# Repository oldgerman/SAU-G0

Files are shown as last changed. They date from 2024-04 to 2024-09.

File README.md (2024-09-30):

## SAU-G0

> 某存在感很弱的屑温湿度计（），美其名曰 Sensor Acquisition Unit（传感器采集单元）

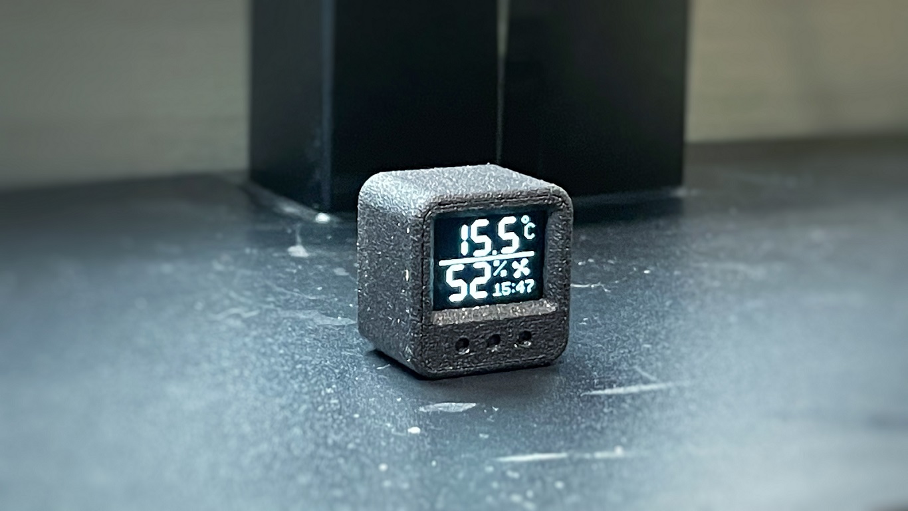
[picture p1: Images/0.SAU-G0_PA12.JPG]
0.SAU-G0_PA12


- [1. 简介](#1-简介)
- [2. 续航](#2-续航)
  - [最低电流](#最低电流)
  - [最高电流](#最高电流)
  - [理论续航时间](#理论续航时间)
- [3. PCB](#3-pcb)
  - [SAU-G0（主控板）](#sau-g0主控板)
  - [SAU-G0-EX_AHT-GL（拓展版-AHT温湿度计-普通级）](#sau-g0-ex_aht-gl拓展版-aht温湿度计-普通级)
  - [SAU-G0-EX_AHT-PL（拓展版-AHT温湿度计-精准级）](#sau-g0-ex_aht-pl拓展版-aht温湿度计-精准级)
  - [SAU-G0-EX_microSD（拓展版-microSD）](#sau-g0-ex_microsd拓展版-microsd)
- [4. 焊接](#4-焊接)
- [5. BOM](#5-bom)
- [6. 软件](#6-软件)
  - [搭建环境](#搭建环境)
  - [功能进度](#功能进度)
  - [BUG fix progress](#bug-fix-progress)
- [7. 烧录](#7-烧录)
  - [ST-LINK](#st-link)
  - [ISP](#isp)
- [8. 成品](#8-成品)
- [9. 数据采集测试](#9-数据采集测试)
- [10. Acknowledgments](#10-acknowledgments)

## 1. 简介

SAU-G0（Sensor Acquisition Uinit（传感器采集单元），基于STM32G031G8U6，是本id学习低功耗的试水作品

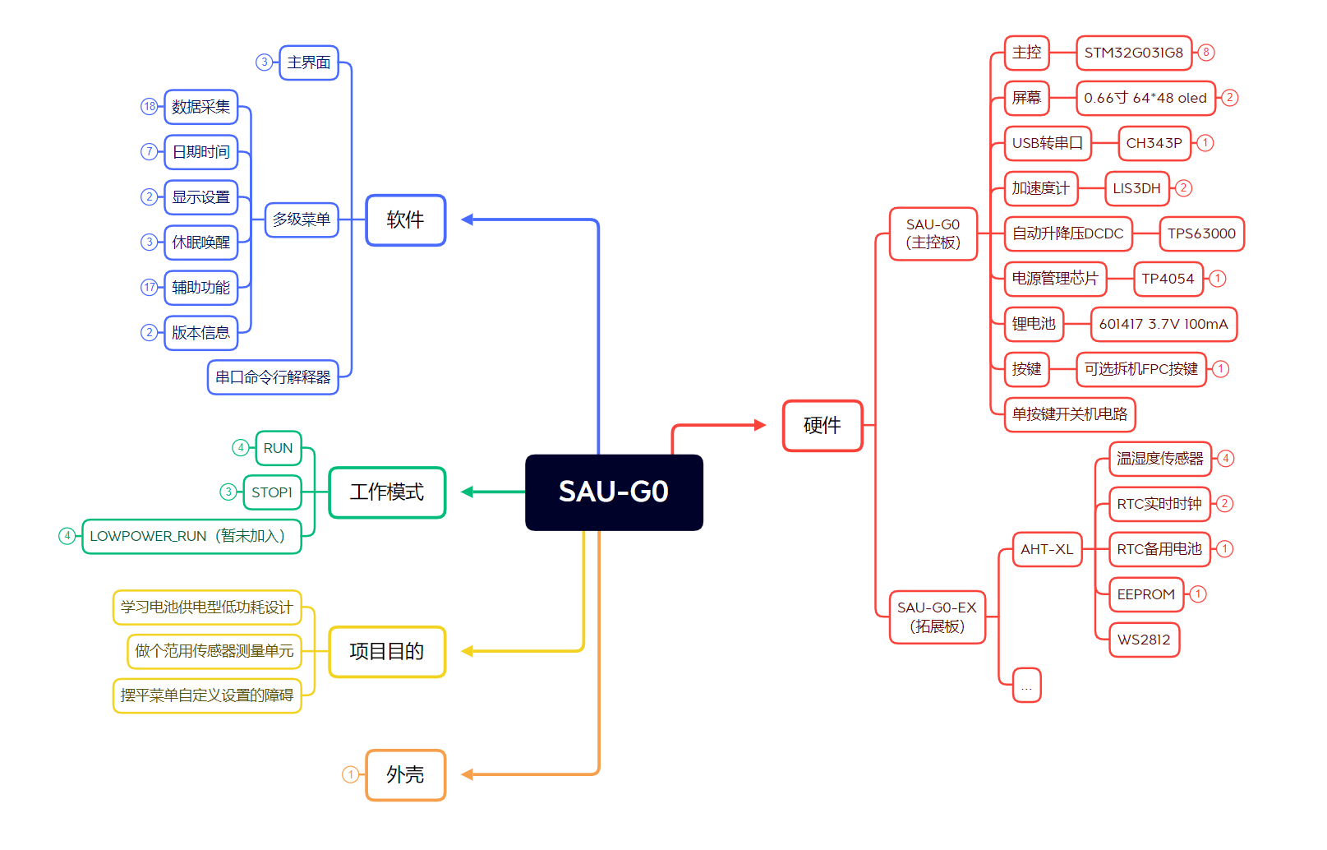
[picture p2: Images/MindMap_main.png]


## 2. 续航

### 最低电流

休眠：约8uA

亮屏运行：约4.0mA（1%屏幕亮度，WS2812不供电）

### 最高电流

最大电流30mA以上（OLED屏幕亮度100%，WS2812两通道LED亮度100%）

### 理论续航时间

使用CubeMX tools工具粗略计算（未引入唤醒瞬间的电流）：1%的时间运行，99%的时间休眠，每天运行864秒（屏幕亮度为1%），其他时间休眠，那么100mA锂电池极限续航2个月7天

如果每10分钟采集温湿度数据一次，每天采集144次，每次5秒，每天耗时720秒，还剩余144秒可支持每天以1%的亮度亮屏2分钟

每组带两位小数的温湿度数据占用4byte（16bit + 16bit），每天储存576byte数据，2个月采集温湿度数据8640组，占用34560byte空间（需使用24C512 EEPROM（65536byte）存储）

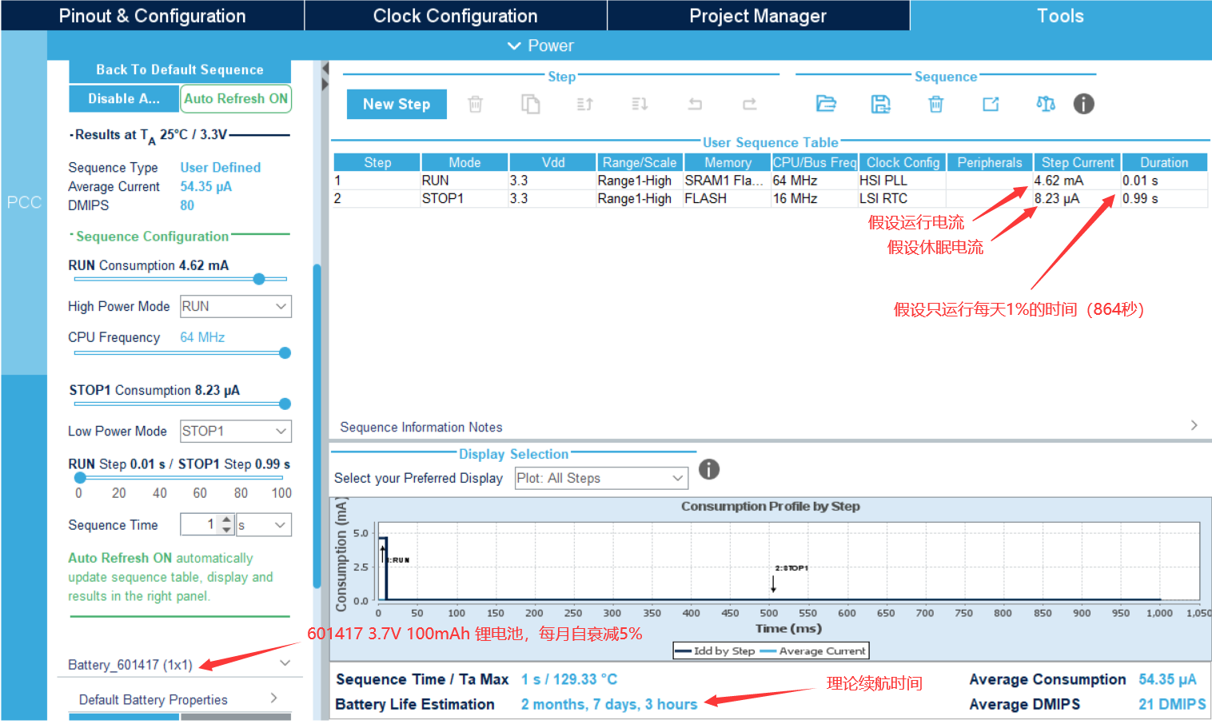
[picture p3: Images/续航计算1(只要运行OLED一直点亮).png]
续航计算1(只要运行OLED一直点亮)


## 3. PCB

> PCB采用叠板设计，分为主控板与拓展板，具体应用取决于拓展板上的传感器和存储芯片，你可以绘制自己的拓展板写驱动程序

### SAU-G0（主控板）

- 硬件：STM32G031G8U6 + CH343P + LIS3DH + TPS63000 / TPS63001 + TP4054 / MCP73831-2ATI/OT

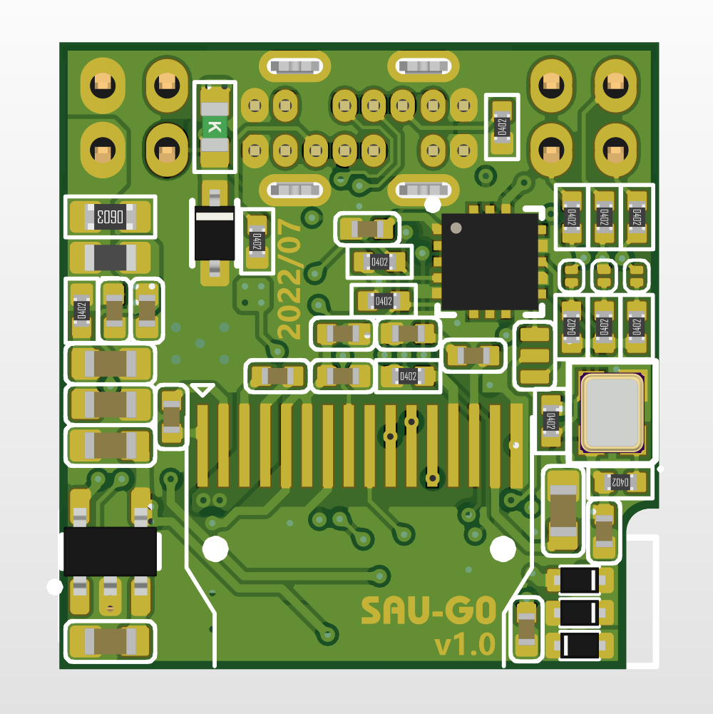
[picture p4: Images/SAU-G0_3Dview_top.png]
SAU-G0_3Dview_top
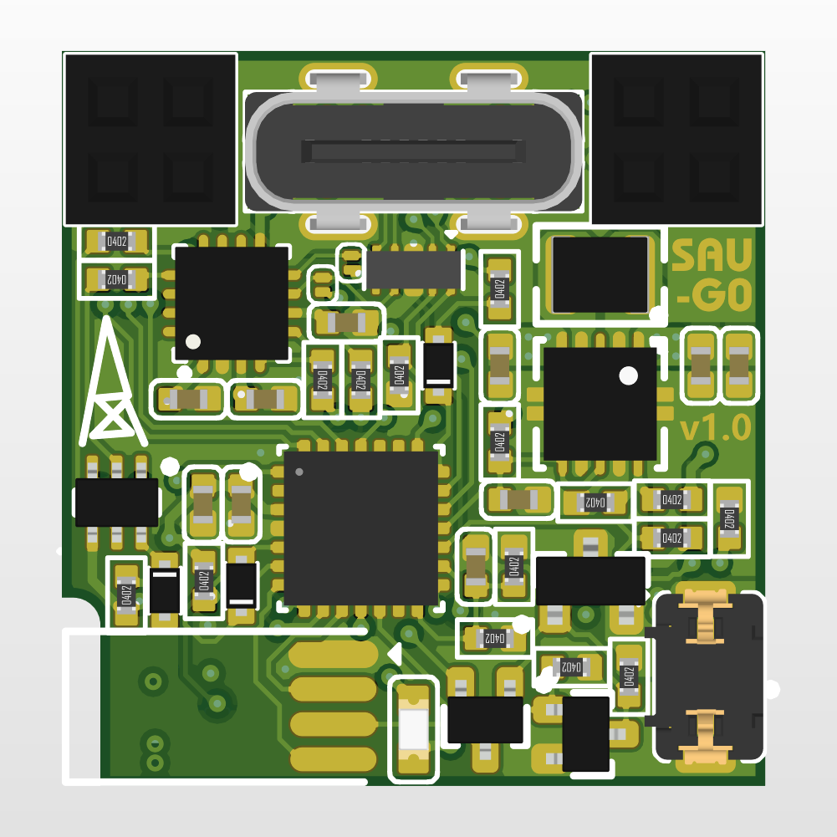
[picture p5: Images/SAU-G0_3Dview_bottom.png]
SAU-G0_3Dview_bottom
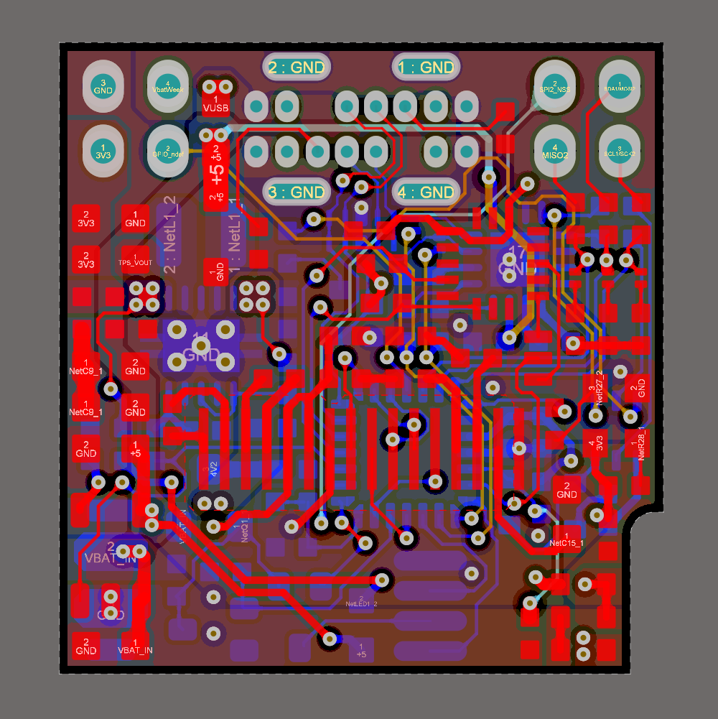
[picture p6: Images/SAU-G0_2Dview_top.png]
|  |  |  |
| --- | --- | --- |

- USB：由于只有一个Type-C，且休眠时（STOP1模式）固件没有禁用SWD接口功能（为了防止变砖，虽然STOP1模式用不了SWD），实测如果SWD接口用排阻连CH343的D+和D-会消耗200uA以上的电流，所以Type-C采用正反插不同功能，正插G031的SWD接口用于调试，反插USB转TTL串口，这样既保留功能也避免了电流泄露
- 串口芯片：可选焊接板载的CH343P，若想外接串口芯片节约成本，可焊接上图CH343P右边的两个焊接跳线，那么G031的USART2就与Type-C直连了
- 有源晶振：默认不焊接，使用内部振荡器，预留给更高精度的时钟应用，例如不使用拓展板的外置RTC，而使用G031内部的RTC，时钟源使用外部32.768Khz有源晶振

### SAU-G0-EX_AHT-GL（拓展板-AHT温湿度计-普通级）

- 硬件：AHT20 + 24Cxx + PCF8563 + WS2812

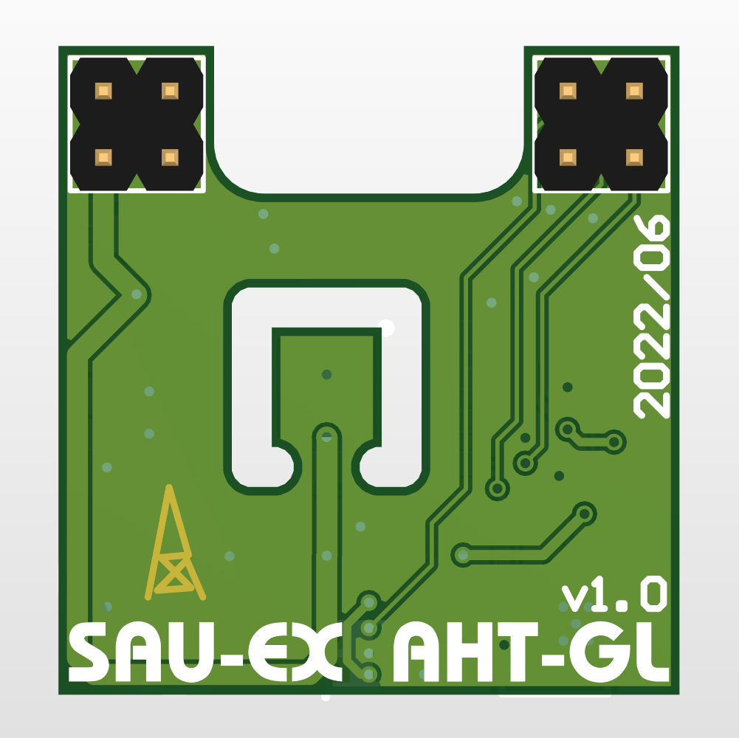
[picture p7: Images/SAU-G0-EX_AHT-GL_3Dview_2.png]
SAU-G0-EX_AHT-GL_3Dview_2
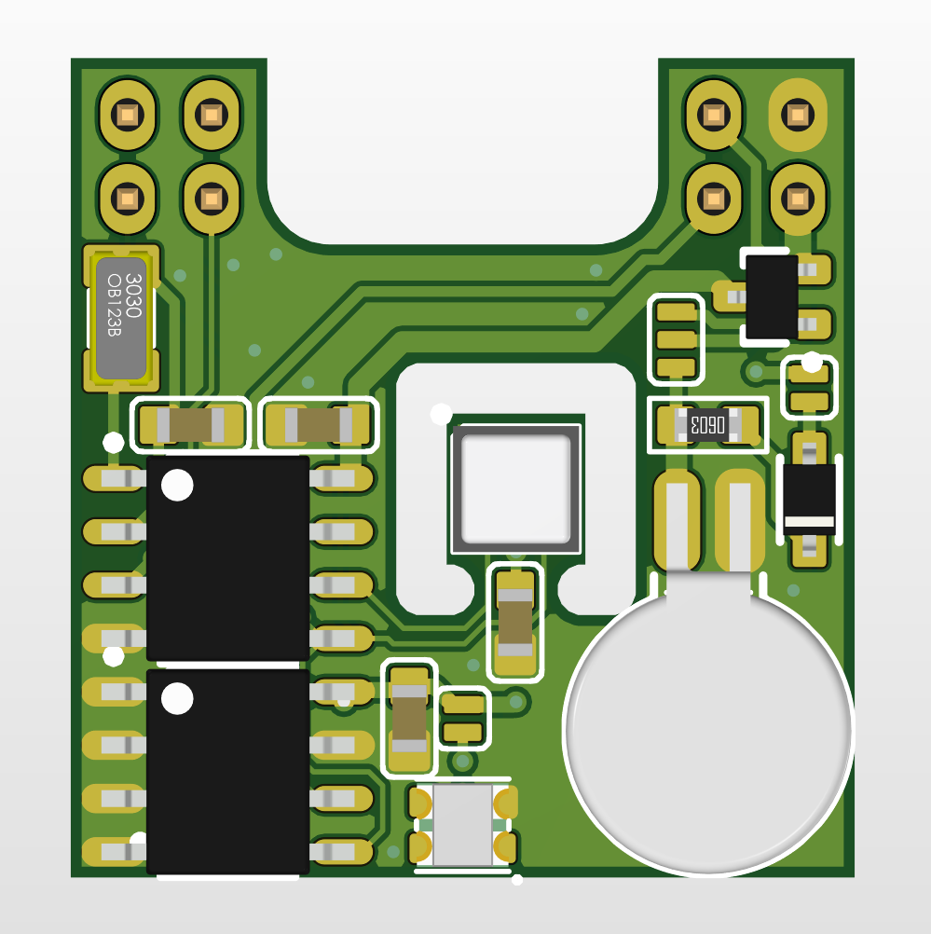
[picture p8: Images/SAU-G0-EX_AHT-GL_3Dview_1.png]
SAU-G0-EX_AHT-GL_3Dview_1
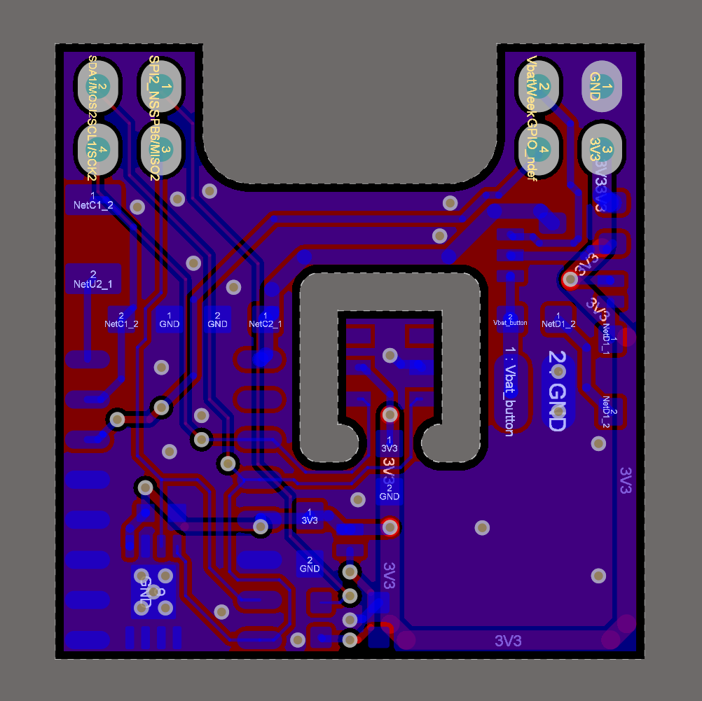
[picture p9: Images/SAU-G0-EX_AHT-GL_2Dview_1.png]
SAU-G0-EX_AHT-GL_2Dview_1
|  |  |  |
| --- | --- | --- |

### SAU-G0-EX_AHT-PL（拓展板-AHT温湿度计-精准级）

- 硬件：AHT20 + 24Cxx + PCF2129 + WS2812

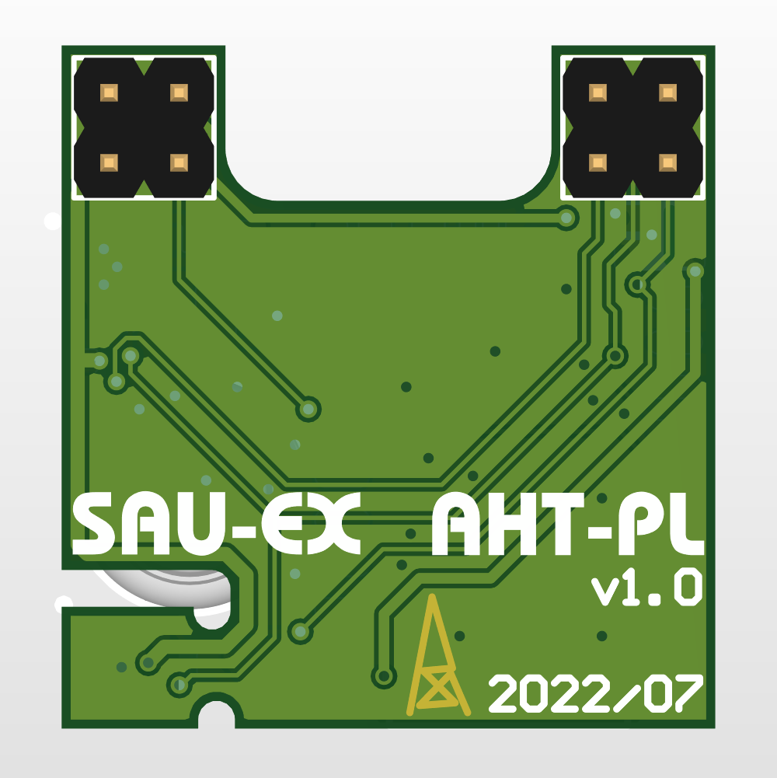
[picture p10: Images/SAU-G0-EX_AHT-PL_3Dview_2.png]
SAU-G0-EX_AHT-PL_3Dview_2
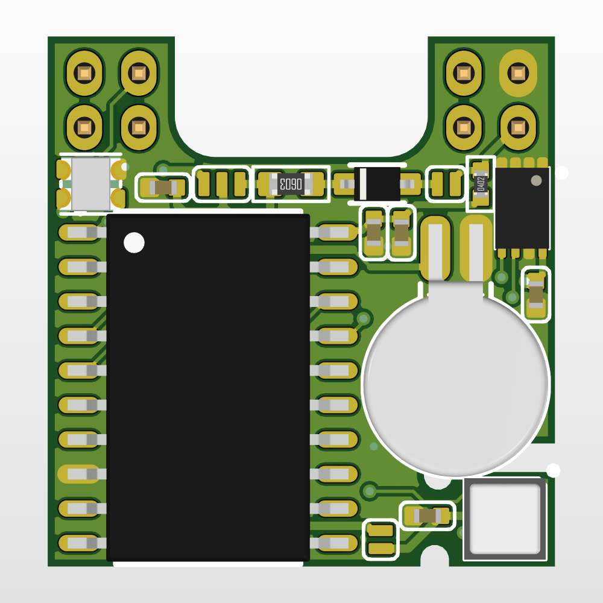
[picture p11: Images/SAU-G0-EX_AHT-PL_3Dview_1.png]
SAU-G0-EX_AHT-PL_3Dview_1
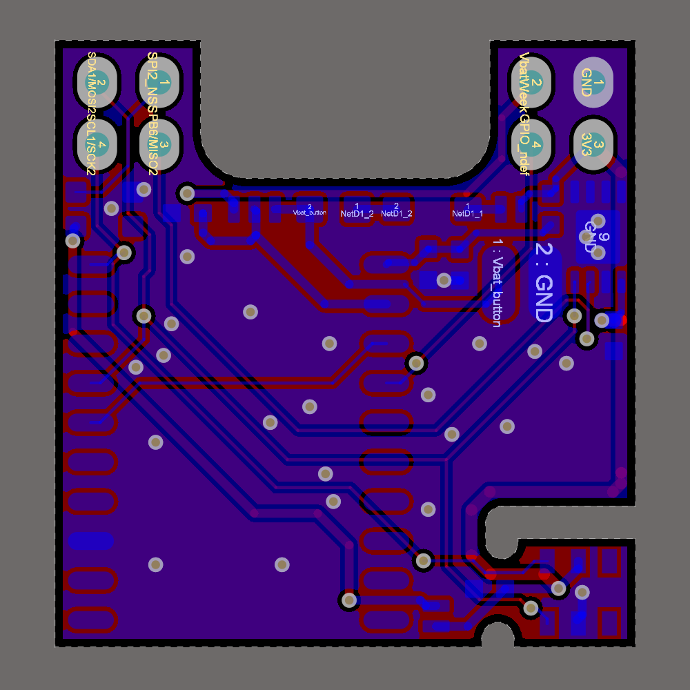
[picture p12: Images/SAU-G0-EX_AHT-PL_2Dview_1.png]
SAU-G0-EX_AHT-PL_2Dview_1
|  |  |  |
| --- | --- | --- |

### SAU-G0-EX_microSD（拓展板-microSD）

- 硬件：microSD卡或NOR Flash + 12mm蜂鸣片
- 备注：无传感器和RTC芯片，整活儿专用，目前暂未写固件

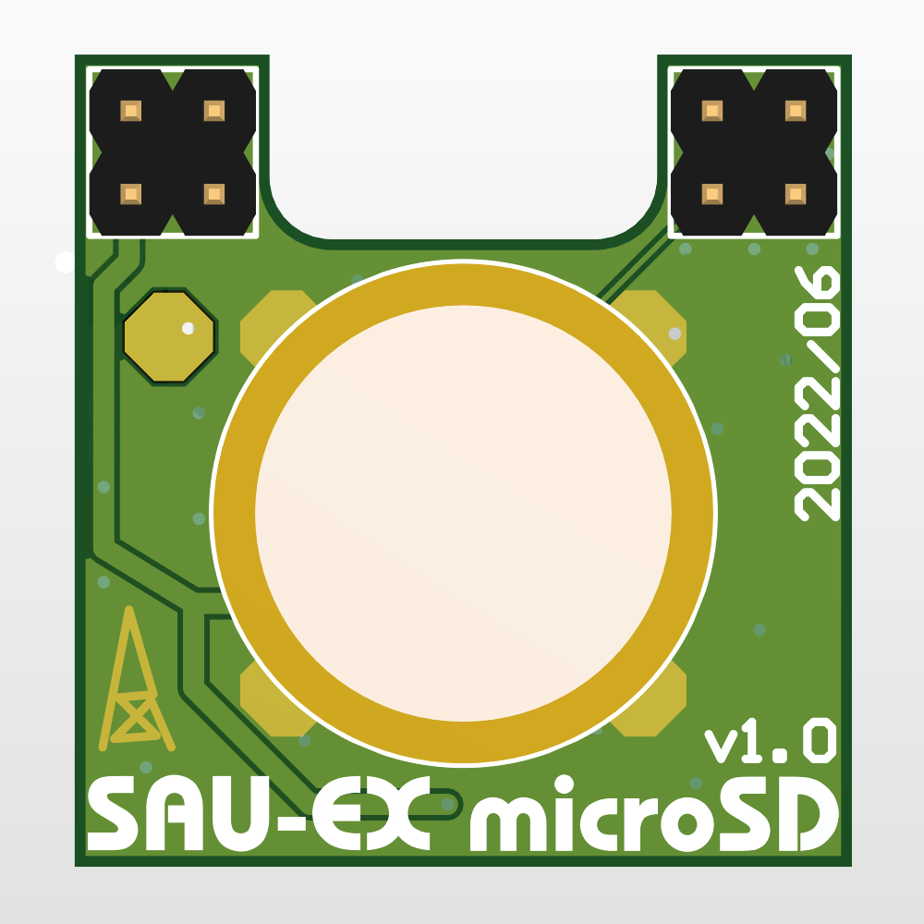
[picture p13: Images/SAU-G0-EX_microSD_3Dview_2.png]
SAU-G0-EX_microSD_3Dview_2
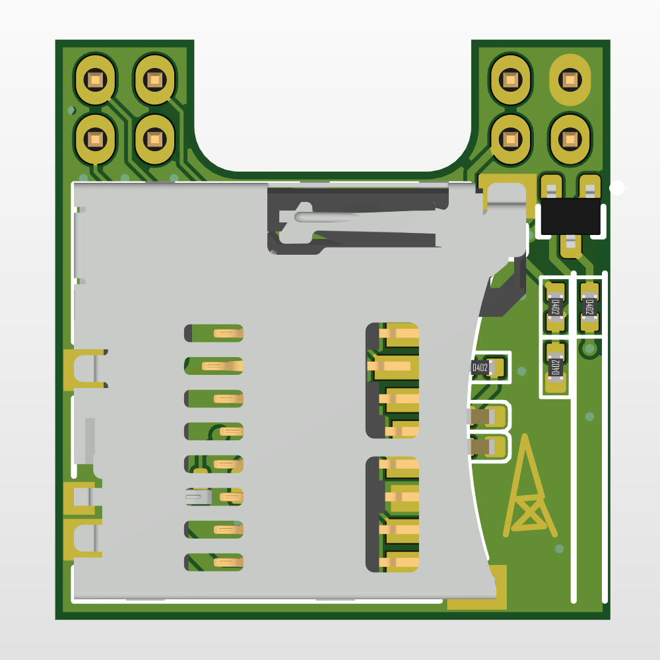
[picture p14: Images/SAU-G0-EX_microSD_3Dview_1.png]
SAU-G0-EX_microSD_3Dview_1
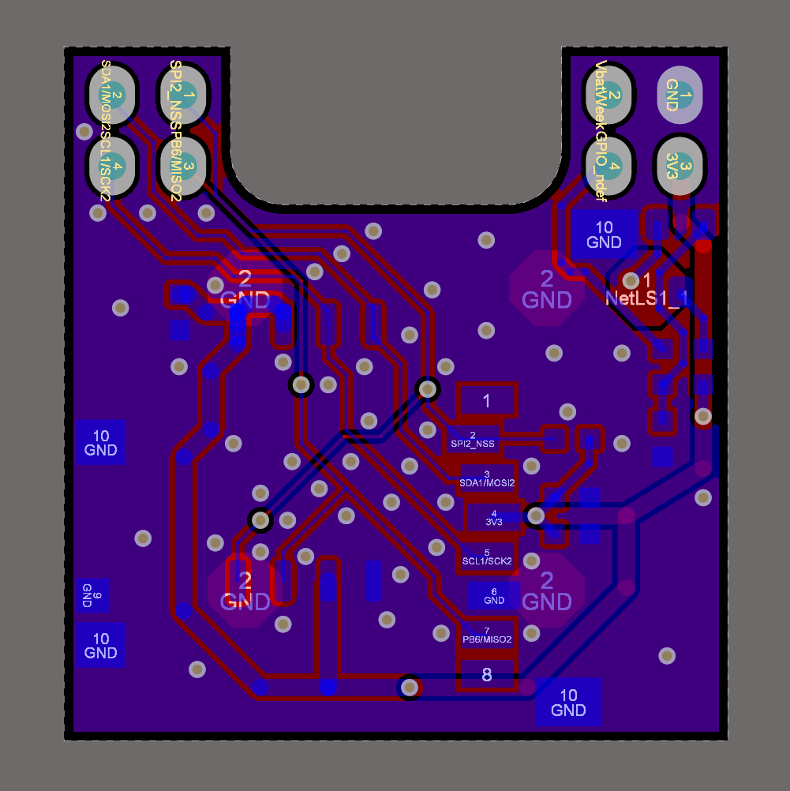
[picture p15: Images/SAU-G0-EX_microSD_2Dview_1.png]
SAU-G0-EX_microSD_2Dview_1
|  |  |  |
| --- | --- | --- |

## 4. 焊接

SAU-G0主控单元有80多个元件，元件很密集（0402、扁平无引脚封装），十分建议开钢网

## 5. BOM

交互BOM，浏览器打开即可

路径：每一个AD工程目录下的 BOM/bom

电容耐压：OLED外围电路的几个电容标注了耐压要求，其他的电容默认10V耐压或以上

电池型号：601417 3.7V 100mAh

电池连接器：非必须，可以直接焊线

EEPROM：程序实现了容量 2Kbit-1024Kbit 自适应，推荐24C512

**OLED屏幕和FPC按键需要从豆总1.6元电子烟主板车上拆**（没有这个，但想DIY的朋友可以私信我给你寄）

## 6. 软件

### 搭建环境

打包的STM32CubeIDE1.7.0工程，需要先安装暗黑主题（[教程](https://blog.csdn.net/qq_42038029/article/details/99735688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)），然后随便编译/折腾

### 功能进度

目前固件已完成对AHT-GL和AHT-PL拓展板适配

- [x] 屏幕渐亮渐暗
- [x] 串口修改时间
- [x] 串口导出EEPROM储存的采集数据
- [x] 多级菜单
- [x] 自定义采集温湿度任务，自动计算任务数据存储空间
- [x] 自动检测EEPROM容量：已测试24C02、24C64、24C128、24C512
- [x] 休眠：支持RTC、加速度计、按键三种方式唤醒
- [ ] 串口命令解释器
- [ ] 硬件看门狗
- [ ] 熄屏采集逻辑

### BUG fix progress

- [ ] 硬复位时，检测EEPROM概率出现检测容量为0
- [ ] 唤醒时概率死机

## 7. 烧录

编译好的固件：[Hex](https://github.com/oldgerman/SAU-G0/tree/master/SoftWare/Hex)

Type-C采用正反插不同功能，正插G031的SWD接口用于调试，反插USB转TTL串口

烧录时需要全程按住按钮中键不放以保持上电

### ST-LINK

Type-C 正插连接即可烧录

### ISP

板载一键下载电路，Type-C 反插连接

STM32G031G8U6出厂时option bytes默认BOOT0信号由option byte决定，**ISP烧录前，必须先使用STLINK以SWD连G031修改option bytes的nBOOT_SEL位为取消勾选，否则后续CH343P的RTS和DTR无法将G031设置为IPS模式！！！**

需要FlyMCU和开STM32CubeProgrammer 配合烧录

**按住OK键保持不放**，FlyMCU选择 **RTS低电平DTR高电平进BooTloader**，显示已连接后（FlyMCU无法对G0进行进一步操作），**即可松开OK键**，然后打开STM32CubeProgrammer（FlyMCU可不关闭，另外新版STM32CubeProgrammer ，会有RTS和DTR选项，都选择0）以 UART **波特率115200** 连接，如果一切顺利，即可进入烧录状态

你可能会问为啥不直接用STM32CubeProgrammer操作DTR和RTS而要用FlyMCU操作，因为这个功能我测试对于一键下载电路不起作用，DTR和RTS信号的波形很奇怪，但是FlyMCU可以

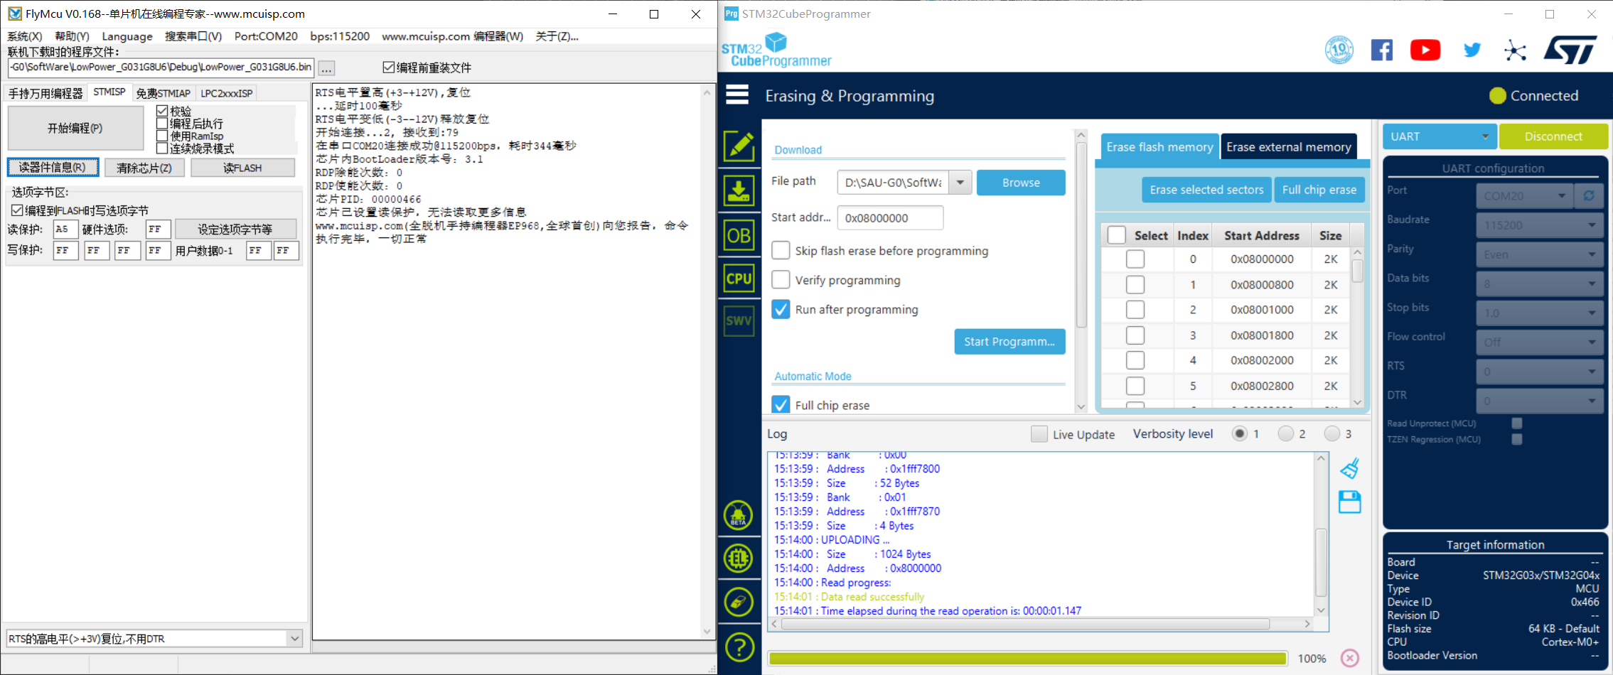
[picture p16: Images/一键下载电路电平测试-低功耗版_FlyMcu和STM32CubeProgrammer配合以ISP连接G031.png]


## 8. 成品

### 外壳

- STL模型路径：[SAU-G0/Hardware/SW_Project/STL_OUT](https://github.com/oldgerman/SAU-G0/tree/master/Hardware/SW_Project/STL_OUT)

不同的打印方式需要使用不同的打印模型：

- FDM打印：上盖和盒子得分两个件打印，模型文件使用 **单个零件**
- 树脂光固化、尼龙激光烧结打印：盖子和盒子可合并成一个模型打印，模型文件使用 **连接零件**
- STL文件名解释：**GL**是使用PCF8563扩展板的，**PL**是使用PCF2129扩展板的

PA12打印的外壳组装后效果：

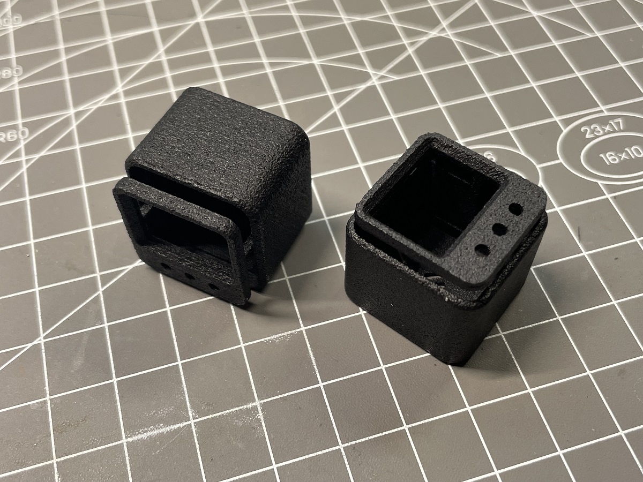
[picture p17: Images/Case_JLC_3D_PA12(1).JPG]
Case_JLC_3D_PA12(1)
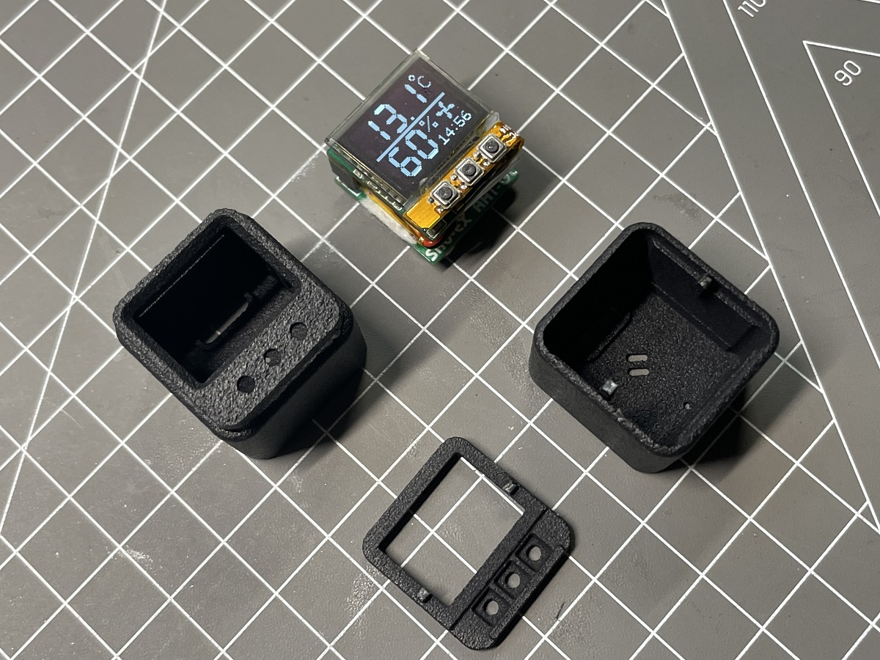
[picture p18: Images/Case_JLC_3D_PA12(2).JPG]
Case_JLC_3D_PA12(2)
|  |  |
| --- | :--- |
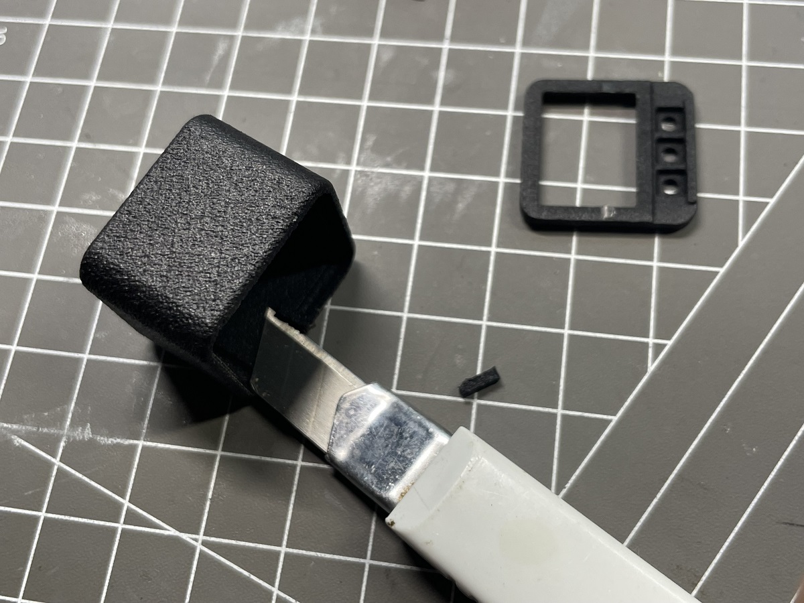
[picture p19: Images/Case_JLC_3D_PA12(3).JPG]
Case_JLC_3D_PA12(3)
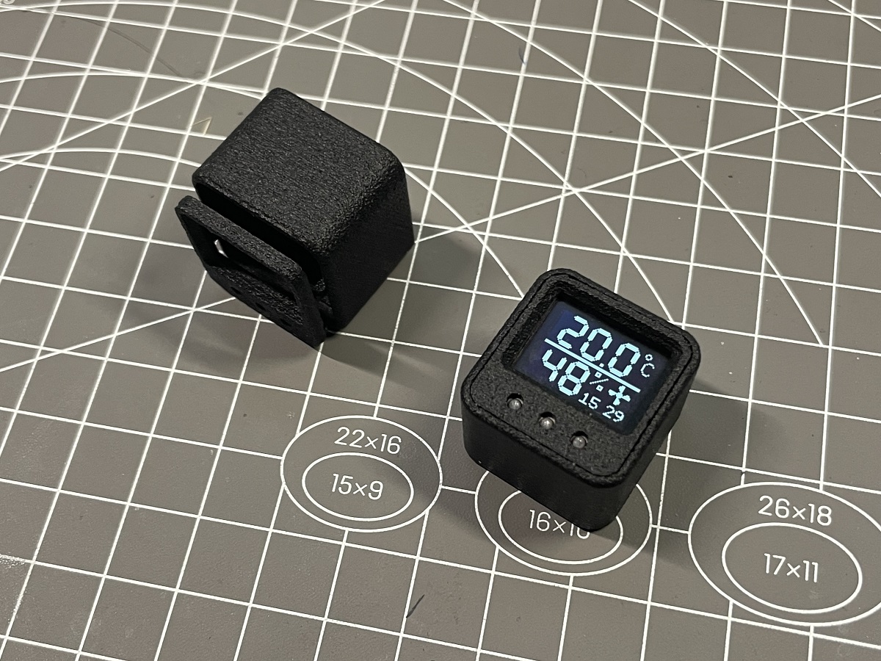
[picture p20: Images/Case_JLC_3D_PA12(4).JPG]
Case_JLC_3D_PA12(4)
|  |  |

### 裸板

SAU-G0-EX_AHT-GL 初号机，AHT20 周边忘记开槽了：

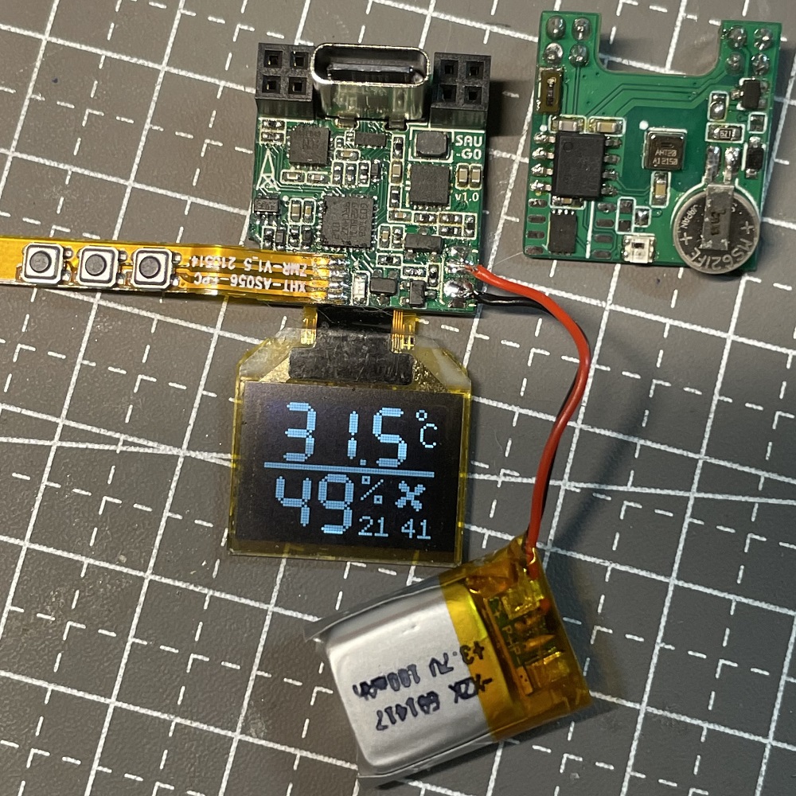
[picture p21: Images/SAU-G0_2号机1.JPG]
SAU-G0_2号机1
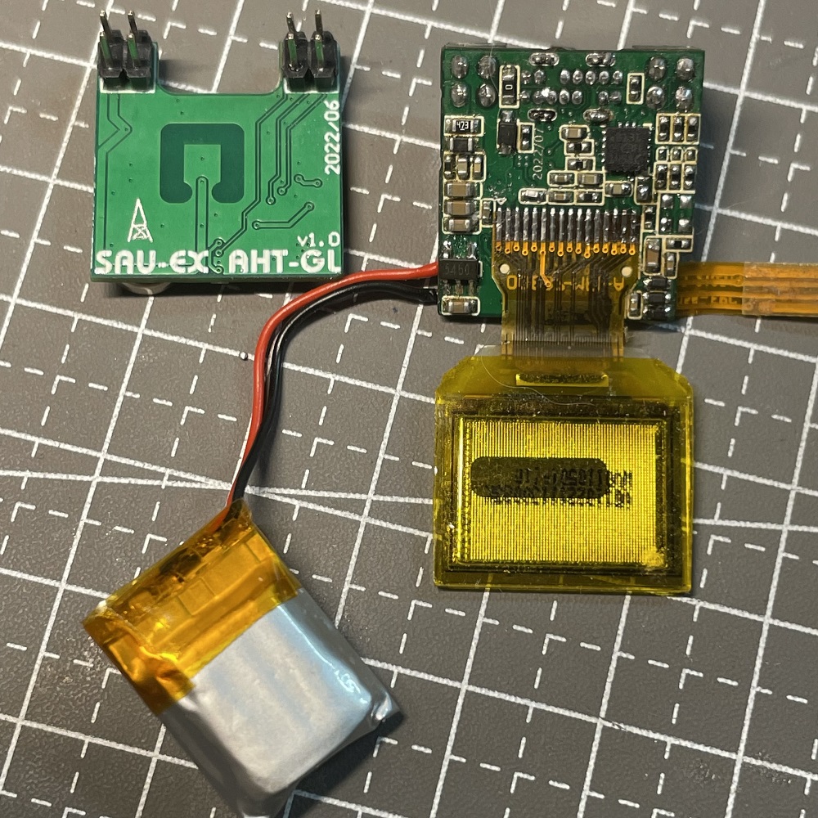
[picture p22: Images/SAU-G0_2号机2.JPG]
|  |  |
| --- | --- |

后续制作的 SAU-G0-EX_AHT-GL 和 SAU-G0-EX_AHT-PL：

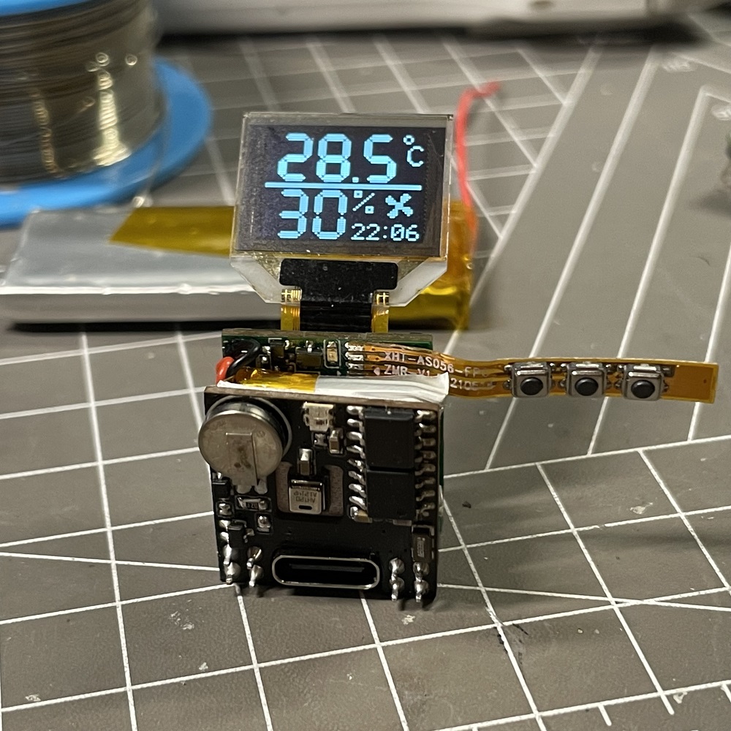
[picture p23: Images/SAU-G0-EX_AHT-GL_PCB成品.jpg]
SAU-G0-EX_AHT-GL_PCB成品
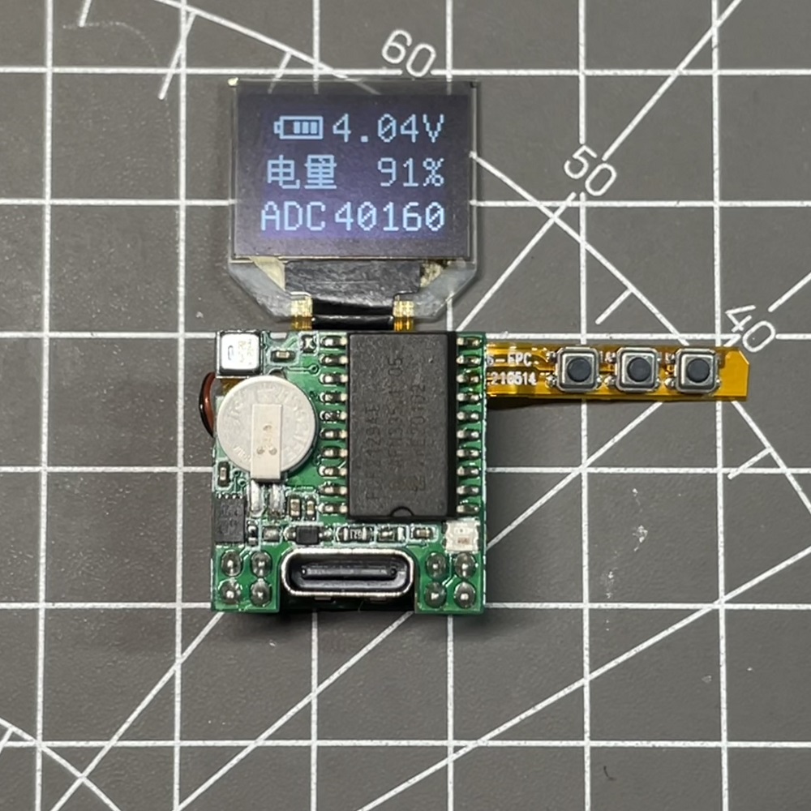
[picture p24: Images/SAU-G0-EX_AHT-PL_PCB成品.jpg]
SAU-G0-EX_AHT-PL_PCB成品
|  |  |
| --- | --- |

## 9. BUG

### 死机

运行时，或唤醒时，都可能死机（概率极小），死机时，找一根USB线一端接5V，另一端 Type-C 反插连接温湿度计，然后拔出Type-C，即可复位STM32G031

### 串口导出的文本表格的格式不对

（待修复）串口导出的文本表格的格式不对，markdown表格记成csv格式，是说咋导入谷歌表格识别不了

### 扩展版

扩展板的纽扣电池保持开机亮屏才能从3V3充电，休眠或关机时无法充电，若太长时间不持续亮屏充电，由于RTC芯片持续消耗纽扣电池的能量，纽扣电池会过放电到0V

临时解决方案，例如 SAU-G0-EX_AHT-PL 扩展板，断开 SJ1跳线，将D1右端飞线到SJ2跳线的VbatWeek，这样后，即使关机了，锂电池还能经VbatWeek持续给纽扣电池充电

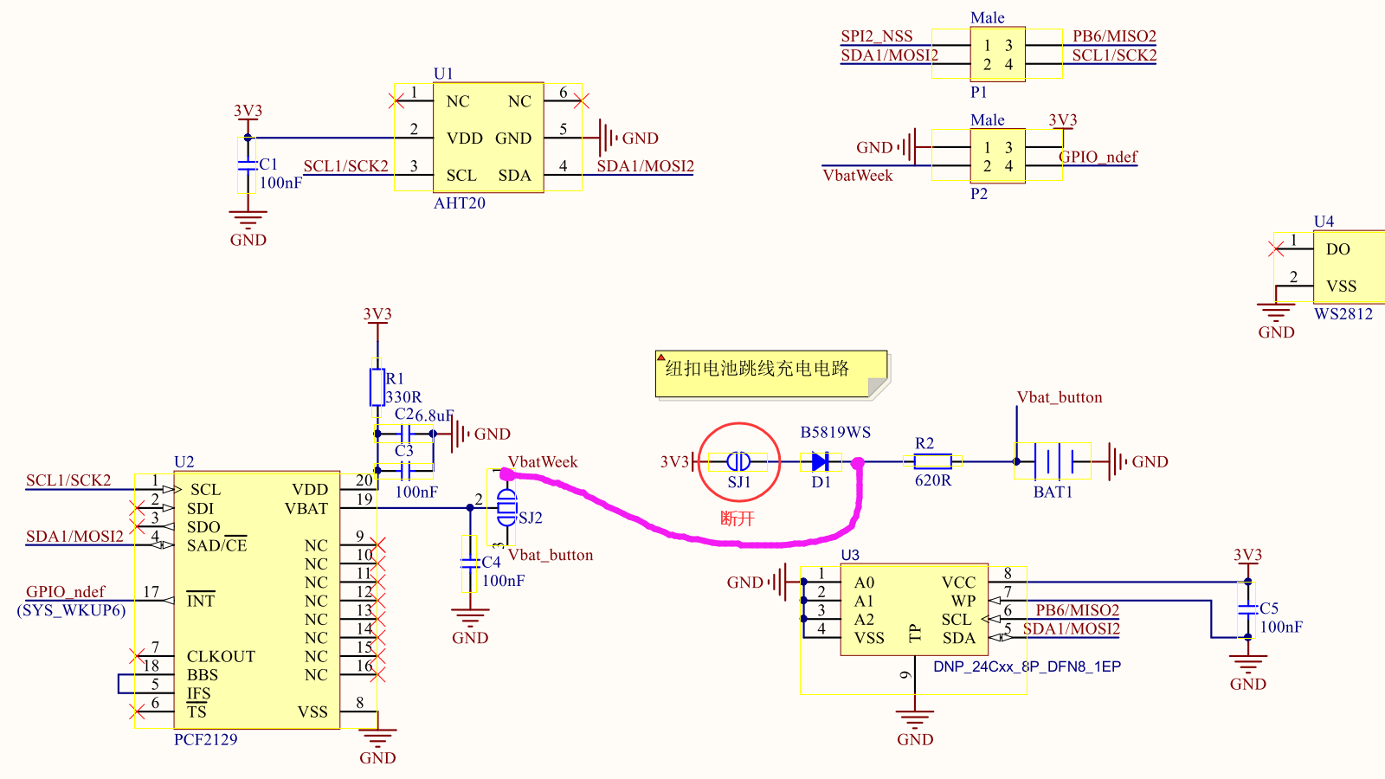
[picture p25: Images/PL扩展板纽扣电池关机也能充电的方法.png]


VbatWeek是从主板的锂电池经BAV99两个硅二极管降压取电的，压降1.1V左右。那么当主板的锂电池充满电时，即锂电池电压4.2V时，VbatWeek约3.1V，纽扣电池约3V，此时VbatWeek高于纽扣电池的电压时，RTC由VbatWeek供电（主板锂电池供电），而当锂电池低于4.1V时，纽扣电池的电压就会比VbatWeek高，RTC由纽扣电池供电，若熄屏时间太久没有唤醒，那么纽扣电池的电量会被RTC芯片持续消耗，可能出现纽扣电池的电压再次低于VbatWeek，那么纽扣电池又会充电

纽扣电池100%电量时电压约3V，0%电量时电压约2.0V，当纽扣电池低于2V时，主板锂电池也差不多低于3V触发锂电池保护板的过放电保护了，这个时候用户也会发现差不多没电了，需要充电

总之，纽扣电池和VbatWeek是通过二极管进行相互交替给RTC芯片供电的，在大多数情况下，当主板锂电池没电时，纽扣电池还能维持RTC芯片正常运转（MS621FE纽扣电池约5.5mAh，能维持RTC芯片（PCF2129：0.7uA）300天）

| 锂电池4.21V时，3.3V给纽扣电池充电，充满时纽扣电池的电压 | 锂电池4.20V时，VbatWeek的电压 |
| --- | --- |
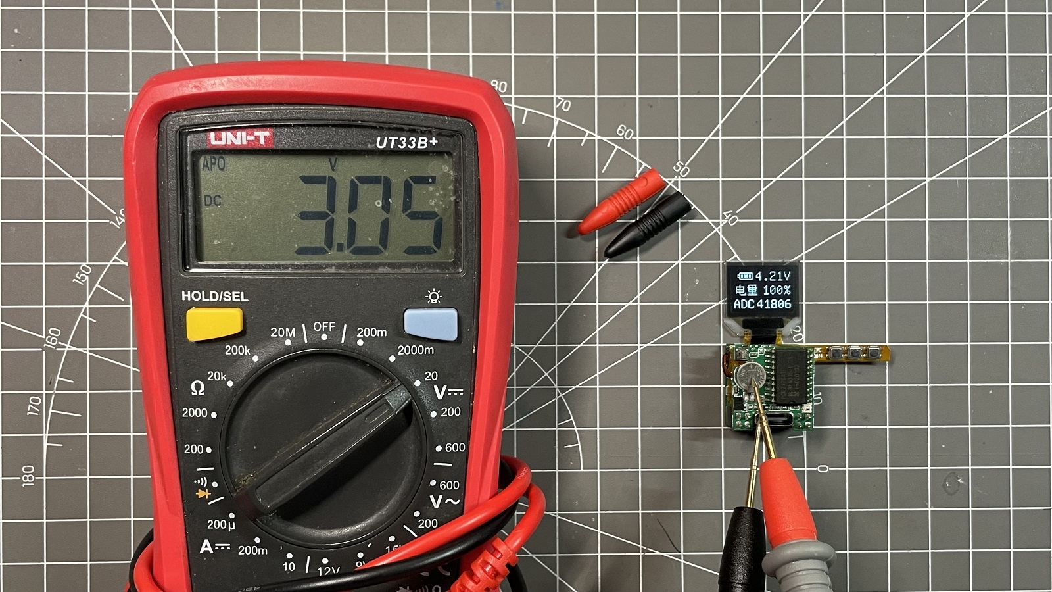
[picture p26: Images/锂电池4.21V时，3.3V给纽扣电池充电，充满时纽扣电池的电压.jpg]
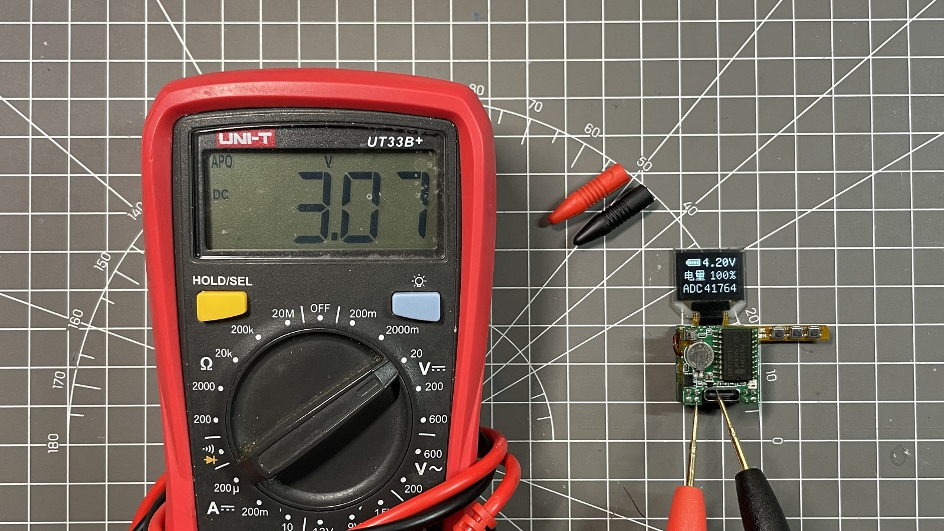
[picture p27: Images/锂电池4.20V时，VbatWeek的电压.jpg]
|  |  |

后续有空就改一下PCB扩展版修这个电路BUG，如果我没有改，你也可以自己修改源文件

## 10. 数据采集测试

使用XCOM，连接串口黑屏就勾选RTS，再长按中键连接

菜单-->数据采集-->导出数据，文本表格格式为 csv 格式，数据以逗号分割，在XCOM里导出选中，复制，新建一个 .csv文件，粘贴进去，就可以用 Excel 或者 Google Sheets （谷歌表格） 处理

> 格式如下：
>
> ```c
> Date & Time        , T(C) , H(%)
> 2024/09/30 17:22:00, 31.90 ,51.00
> 2024/09/30 17:22:10, 31.90 ,49.00
> 2024/09/30 17:22:20, 31.80 ,40.00
> 2024/09/30 17:22:30, 31.70 ,44.00
> 2024/09/30 17:22:40, 31.70 ,44.00
> ```

例如，使用[谷歌表格](https://docs.google.com/spreadsheets/create?hl=zh-cn)，上传 csv 文件后，对列进行少许的格式化，得到折线图

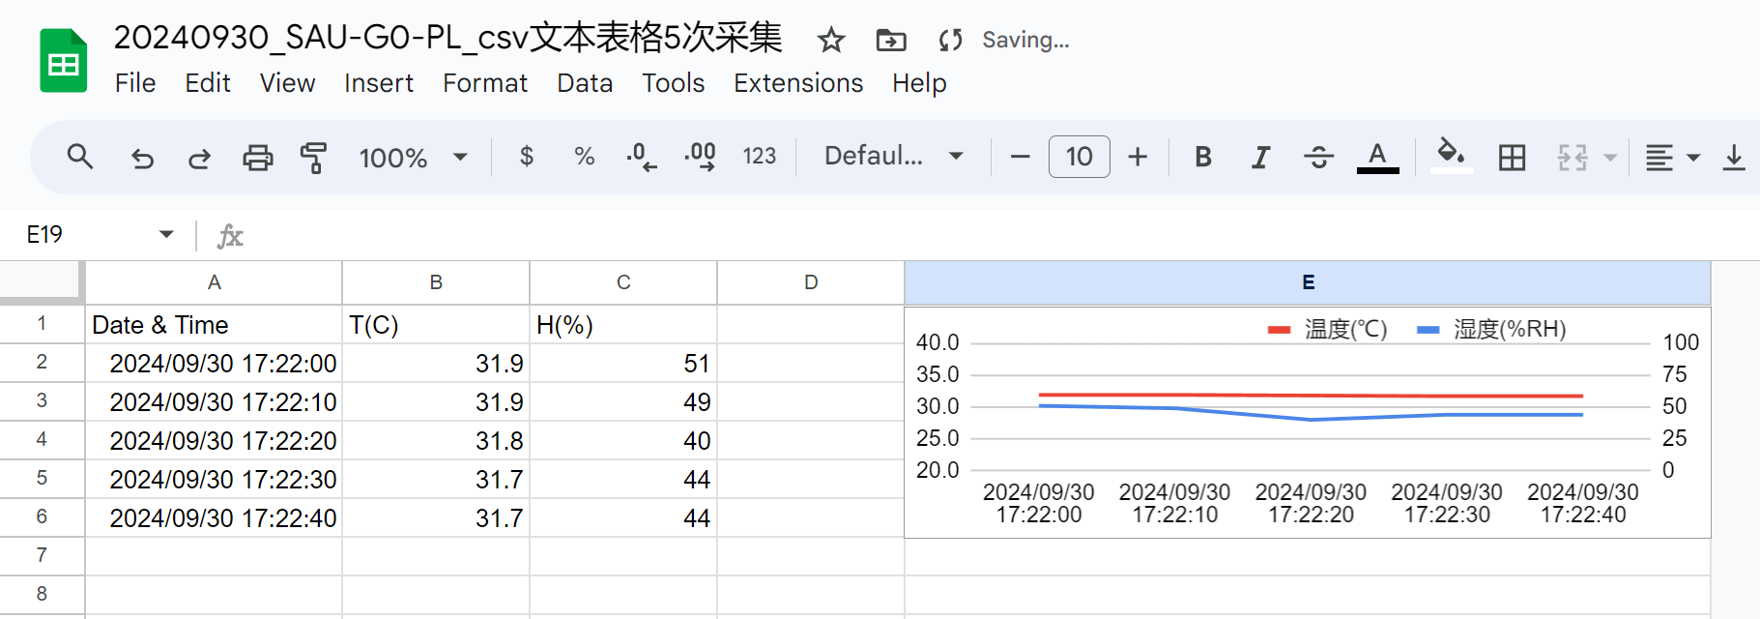
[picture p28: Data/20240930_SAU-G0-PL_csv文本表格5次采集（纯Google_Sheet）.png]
20240930_SAU-G0-PL_csv文本表格5次采集（纯Google_Sheet）


采集数据的示例Excel文件位于[Data](https://github.com/oldgerman/SAU-G0/tree/master/Data)文件夹

[谷歌表格绘制折线图技巧](https://github.com/oldgerman/SAU-G0/tree/master/Data/谷歌表格绘制折线图技巧.md)

### 测试1：24小时1200+次采集

屏幕亮度90%，开启自动休眠，设置任务后，由RTC闹钟唤醒亮屏4秒，采集一次温湿度，数据保存在EEPROM，然后熄屏进入低功耗模式

在24小时如此反复约1200次，锂电池电压从4.2V降到4.0V，耗电约15%

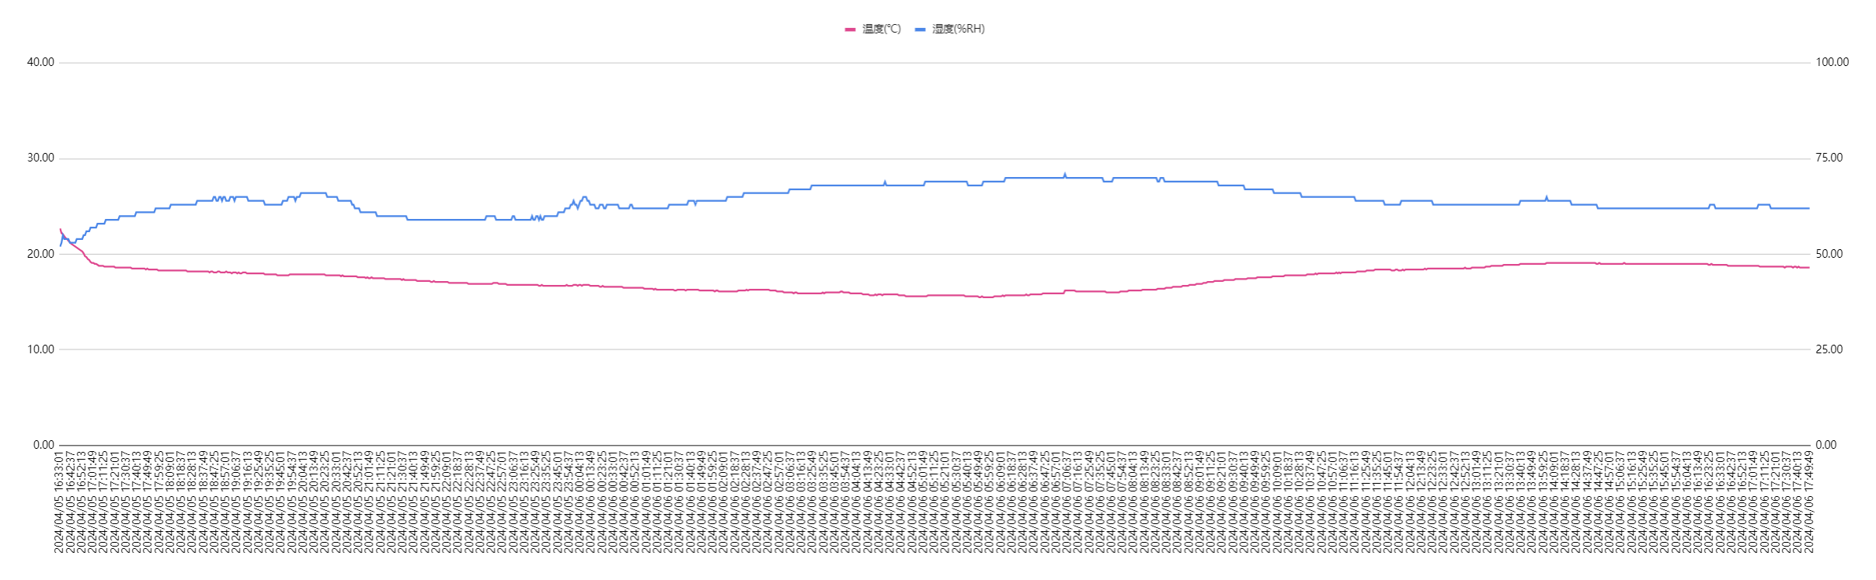
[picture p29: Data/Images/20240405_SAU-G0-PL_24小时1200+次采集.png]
20240405_SAU-G0-PL_24小时1200+次采集


左侧为温度标尺，右侧为湿度标尺，横轴为时间点（横轴无法显示完全1200个时间标签）

### 测试2：38天1800+次采集

屏幕亮度50%，开启自动休眠，设置任务后，由RTC闹钟唤醒亮屏5秒，采集一次温湿度，数据保存在EEPROM，然后熄屏进入低功耗模式

在38天如此反复约1800次（每天48次），锂电池电压从4.25V降到4.00V，耗电约20%

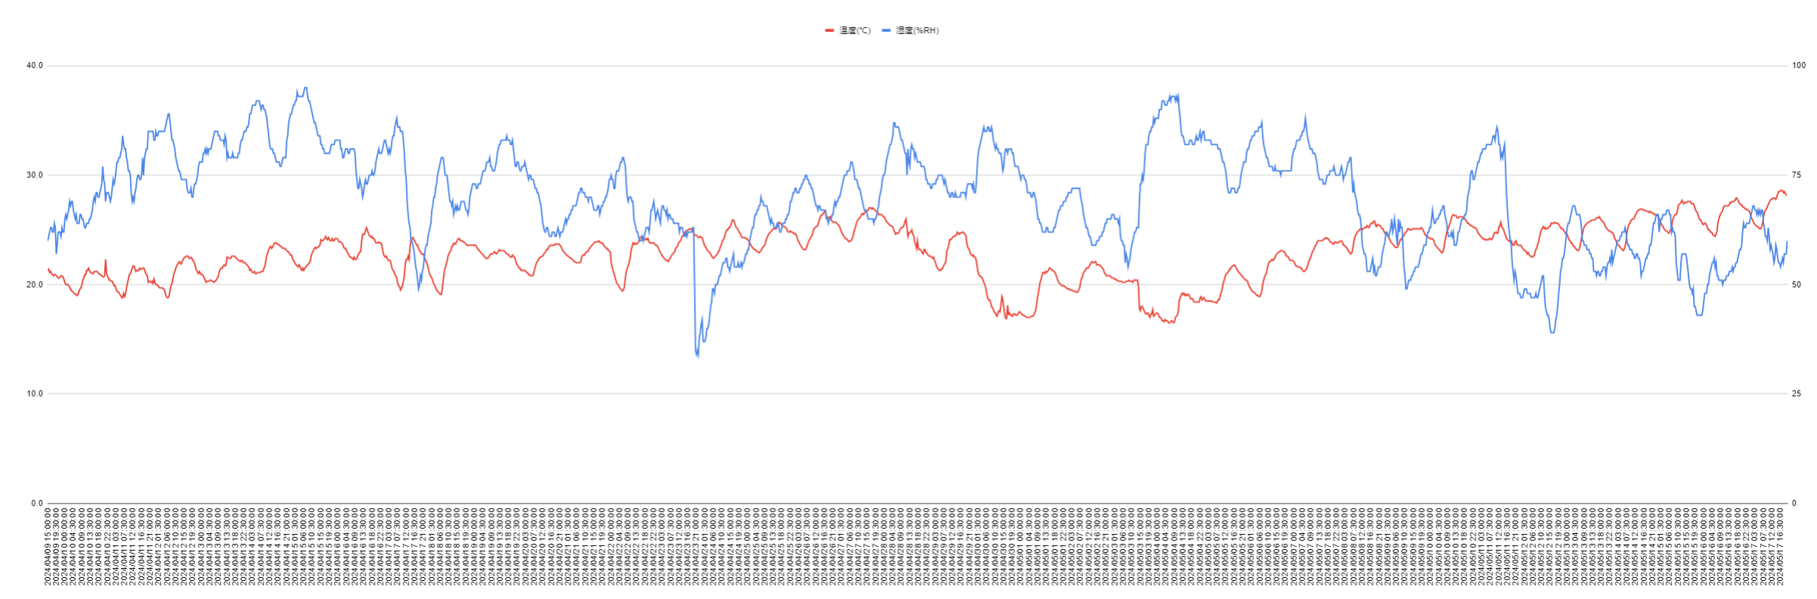
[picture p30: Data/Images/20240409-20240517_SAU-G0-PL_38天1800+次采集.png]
20240409-20240517_SAU-G0-PL_38天1800+次采集


## 11.待开发

1. 加入默认任务模板：年采集，月采集，周采集
2. 这货要是flash再大点，可以整个串口命令进行报表查询

## 12. Acknowledgments

- 感谢[豆老板](https://oshwhub.com/red_bean)谈下1.6元电子烟主板车车
- 感谢 [JLC](https://www.jlc.com/) 制造的高品质 PCB
- 感谢稚晖 [Planck-Pi](https://github.com/peng-zhihui/Planck-Pi) 的 Type-C 正反插两用的灵感

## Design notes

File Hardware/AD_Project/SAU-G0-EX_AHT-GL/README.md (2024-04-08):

## SAU-G0-EX_AHT-GL

本目录为 SAU-G0-EX_AHT-GL 工程文件

工艺：

板厚1.0mm，双面板，过孔0.3/0.5mm，最小线宽线隙5mil

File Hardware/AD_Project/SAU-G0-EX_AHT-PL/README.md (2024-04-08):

## SAU-G0-EX_AHT-PL

本目录为 SAU-G0-EX_AHT-PL 工程文件

工艺：

板厚1.0mm，双面板，过孔0.3/0.5mm，最小线宽线隙5mil

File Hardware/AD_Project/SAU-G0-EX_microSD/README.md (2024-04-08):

## SAU-G0-EX_microSD

本目录为 SAU-G0-EX_microSD 工程文件

工艺：

板厚1.0mm，双面板，过孔0.3/0.5mm，最小线宽线隙5mil

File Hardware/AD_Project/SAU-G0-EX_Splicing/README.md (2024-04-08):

## SAU-G0-EX_Splicing

本目录为PCB拼板工程文件

目前已拼：

- 垫高板x2
- SAU-G0-EX_AHT-PL
- SAU-G0-EX_microSD
- SAU-G0-EX_AHT-GL

工艺：

板厚1.0mm，双面板，过孔0.3/0.5mm，最小线宽线隙5mil

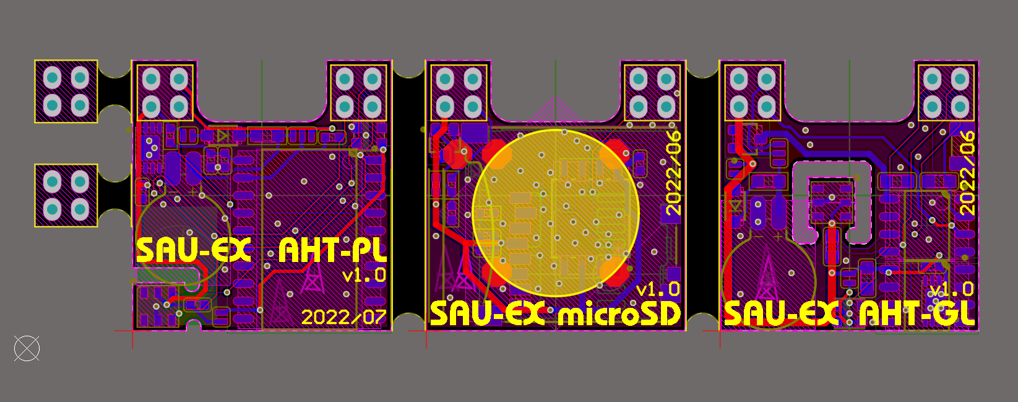
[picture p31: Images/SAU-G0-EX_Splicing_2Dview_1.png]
SAU-G0-EX_Splicing_2Dview_1


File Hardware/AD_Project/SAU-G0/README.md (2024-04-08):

## SAU-G0

本目录为SAU-G0主控板的工程文件

工艺：

板厚1.0mm，四层板，过孔0.2/0.45mm，最小线宽线隙4mil

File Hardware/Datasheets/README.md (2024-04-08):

## Datasheets

- 使到的绝大多数芯片的手册可在此找到

- 某些PDF有本人写的注释，请谅解~

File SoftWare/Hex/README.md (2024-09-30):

## Hex版本

### 20230508

- SAU-G031G8U6_Nothing

单独测试主板用（支持OLED、按键、加速度计唤醒、电池电压测量），可以不接扩展板

### 20230509

- SAU-G031G8U6_GL：扩展板是PCF8563用
- SAU-G031G8U6_PL：扩展板是PCF2129用

实现所有基础功能

### 20240407

- SAU-G031G8U6_GL：扩展板是PCF8563用
- SAU-G031G8U6_PL：扩展板是PCF2129用

BUG修复：

- 菜单-->数据采集-->删除任务：进入该页面后，即使按取消，还是会删除任务

修改：

- 菜单-->数据采集-->删除任务：进入该页面后，按确认，删除任务后，菜单-->数据采集-->任务设置-->采集对象-->温度、湿度还是为开启的。菜单-->辅助功能-->恢复出厂，点确认后。采集对象-->温度、湿度还是为开启的，不需要每次都手动开启

### 20240410

BUG修复：

- 菜单-->数据采集-->任务进度：待采数量的计算问题

```c
void columsDataCollected_Schedule(){
...
	drawNumber((OLED_WIDTH - numXOffset) - places * 6, y + 32,
			systemSto.data.NumDataWillCollect - systemSto.data.NumDataCollected.uint_16, places);
...
}
```

### 20240930

- SAU-G031G8U6_GL：扩展板是PCF8563用
- SAU-G031G8U6_PL：扩展板是PCF2129用

修改：

- 菜单-->数据采集-->导出数据，文本表格格式从 markdown 改为 csv 格式，数据以逗号分割，在XCOM里导出选中，复制，新建一个 .csv文件，粘贴进去，就可以用 Excel 或者 Google Sheets 处理

  > 格式如下：
  >
  > ```c
  > Date & Time        , T(C) , H(%)
  > 2024/09/30 17:22:00, 31.90 ,51.00
  > 2024/09/30 17:22:10, 31.90 ,49.00
  > 2024/09/30 17:22:20, 31.80 ,40.00
  > 2024/09/30 17:22:30, 31.70 ,44.00
  > 2024/09/30 17:22:40, 31.70 ,44.00
  > ```

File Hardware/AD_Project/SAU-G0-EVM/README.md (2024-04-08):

## SAU-G0-EVM

本PCB为评估版，G031的引脚、每个芯片电源引脚，都做了跳线设计，可以完全断开，以排查漏电流部分

没有本PCB，要想在SAU-G0主控板约2x2cm的极限尺寸上进行漏电流排查/抓波会非常麻烦

SAU-G0的绝大多数测试都在本PCB上完成验证，可做学习板之用

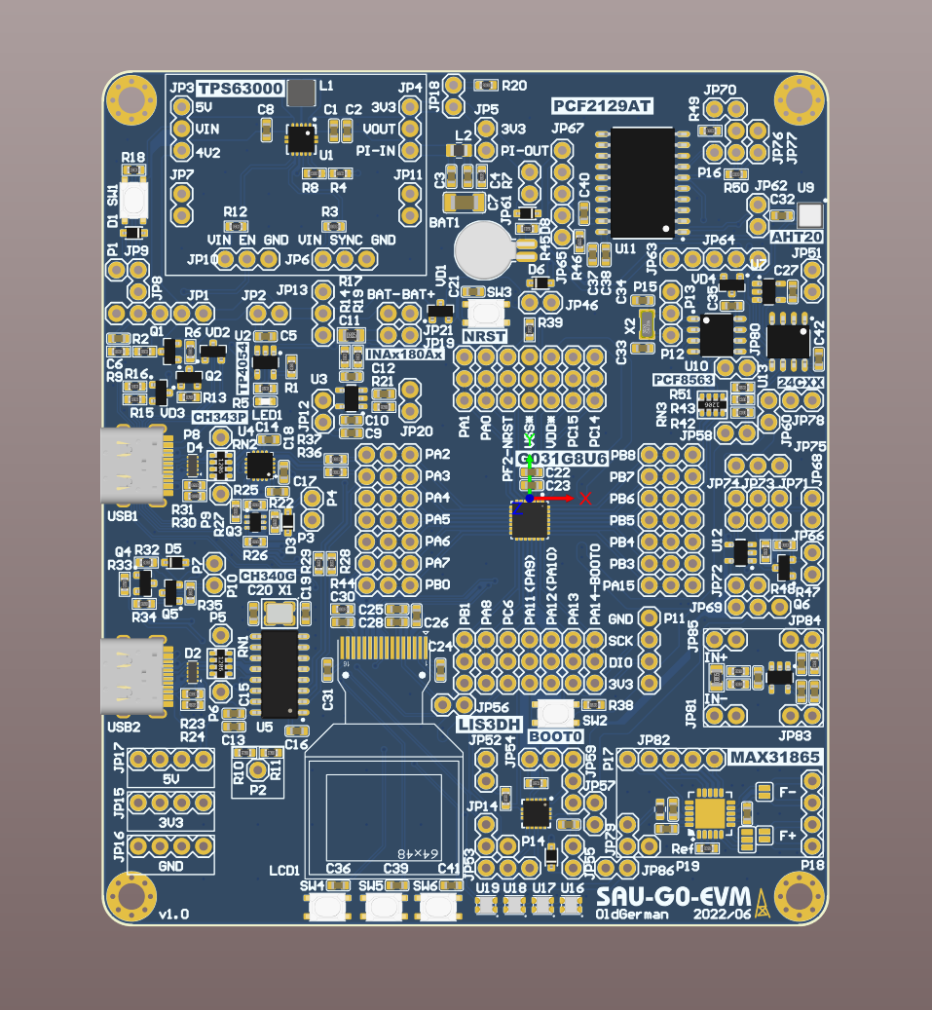
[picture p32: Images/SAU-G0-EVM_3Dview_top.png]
SAU-G0-EVM_3Dview_top
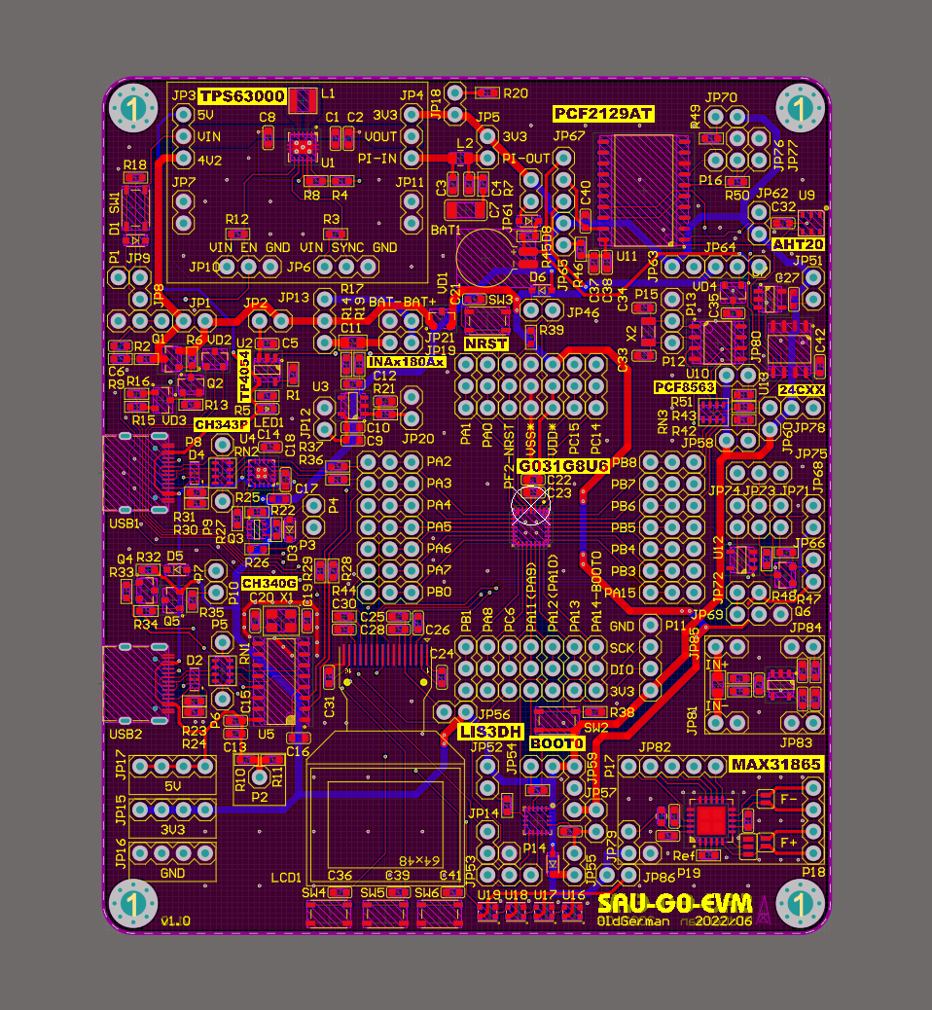
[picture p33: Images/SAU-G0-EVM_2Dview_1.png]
SAU-G0-EVM_2Dview_1
|  |  |
| --- | --- |

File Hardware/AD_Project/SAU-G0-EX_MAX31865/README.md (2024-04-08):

## SAU-G0-EX_MA31865

本目录为 SAU-G0-EX_MA31865 工程文件

暂未完成PCB和固件适配

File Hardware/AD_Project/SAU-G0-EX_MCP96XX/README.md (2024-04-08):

## SAU-G0-EX_MCP90XX

本目录为 SAU-G0-EX_MCP90XX 工程文件

暂未完成PCB和固件适配

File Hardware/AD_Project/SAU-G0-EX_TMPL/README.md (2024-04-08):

## SAU-G0-EX_TMPL

本目录为 SAU-G0-EX_TMPL 工程文件，是所有拓展板的模板工程，若你想制作自己的拓展板，不妨从这里开始绘制PCB

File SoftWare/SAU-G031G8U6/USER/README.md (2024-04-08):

## BMP

使用时仅`#include "BMP.h`就能包含其他所有.h文件

存放 bitmap、icons、fonts

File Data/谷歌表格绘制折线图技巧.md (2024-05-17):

## 谷歌表格绘制折线图技巧

将SAU-G0串口导出的采样数据复制，保存在csv文件中，然后参考[How to Import a CSV into Google Sheets: 3 Best Methods](https://www.youtube.com/watch?v=9x_9aidgVRA)将csv导入Google sheet，得到可编辑的表格数据

折线图选择数据时Invalid报错的原因是数据是文本，没有格式化为数字

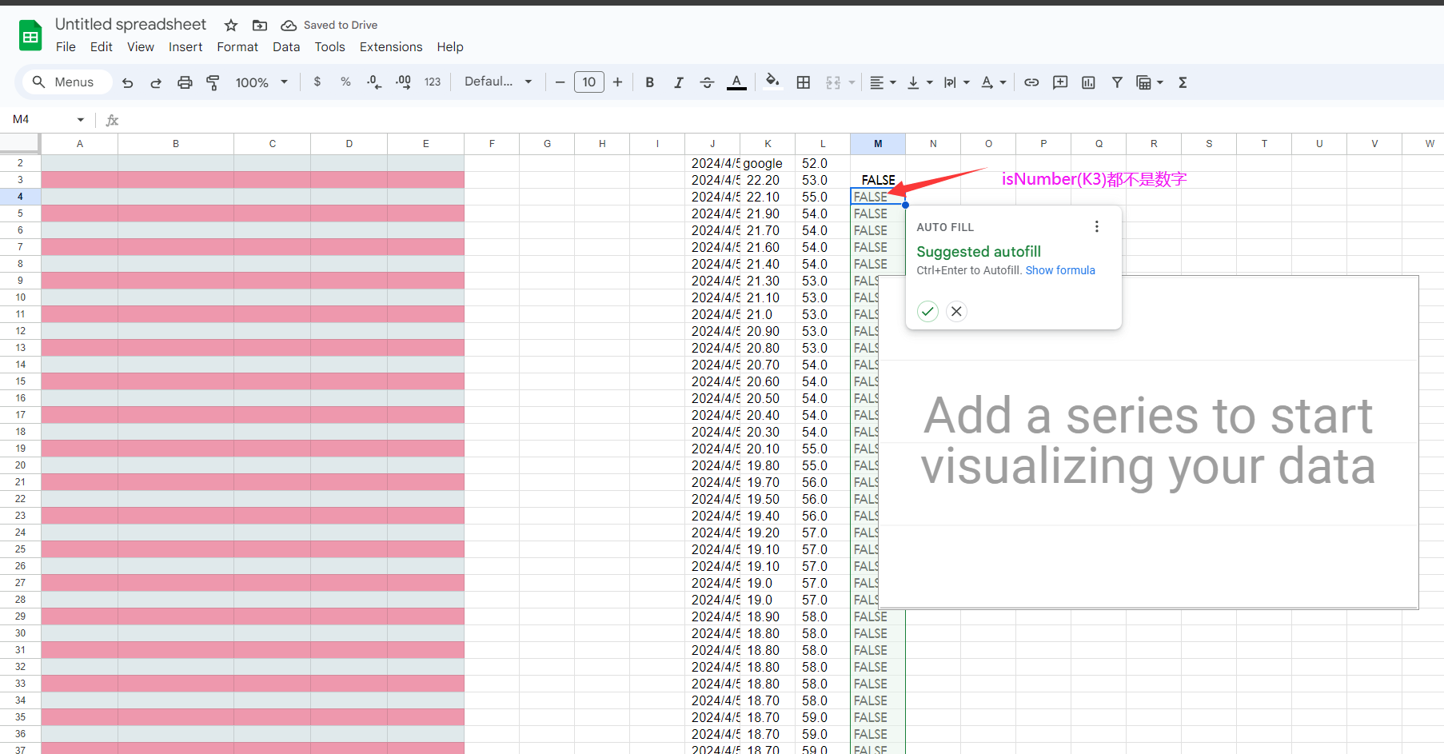
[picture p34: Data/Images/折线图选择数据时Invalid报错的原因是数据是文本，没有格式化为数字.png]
折线图选择数据时Invalid报错的原因是数据是文本，没有格式化为数字


所以要首先对原始的文本温湿度数据格式化为Number类型

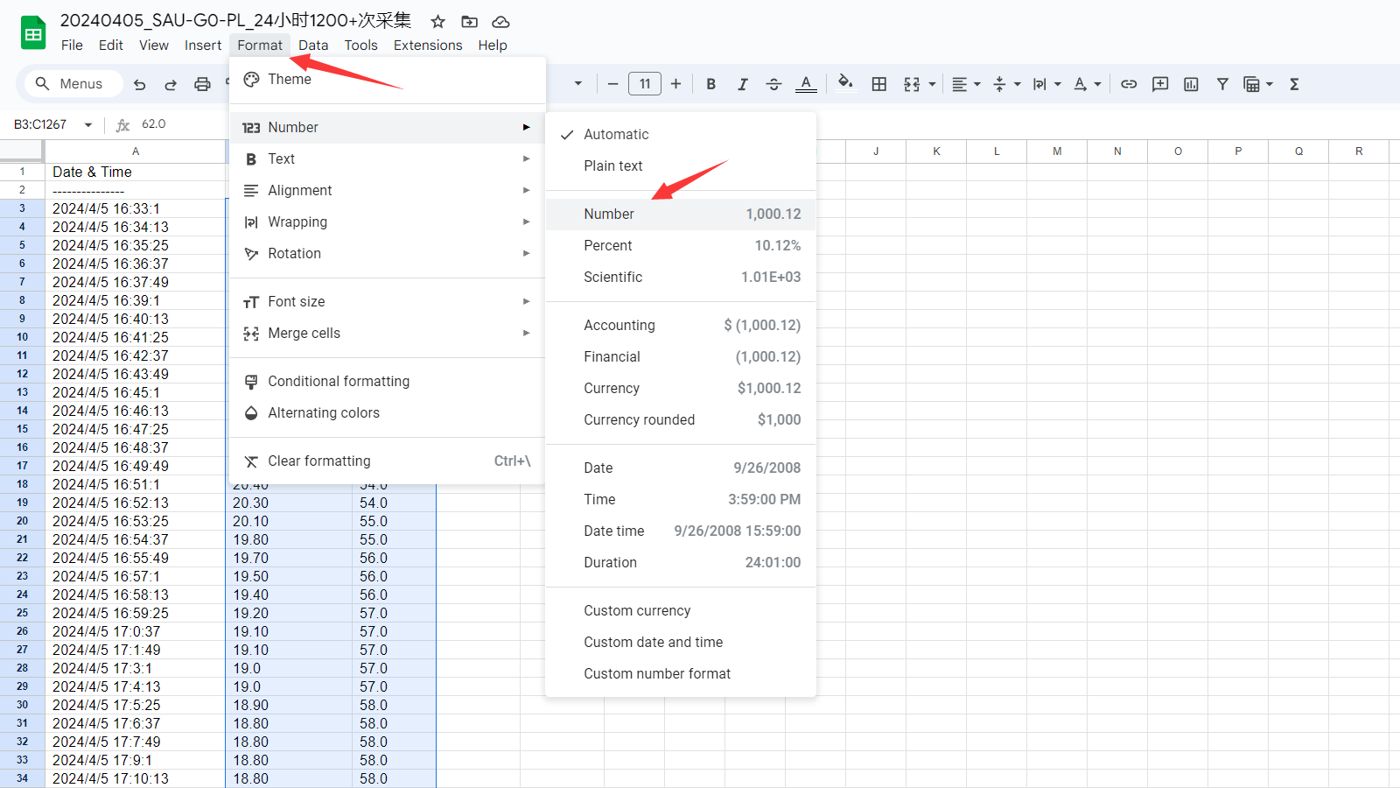
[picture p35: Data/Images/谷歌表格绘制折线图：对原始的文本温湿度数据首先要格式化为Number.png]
谷歌表格绘制折线图：对原始的文本温湿度数据首先要格式化为Number


然后把文本类型的日期时间也格式化为自定义格式

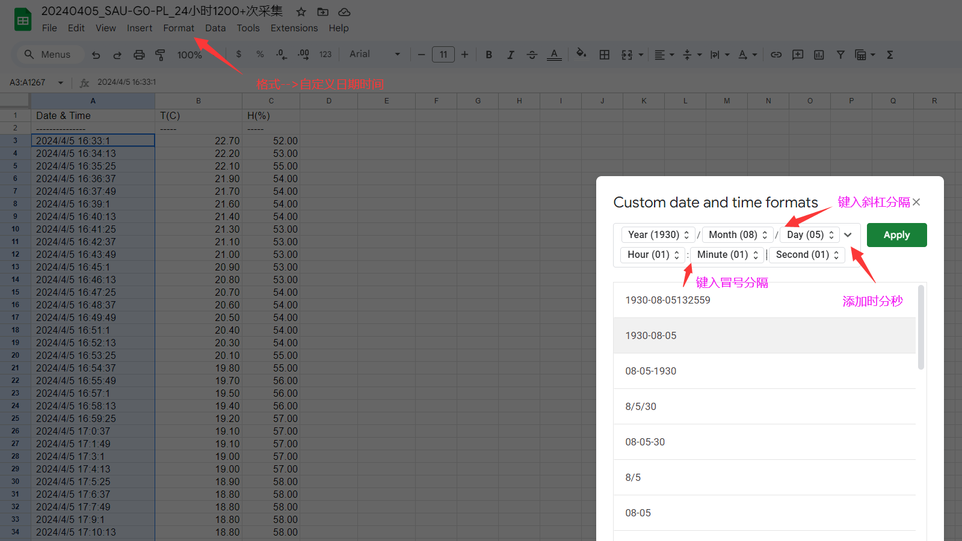
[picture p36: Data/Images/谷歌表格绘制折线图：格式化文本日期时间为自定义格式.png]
谷歌表格绘制折线图：格式化文本日期时间为自定义格式


完成效果

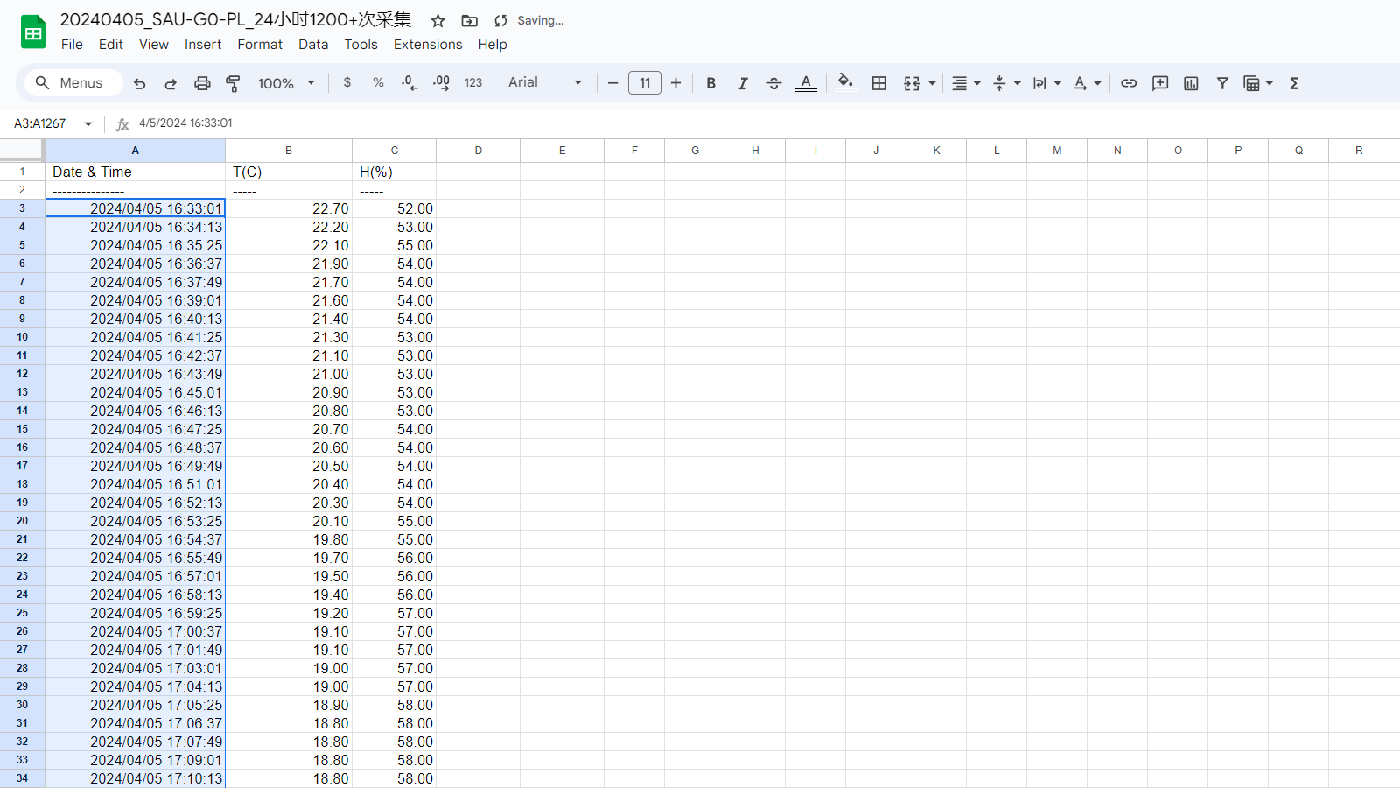
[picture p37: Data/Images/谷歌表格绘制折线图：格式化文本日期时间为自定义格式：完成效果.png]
谷歌表格绘制折线图：格式化文本日期时间为自定义格式：完成效果


选定数据范围即可出图

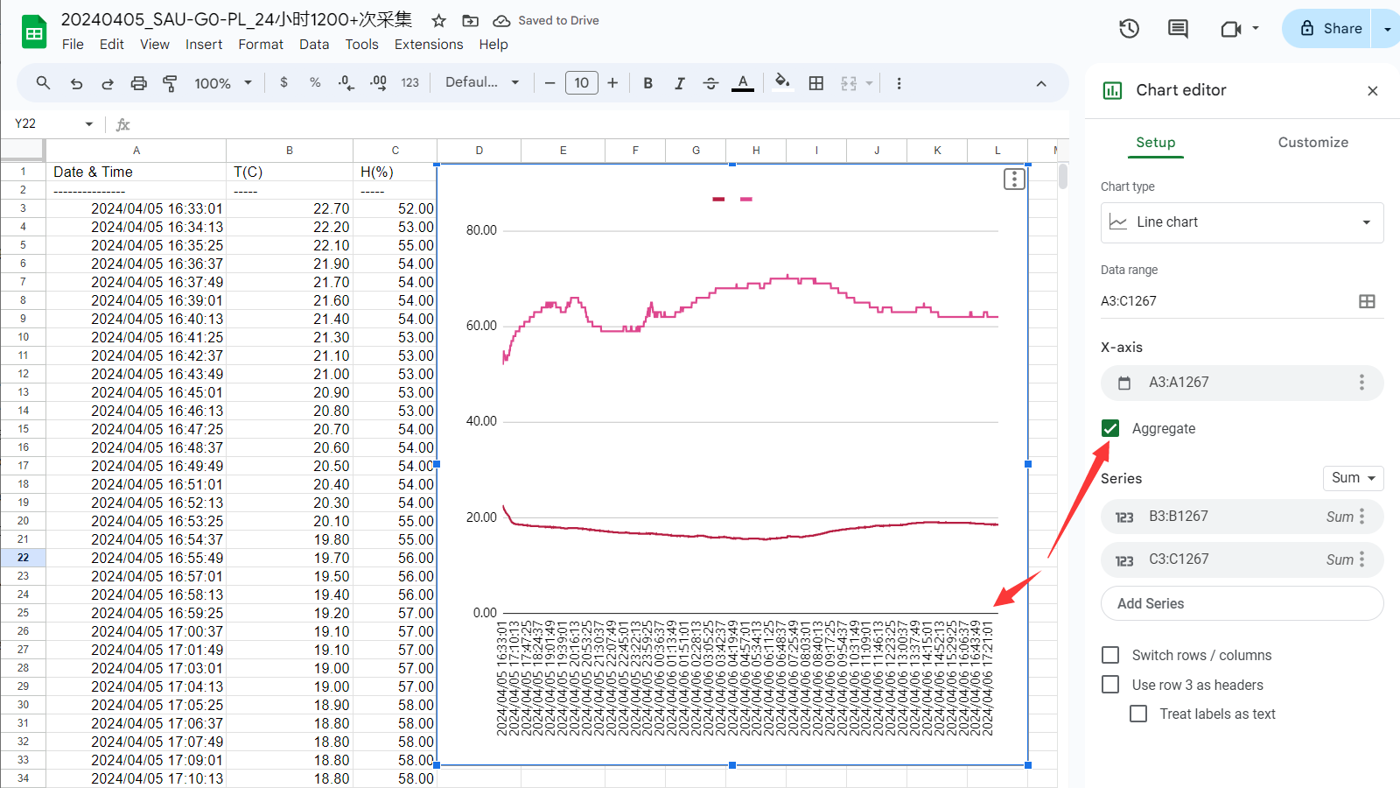
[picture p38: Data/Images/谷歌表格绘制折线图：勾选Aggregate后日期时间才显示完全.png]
谷歌表格绘制折线图：勾选Aggregate后日期时间才显示完全


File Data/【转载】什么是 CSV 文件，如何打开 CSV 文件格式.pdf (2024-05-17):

# CSV 文件格式

通常 CSV 文件的第一行包含表格的列标签。随后的每一行代表表格的一行。逗号分隔行中的每个单元格，这就是名称的由来。

下面是一个 CSV 文件的例子。这个例子有三列，分别标为“姓名”、“ID”和“食物”。它有五行，包括标题行。

name, id, favorite food
quincy, 1, hot dogs
beau, 2, cereal
abbey, 3, pizza
mrugesh, 4, ice cream

以下是该文件在电子表格中的样子。

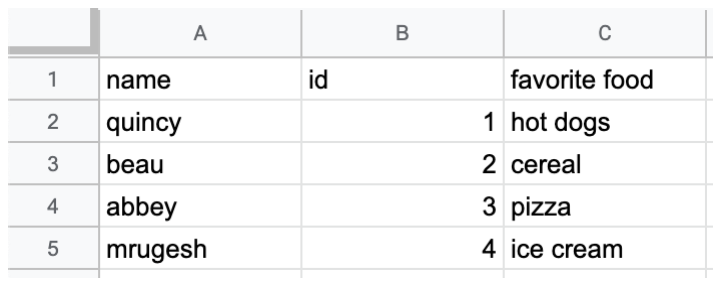
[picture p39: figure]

由于 CSV 文件只是一个文本文件，你几乎可以在任何文本编辑器中创建一个。你也可以从几乎任何电子表格程序中导出 CSV 文件，如 Microsoft Word、OpenOffice Calc 或 Google Sheets。

# 如何打开 CSV 文件

打开一个 CSV 文件比你想象的要简单。在几乎所有的文本编辑器或电子表格程序中，只要选择 文件>打开，然后选择 CSV 文件。

对于大多数人来说，最好是使用电子表格程序。电子表格程序以一种比文本编辑器更容易阅读和操作的方式显示数据。我们将详细介绍如何在 Microsoft Excel、OpenOffice Calc 和 Google Sheets 中打开 CSV 文件。

# 打开 CSV 文件 Microsoft Excel

如果你已经安装了 Microsoft Excel，只要双击 CSV 文件就可以在 Excel 中打开它。双击该文件后，你可能会看到一个提示，询问你想用哪个程序打开 它。选择 Microsoft Excel。

如果你已经在 Microsoft Excel 中，你可以选择文件>打开并选择 CSV 文件。如果你没有看到你想打开的文件，你可能需要把要打开的文件类型改为 “文本文件（*.prn, *.txt, *.csv）”。Excel 将在一个新的工作簿中显示数据。

你也可以将 CSV 文件中的数据导入到现有的工作表中。

1. 在数据选项卡上，在获取和转换数据组中，单击从文本/CSV。
2. 在导入数据对话框中，双击你要导入的 CSV 文件，然后点击导入。

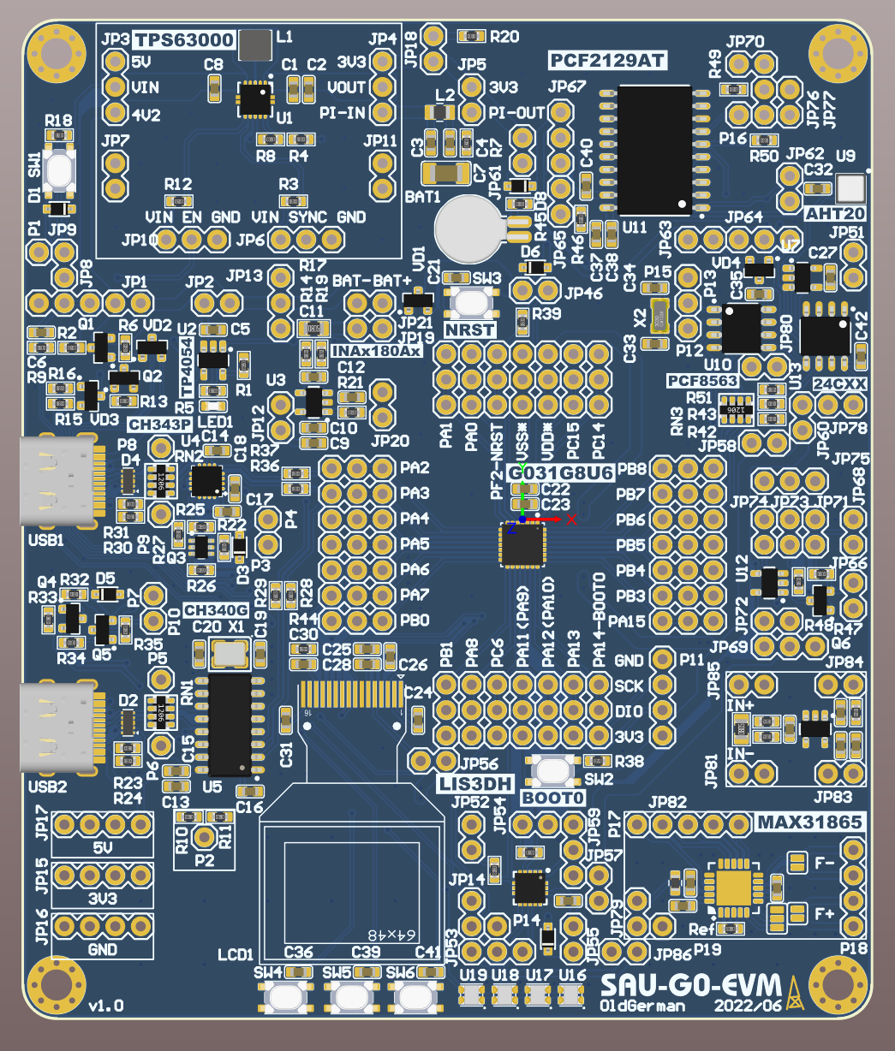
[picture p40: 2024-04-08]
Hardware/AD_Project/SAU-G0-EVM/Images/3D_top_view.png

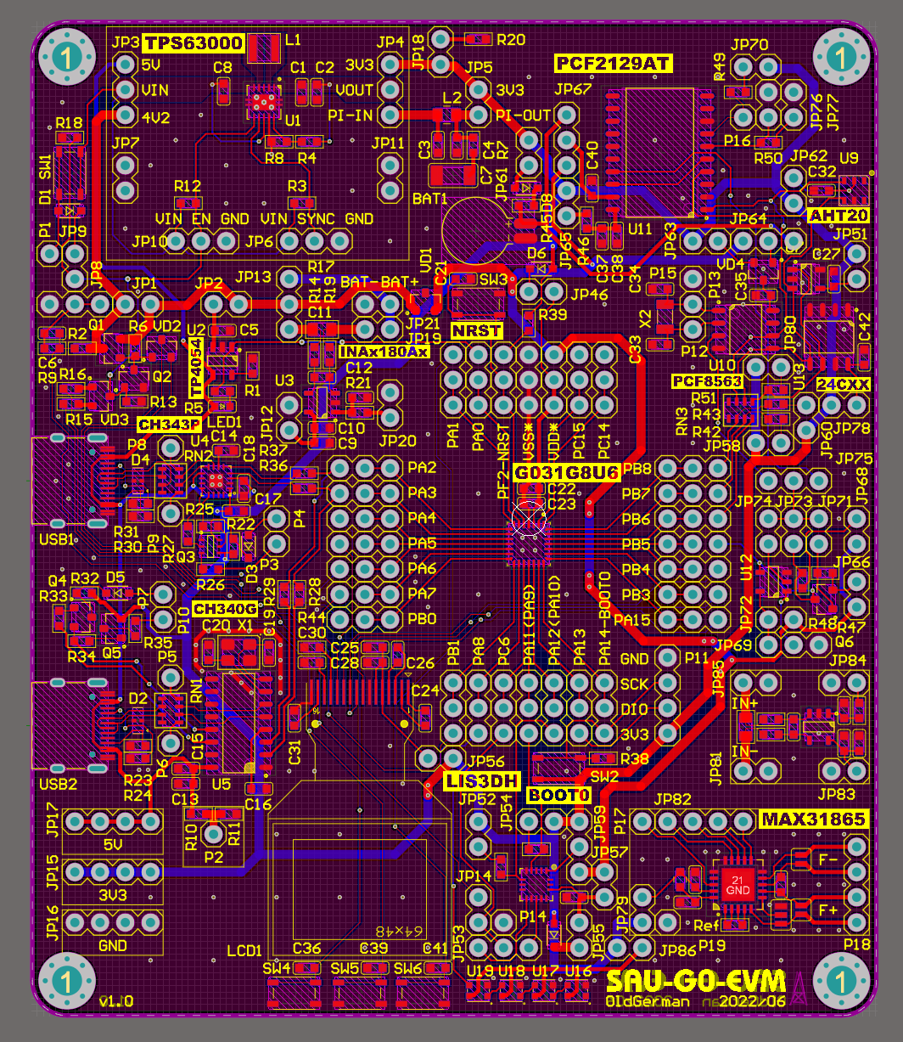
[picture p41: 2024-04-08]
Hardware/AD_Project/SAU-G0-EVM/Images/2D_view.png

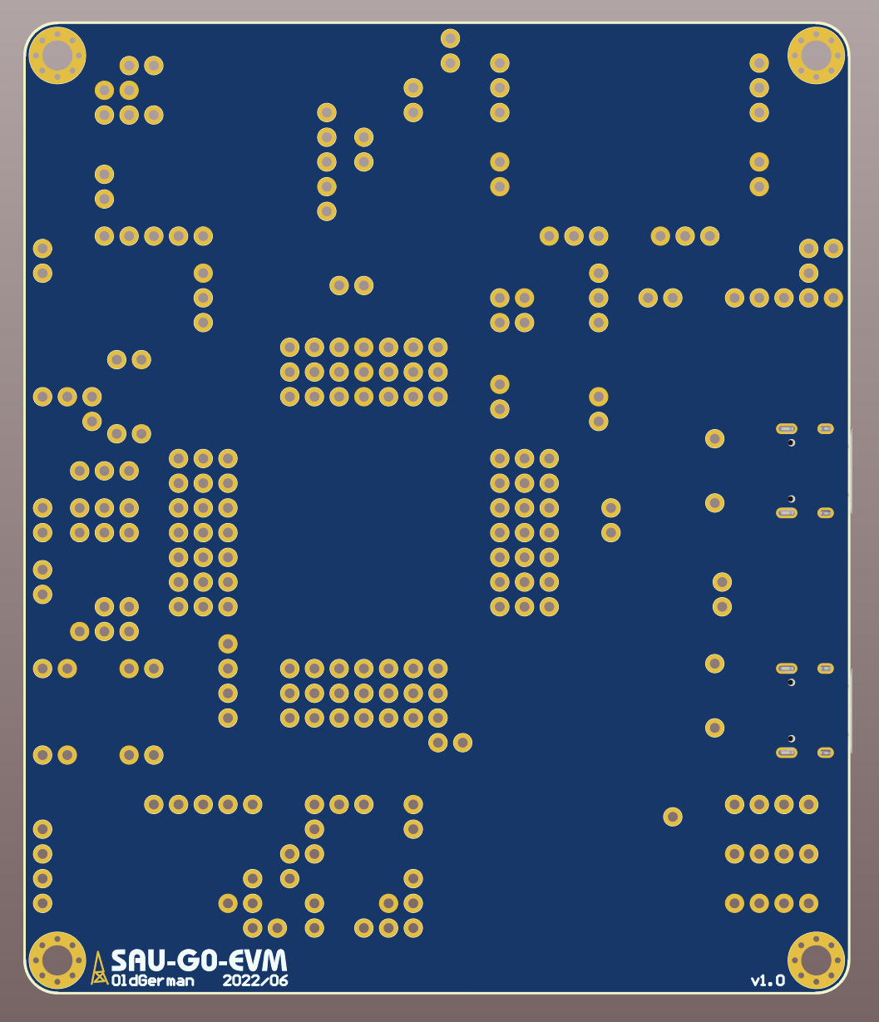
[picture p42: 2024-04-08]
Hardware/AD_Project/SAU-G0-EVM/Images/3D_bottom_view.png

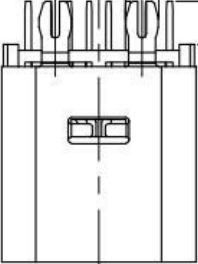
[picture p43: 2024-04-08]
Hardware/SW_Project/Size/typec-14p_1.png

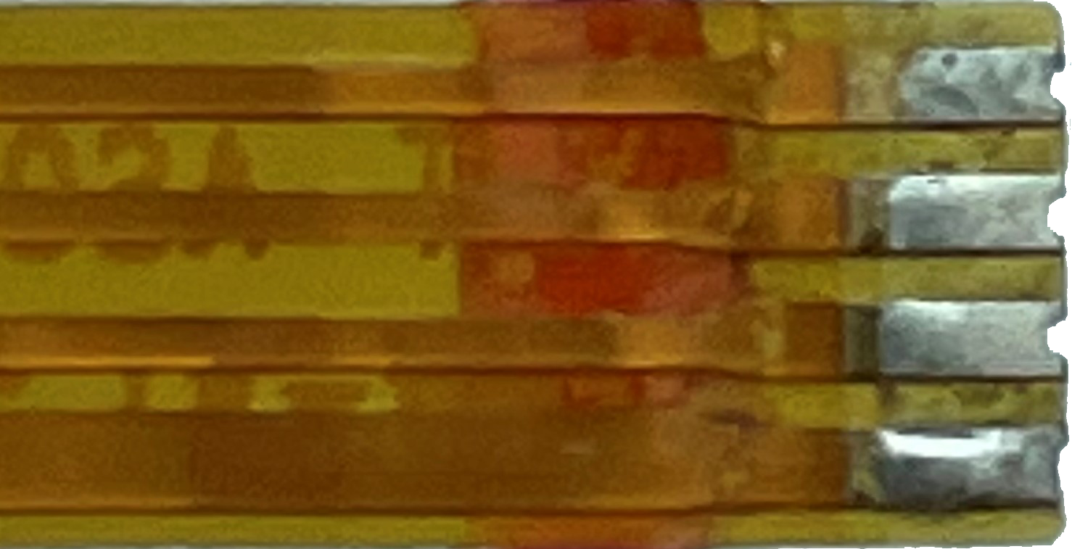
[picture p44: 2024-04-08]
Hardware/SW_Project/Size/按键FPC焊盘特写_PFC宽度4mm.png

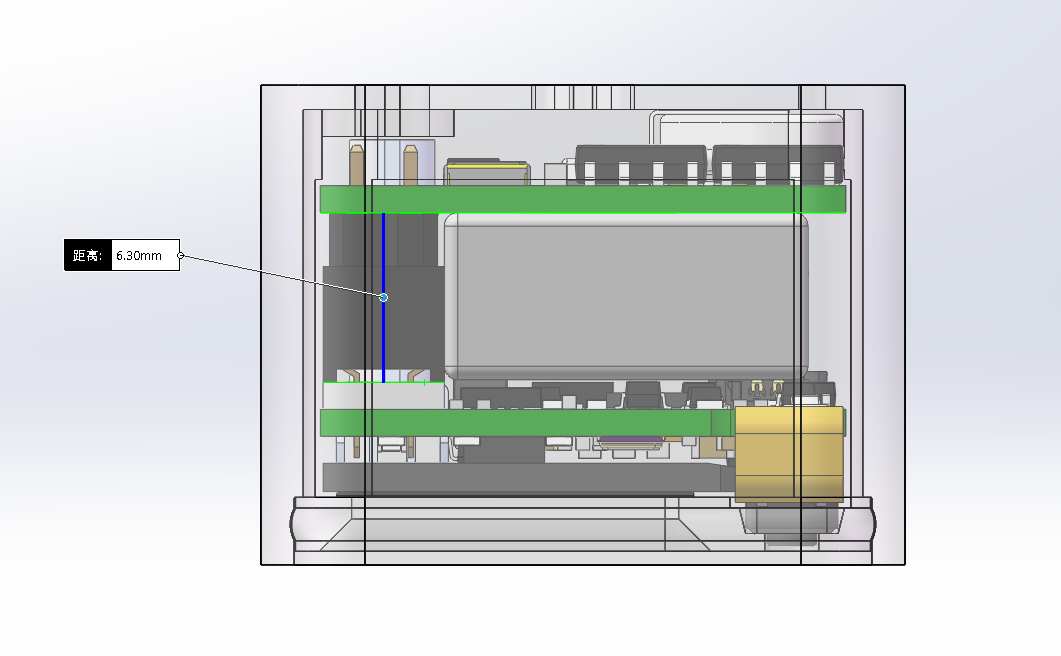
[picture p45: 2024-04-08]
Hardware/SW_Project/Size/2.0mm连接器合并塑高6.3mm.png

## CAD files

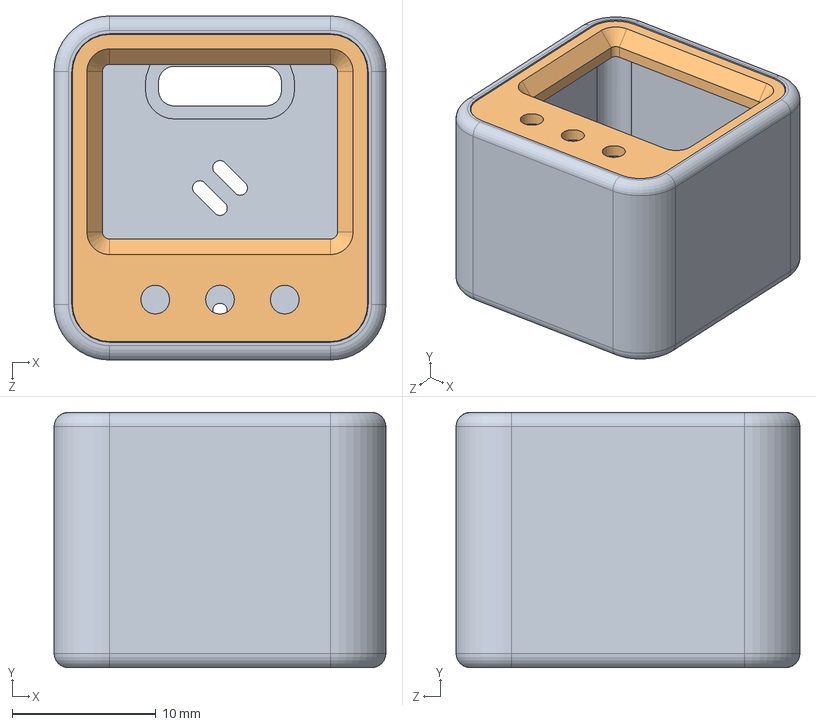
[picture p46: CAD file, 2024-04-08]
Hardware/SW_Project/外壳-方案2_LC打印_装配测试.SLDASM
23.1 x 17.7 x 23.9 mm
外壳-方案2_LC打印
外壳-方案2-盖子_LC打印

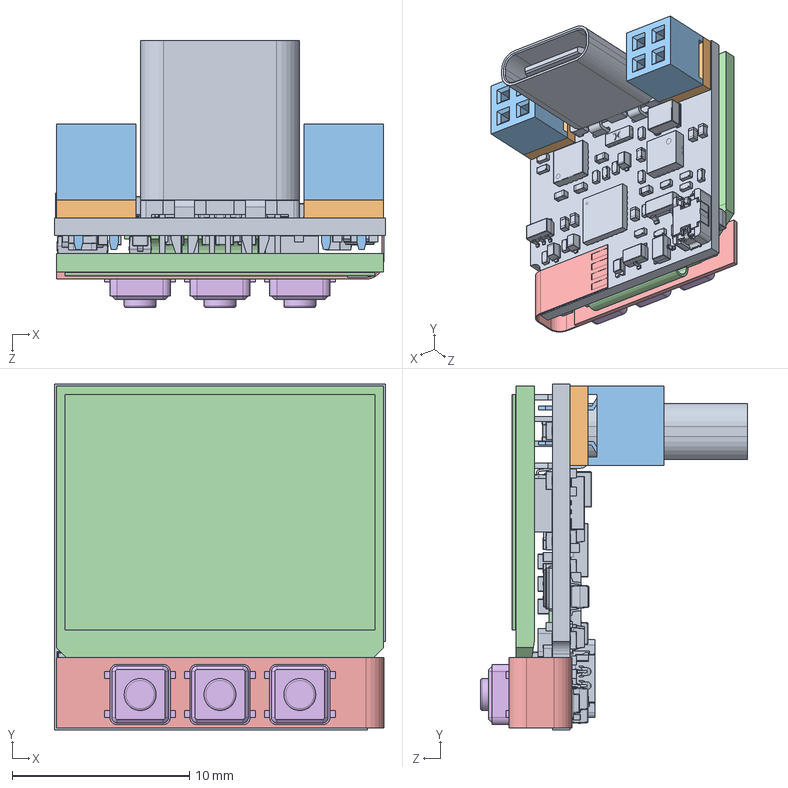
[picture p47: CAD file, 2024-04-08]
Hardware/SW_Project/SAU-G0_PCB.SLDASM
18.7 x 19.5 x 15.1 mm
SAU-G0_STEP_AD
2.00mm_2x2_垫板PCB_厚1.0mm x 2
2.00mm母座2x2 x 2
0.66寸_64x48_TOP_FPC背面距离背板1mm
方案2-轻触开关_柔性PCB
轻触开关3x3.5x1.5_3x4.0x2.0 x 3

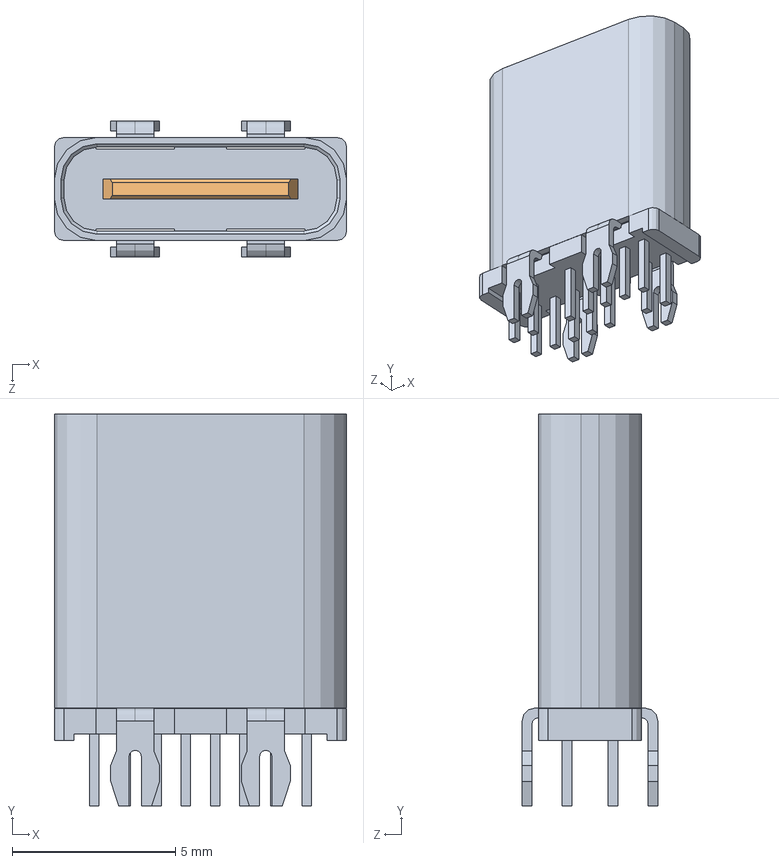
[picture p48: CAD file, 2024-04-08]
Hardware/SW_Project/Type-c-14p_vertical_H-10mm.SLDASM
8.95 x 12.0 x 4.16 mm
TYPE-C-14-vertical_H-10mm
TYPE-C-塑料内芯

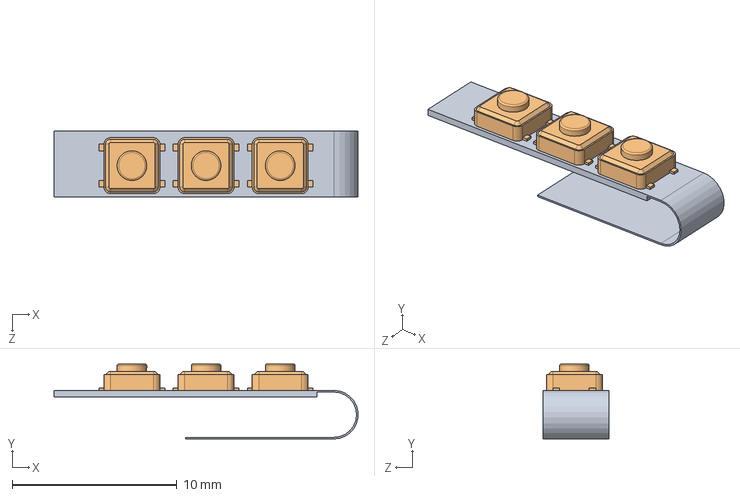
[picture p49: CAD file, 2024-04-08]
Hardware/SW_Project/方案2-轻触开关+柔性PCB.SLDASM
18.4 x 4.55 x 4.00 mm
轻触开关_柔性PCB
轻触开关3x3.5x1.5_3x4.0x2.0 x 3

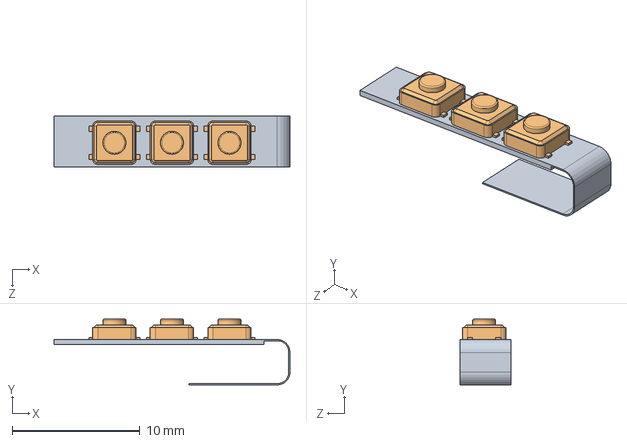
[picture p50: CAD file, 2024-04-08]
Hardware/SW_Project/轻触开关+柔性PCB.SLDASM
18.5 x 5.16 x 4.00 mm
方案2-轻触开关_柔性PCB
轻触开关3x3.5x1.5_3x4.0x2.0 x 3

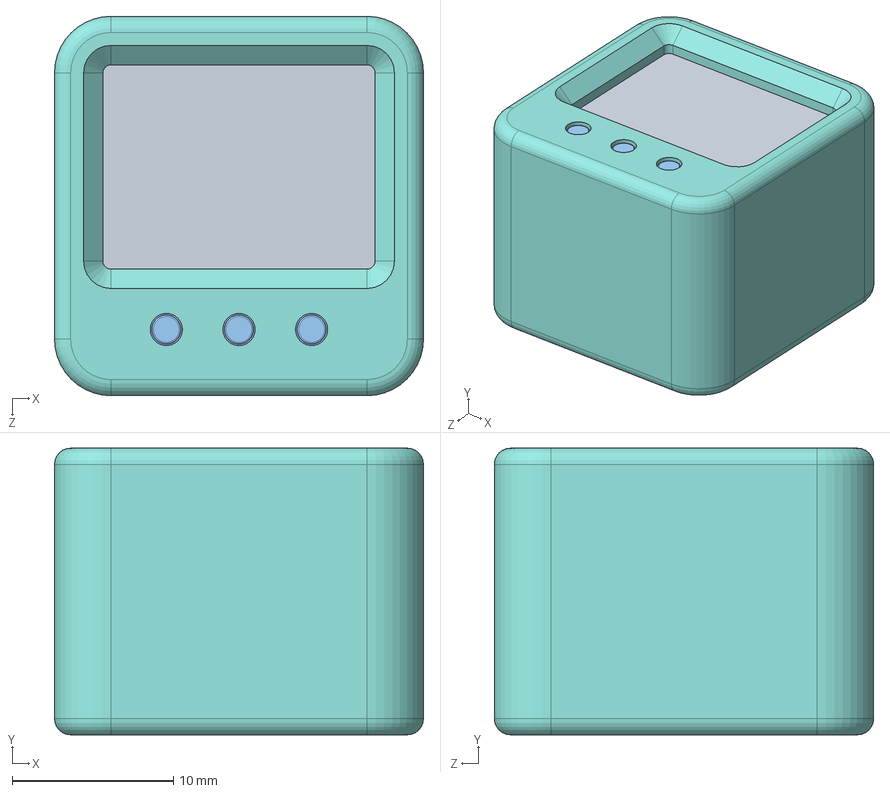
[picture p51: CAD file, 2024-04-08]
Hardware/SW_Project/方案1.SLDASM
22.9 x 17.8 x 23.5 mm
0.66寸_64x48
轻触开关_柔性PCB
轻触开关3x3.5x1.5_3x4.0x2.0 x 3
PCB
AHT20 Sensor
UFQFPN-28
LGA-16_3x3mm_P0.5mm
外壳
HRO_TYPE-C-31-M-12
601417(18.0x14.8x5.7mm)_3.7V_100mAh
JST_ZH1.5_2P_B2B-ZR-SM4-TF
2_54_x_4P_Female
PCB_2
JST_ZH1.5_2P_胶壳

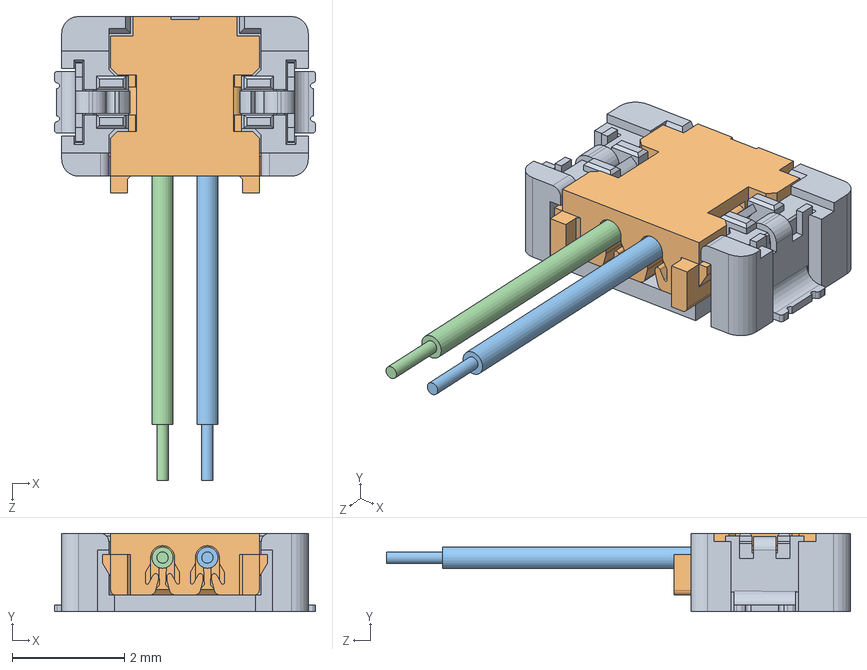
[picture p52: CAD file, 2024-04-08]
Hardware/SW_Project/泰科198181x公母装配.SLDASM
4.66 x 1.40 x 8.28 mm
泰科1981813-1
泰科1981812-1
32AWG特氟龙7股线-红
32AWG特氟龙7股线-黑

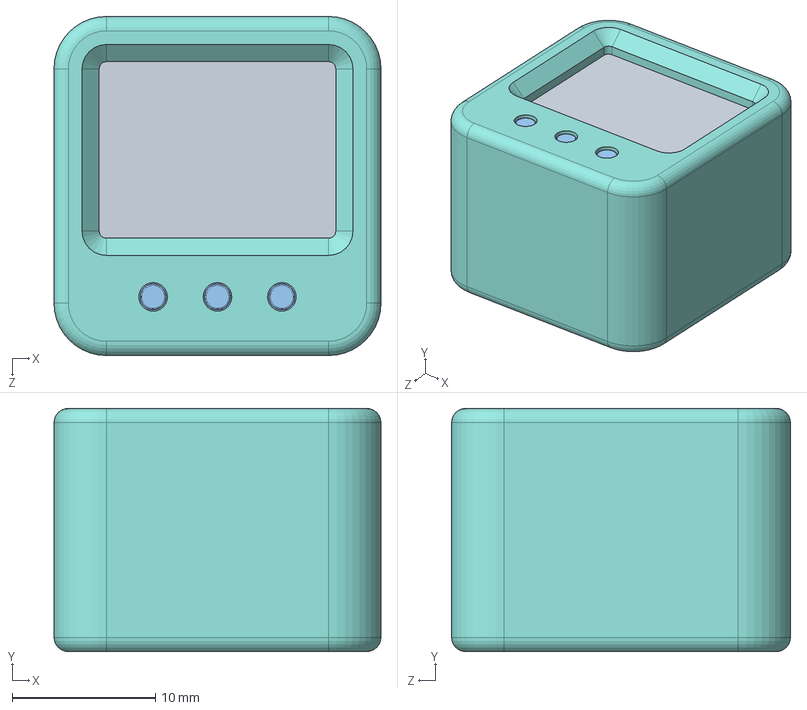
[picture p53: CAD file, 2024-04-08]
Hardware/SW_Project/方案3.SLDASM
22.9 x 17.0 x 23.7 mm
0.66寸_64x48_TOP_FPC背面距离背板1mm
方案2-轻触开关_柔性PCB
轻触开关3x3.5x1.5_3x4.0x2.0 x 3
PCB
AHT20 Sensor
UFQFPN-28
LGA-16_3x3mm_P0.5mm
外壳
PCB_2
Type-c-14p_vertical_H-10mm
2.00mm母座2x2 x 2
2.0mm排针2x2 x 2
sop8
外壳-盖子
泰科1981813-1
泰科1981812-1
32AWG特氟龙7股线-红
32AWG特氟龙7股线-黑
2.00mm_2x2_垫板PCB_厚1.0mm x 2
601419(18.5x13.5x6.2mm)_3.7V_100mAh

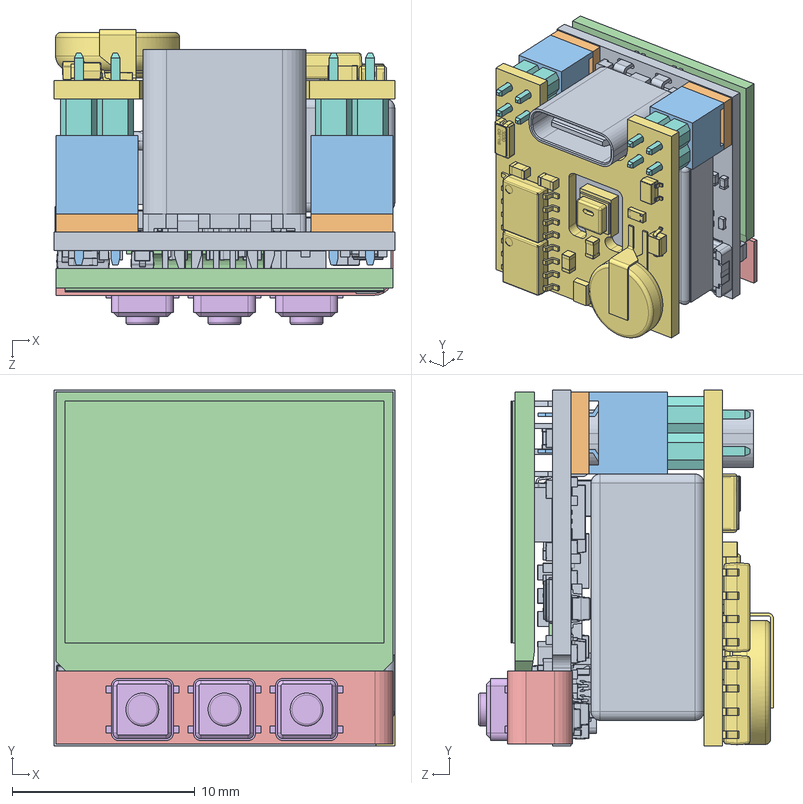
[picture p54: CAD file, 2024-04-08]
Hardware/SW_Project/SAU-G0+EX_AHT-GL_PCB.SLDASM
18.7 x 19.5 x 16.2 mm
SAU-G0_STEP_AD
2.00mm_2x2_垫板PCB_厚1.0mm x 2
2.00mm母座2x2 x 2
0.66寸_64x48_TOP_FPC背面距离背板1mm
方案2-轻触开关_柔性PCB
轻触开关3x3.5x1.5_3x4.0x2.0 x 3
SAU-G0-EX_AHT-GL_STEP_AD
2.0mm排针2x2 x 2
601419(18.5x13.5x6.2mm)_3.7V_100mAh

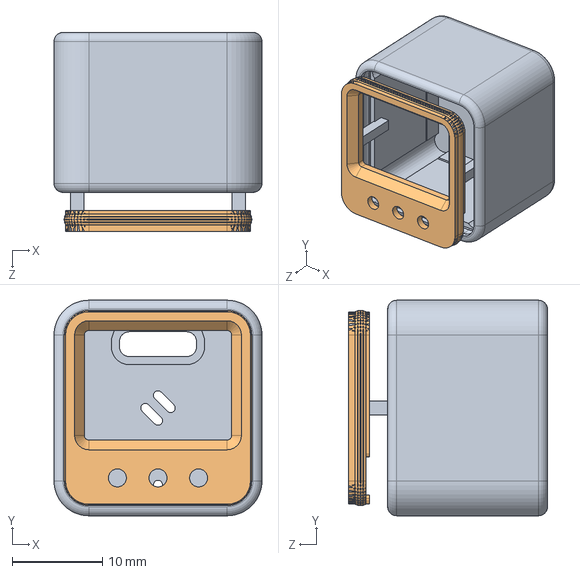
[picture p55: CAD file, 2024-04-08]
Hardware/SW_Project/外壳-方案2-GL_LC打印.SLDASM
23.1 x 23.9 x 22.1 mm

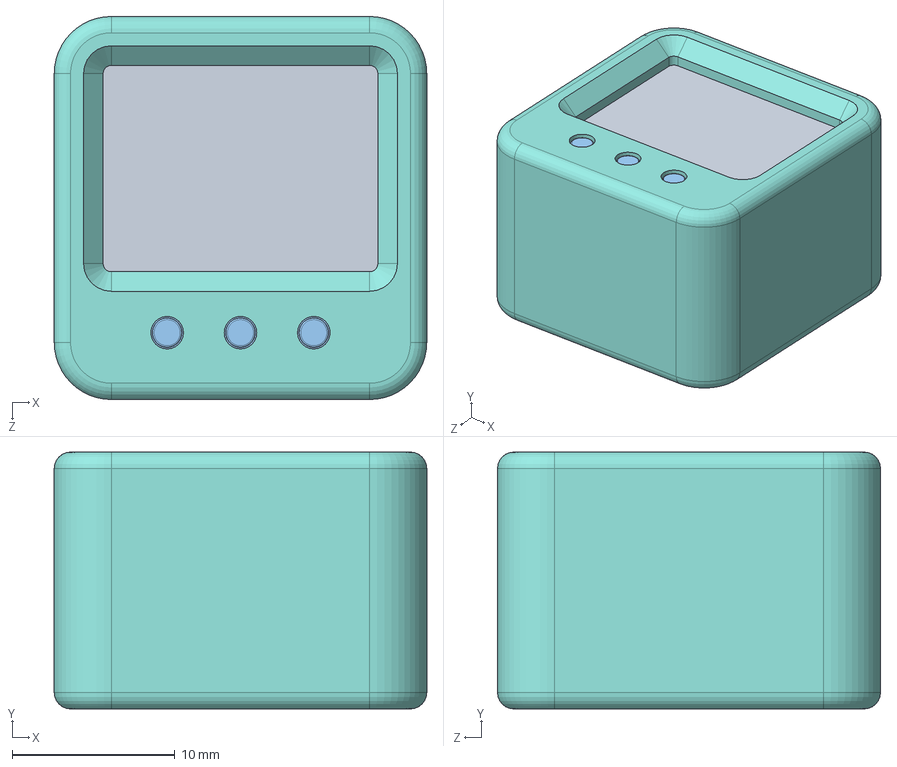
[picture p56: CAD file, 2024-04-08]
Hardware/SW_Project/方案2.SLDASM
22.9 x 15.8 x 23.5 mm
0.66寸_64x48
方案2-轻触开关_柔性PCB
轻触开关3x3.5x1.5_3x4.0x2.0 x 3
PCB
AHT20 Sensor
UFQFPN-28
LGA-16_3x3mm_P0.5mm
外壳
601417(18.0x14.8x5.7mm)_3.7V_100mAh
JST_ZH1.5_2P_B2B-ZR-SM4-TF
PCB_2
JST_ZH1.5_2P_胶壳
Type-c-14p_vertical_H-10mm
1.27mm排母x2 x 2
1.27mm排针x2 x 2

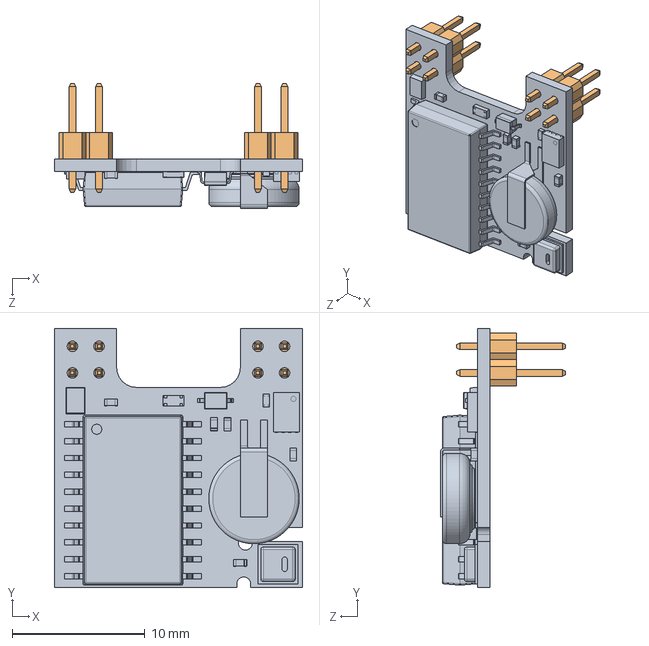
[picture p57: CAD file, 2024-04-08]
Hardware/SW_Project/SAU-G0-EX_AHT-PL_PCB.SLDASM
18.7 x 19.5 x 9.43 mm
SAU-G0-EX_AHT-PL_STEP_AD
2.0mm排针2x2 x 2

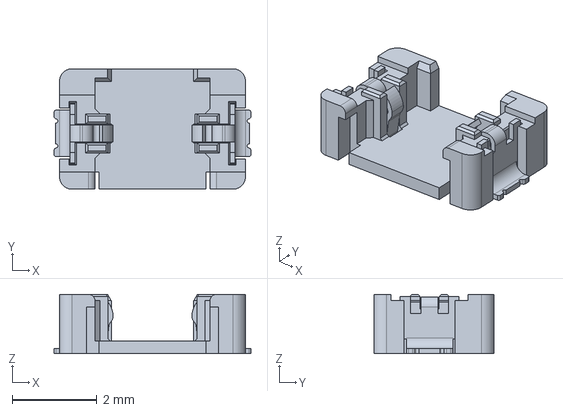
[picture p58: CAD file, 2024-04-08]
Hardware/Datasheets/连接器/泰科 198181x 连接器/c-1981813-1-a1-3d.stp
4.66 x 2.85 x 1.40 mm

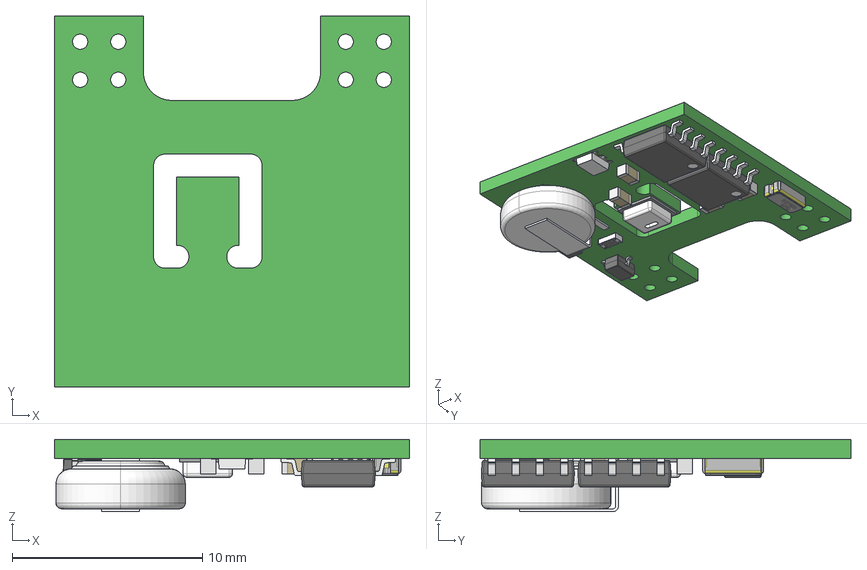
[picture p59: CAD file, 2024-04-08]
Hardware/SW_Project/AD_STEP_OUT/SAU-G0-EX_AHT-GL.step
18.7 x 19.5 x 3.80 mm
0402_cap
DFN-8-1EP_3x2mm_P0.5mm_EP1.75x1.45mm
MS621FE-FL11E
EPSON_SG-3030CM
sot-323
SO-8 x 2
WS2812-2020
0603_resistor
SOD-323
0603_cap x 4
AHT20_Sensor
P2
P1

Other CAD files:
Hardware/SW_Project/轻触开关+柔性PCB-原点复位.SLDASM
Hardware/SW_Project/DXF_OUT/PCB_2.DXF
Hardware/SW_Project/STEP_OUT/2.00mm母座2x2.STEP
Hardware/SW_Project/STL_OUT/单个零件/外壳-方案2_GL_盒子.STL
Hardware/Datasheets/连接器/泰科 198181x 连接器/c-1981812-1-b-3d.stp
Hardware/SW_Project/0.66寸_64x48_TOP_FPC背面距离背板1mm.sldprt
Hardware/SW_Project/0.66寸_64x48_刚好折弯到三角边.sldprt
Hardware/SW_Project/0.66寸_64x48_导AD封装库.SLDDRW
Hardware/SW_Project/1.27mm排母x2.SLDPRT
Hardware/SW_Project/1.27mm排针x2.SLDPRT
Hardware/SW_Project/2.00mm_2x2_垫板PCB_厚0.8mm.SLDPRT
Hardware/SW_Project/2.00mm_2x2_垫板PCB_厚1.0mm.SLDPRT
Hardware/SW_Project/2.00mm_母座插针.SLDPRT
Hardware/SW_Project/2.00mm母座2x1.SLDPRT
Hardware/SW_Project/2.00mm母座2x2.SLDPRT
Hardware/SW_Project/2.0mm排针2x2.SLDPRT
Hardware/SW_Project/2.0mm排针x1.SLDPRT
Hardware/SW_Project/2.54mm_母座插针.SLDPRT
Hardware/SW_Project/2.54x2x1奇怪的.SLDPRT
Hardware/SW_Project/2_54_x_4P_Female.SLDPRT
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

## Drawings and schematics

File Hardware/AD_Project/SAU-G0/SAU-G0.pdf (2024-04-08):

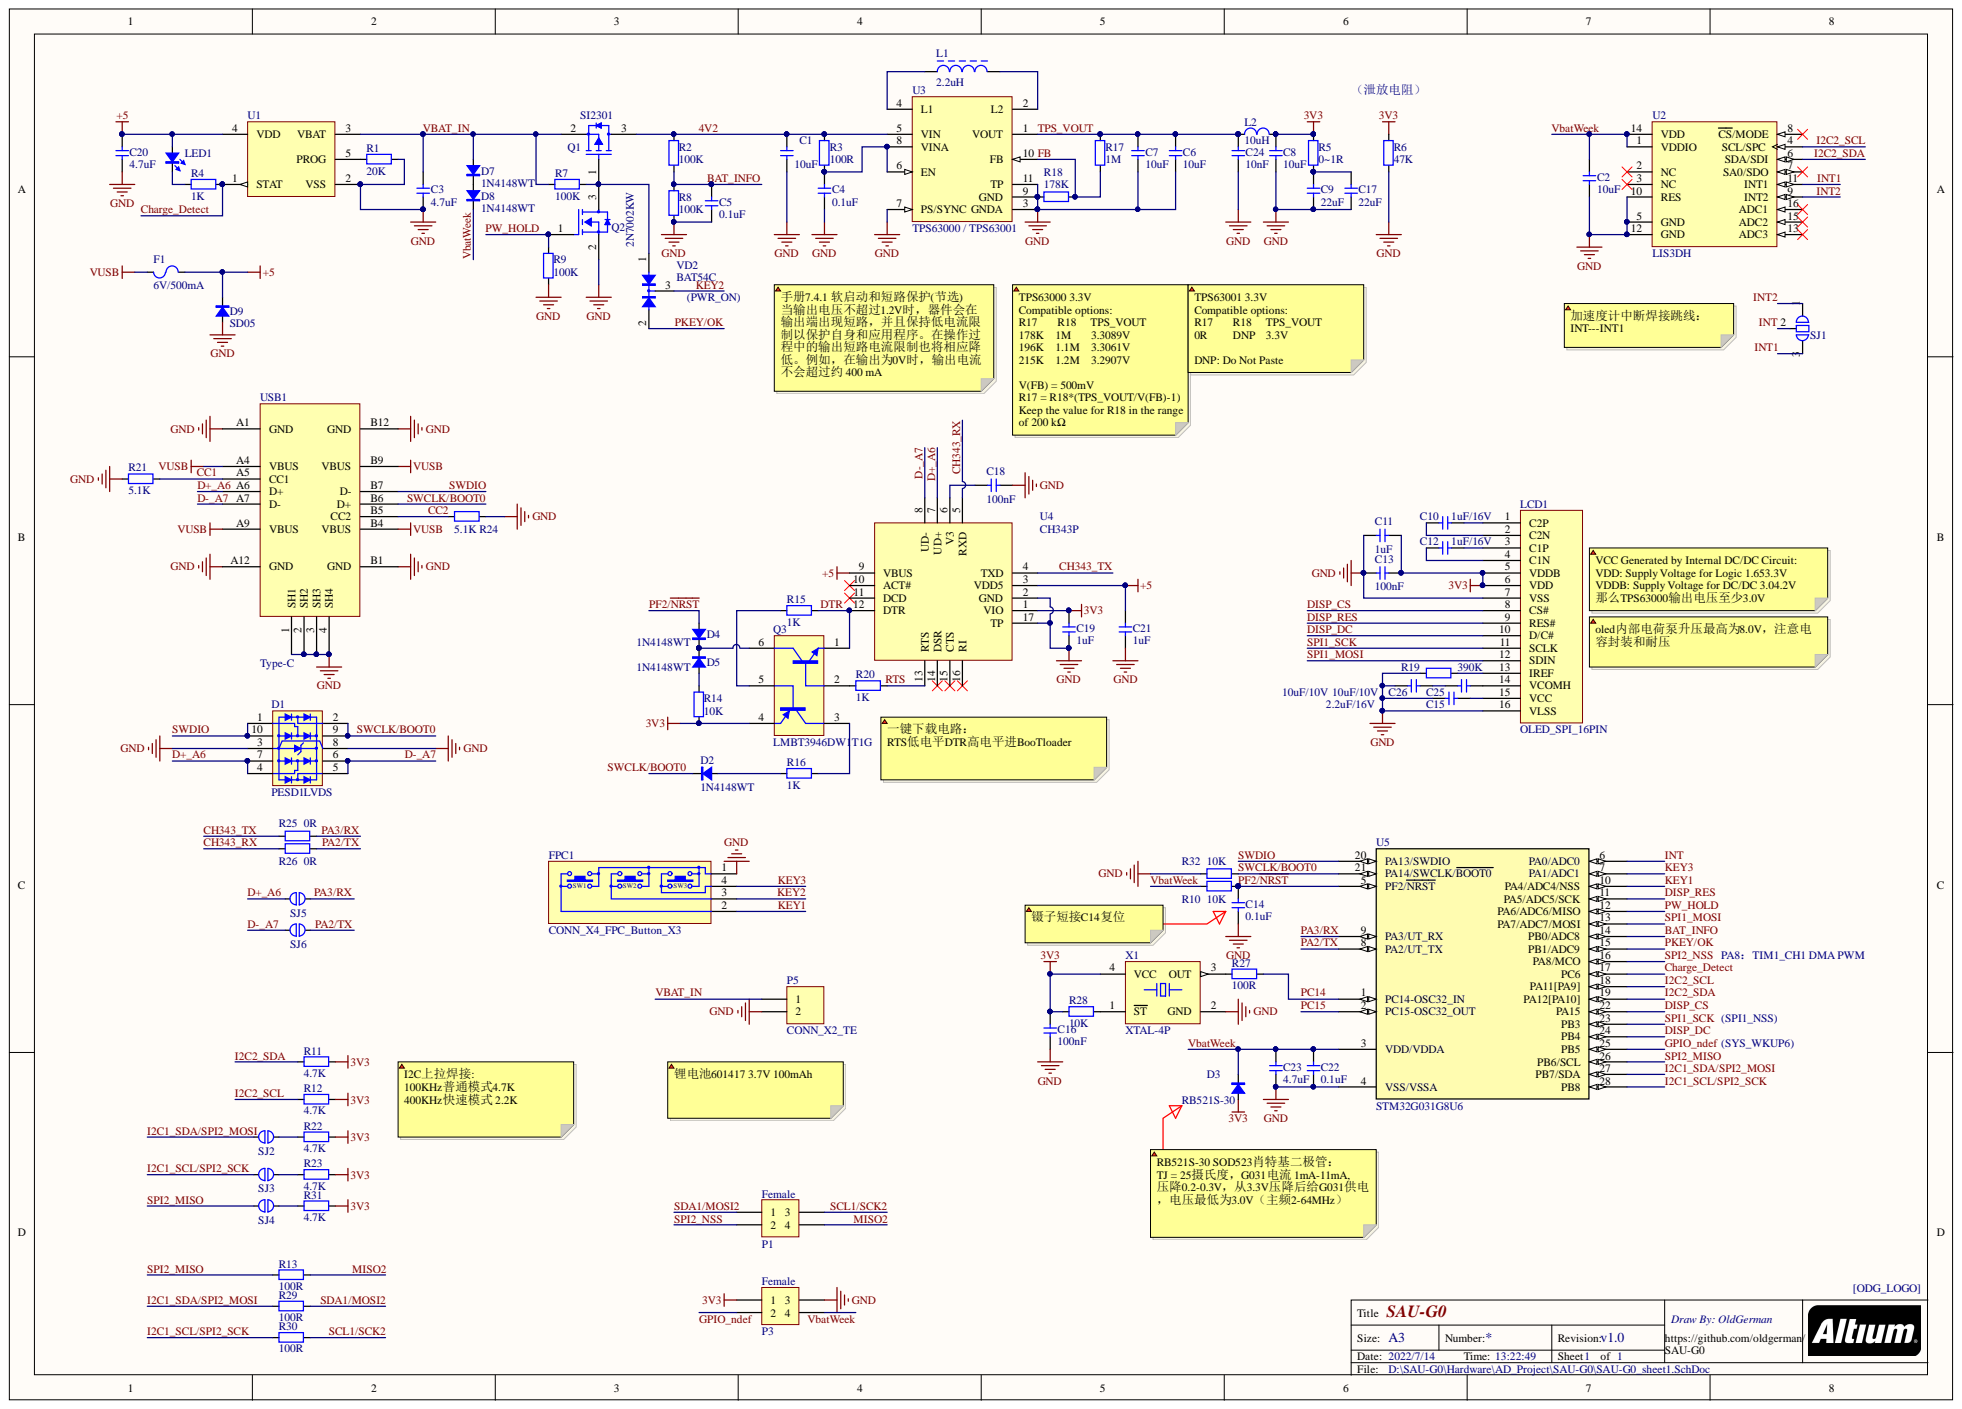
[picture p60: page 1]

DNP: Do Not Paste

R17 = R18*(TPS_VOUT/V(FB)-1)
Keep the value for R18 in the range

VCC Generated by Internal DC/DC Circuit:
VDD: Supply Voltage for Logic 1.653.3V
VDDB: Supply Voltage for DC/DC 3.04.2V
那么TPS63000输出电压至少3.0V

VDD/VDDA 3 VSS/VSSA 4

SAU-G0 Title | Draw By: OldGerman https://github.com/oldgerman/SAU-G0

Size: A3 | Number: * | Revision: v1.0
Date: 2022/7/14 Time: 13:22:49 | | Sheet 1 of 1

D:\SAU-G0\Hardware\AD_Project\SAU-G0\SAU-G0_sheet1.SchDoc

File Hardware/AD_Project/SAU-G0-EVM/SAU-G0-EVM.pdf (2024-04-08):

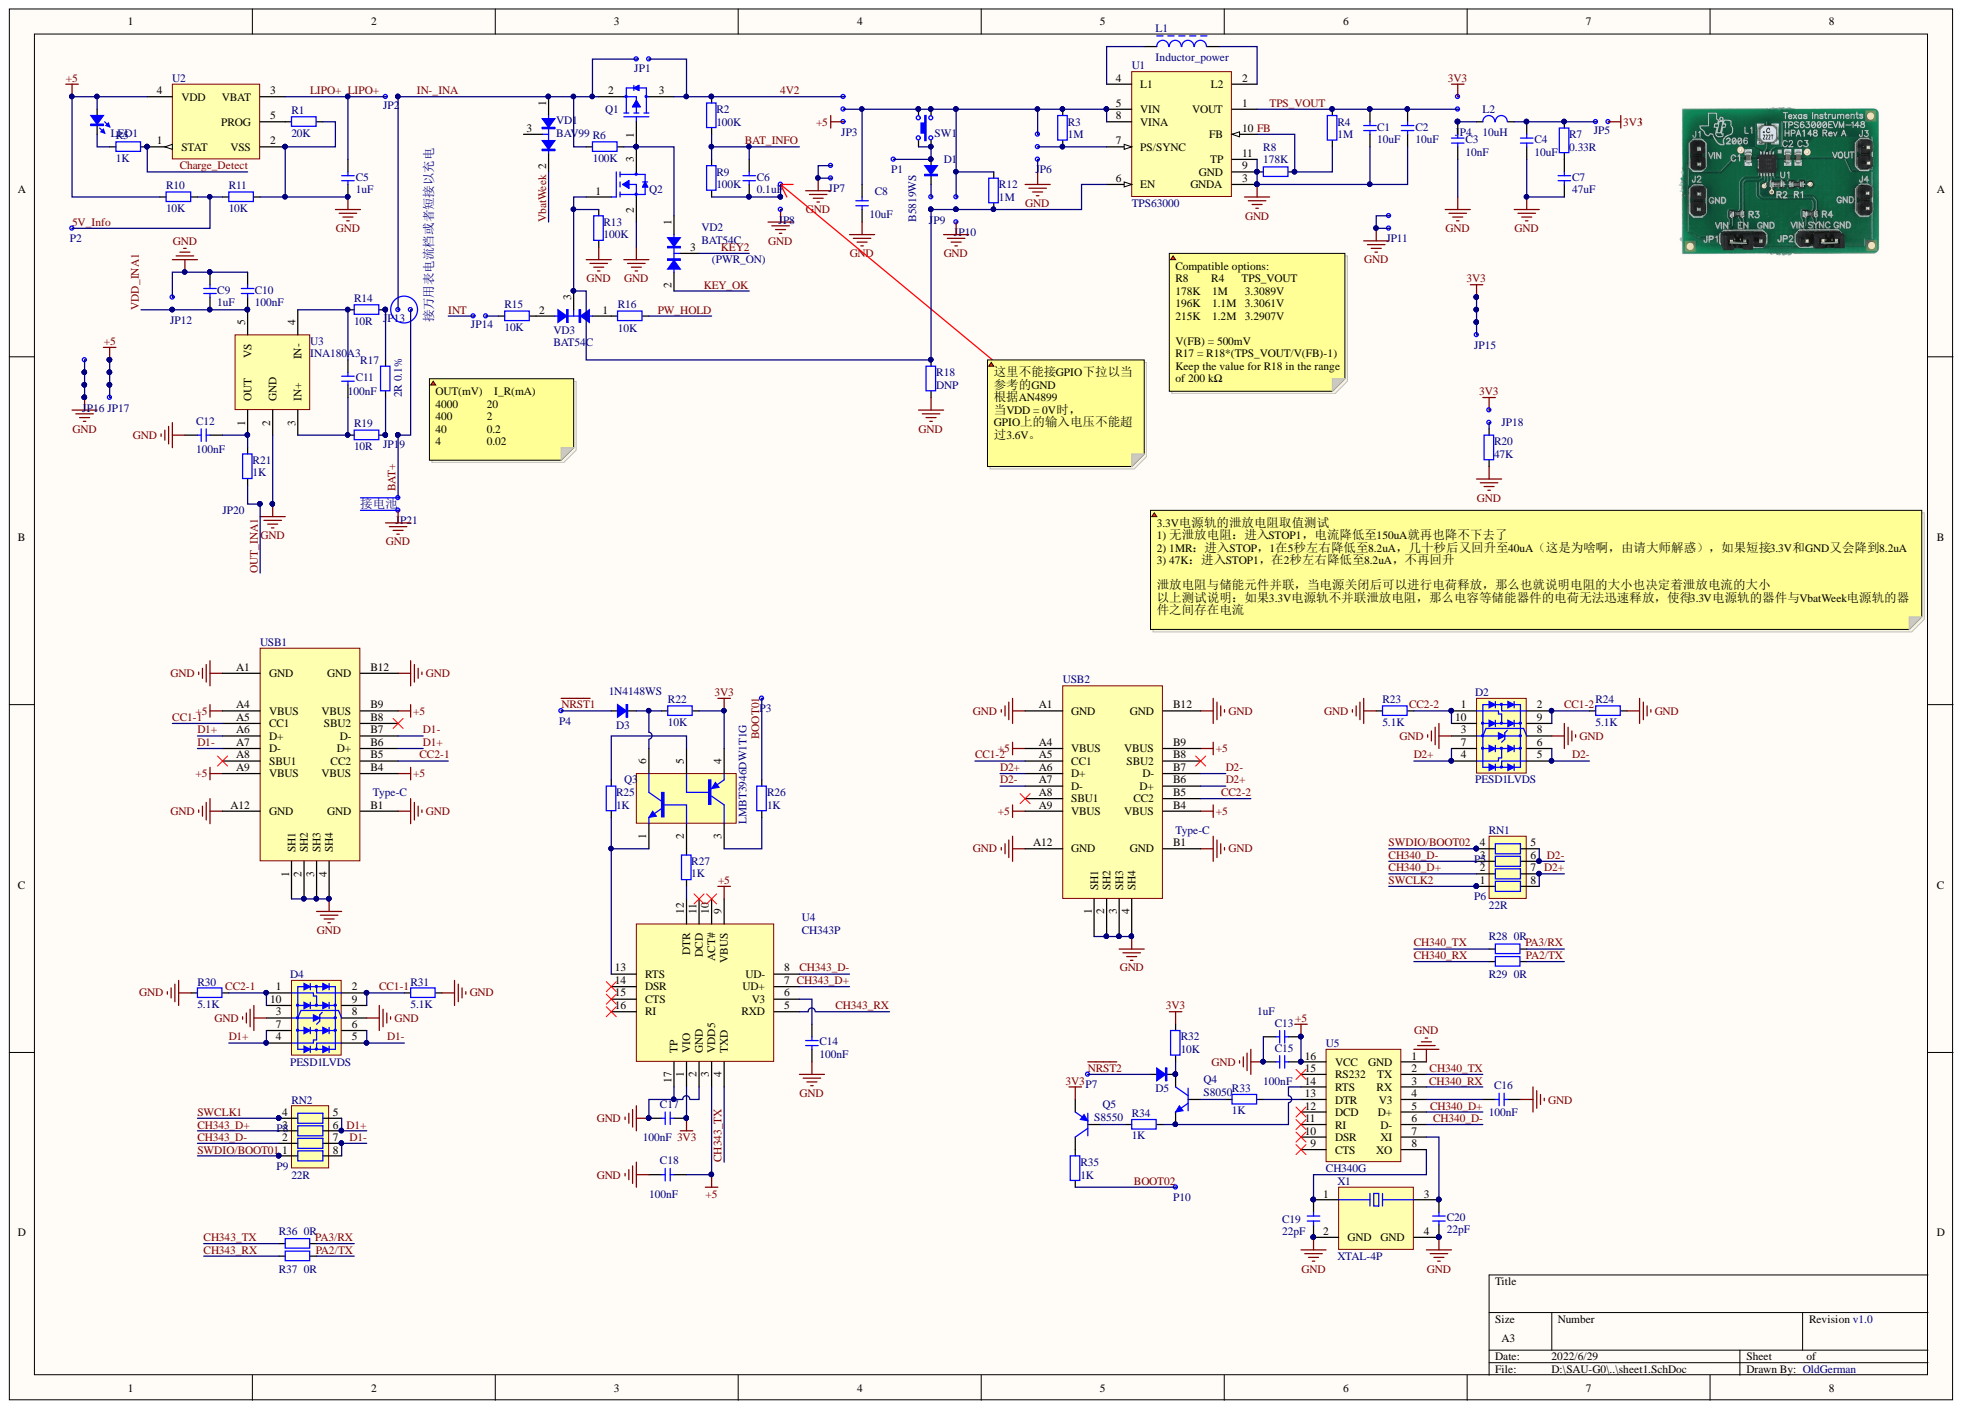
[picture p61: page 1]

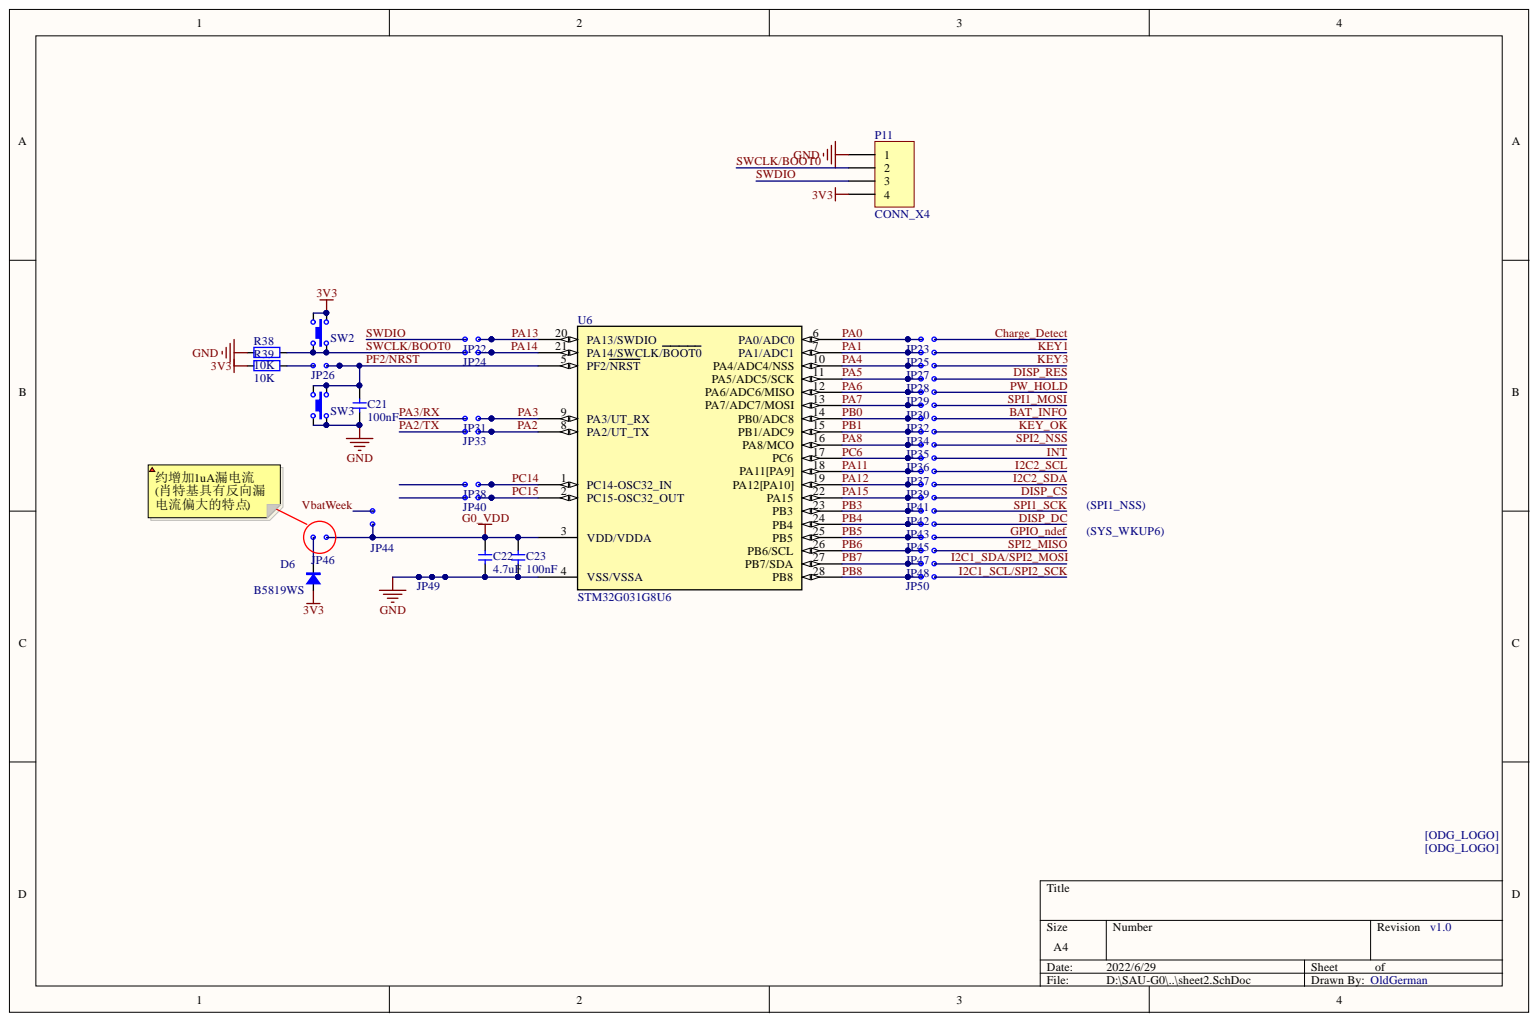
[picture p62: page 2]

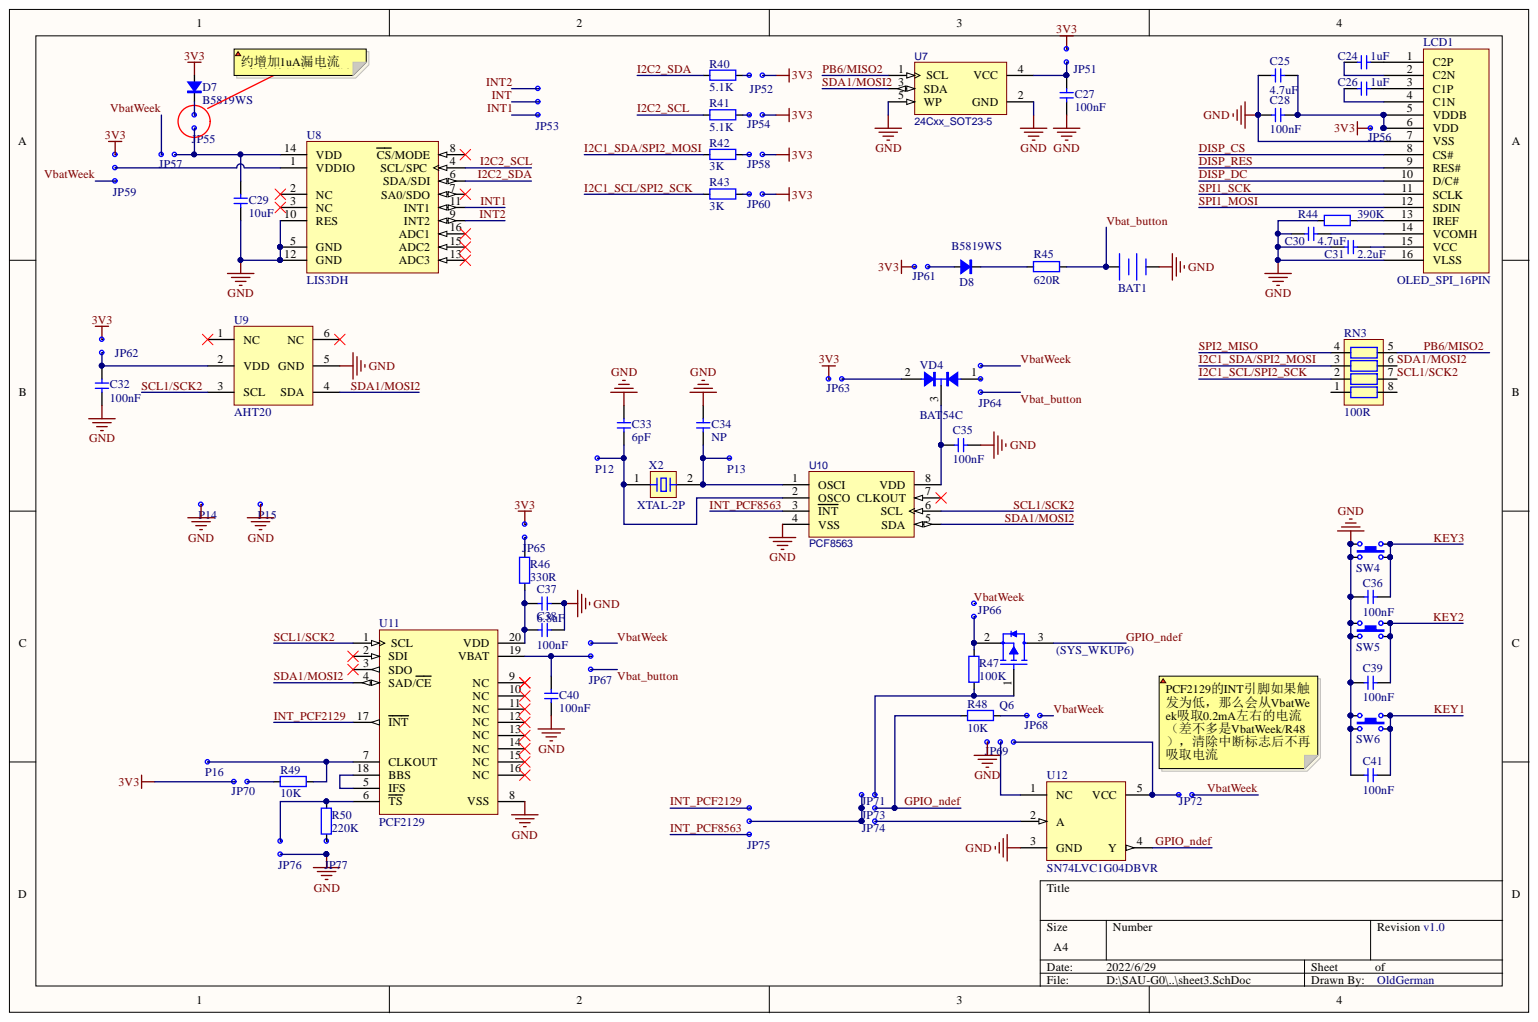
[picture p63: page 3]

JP56 | VDD 6

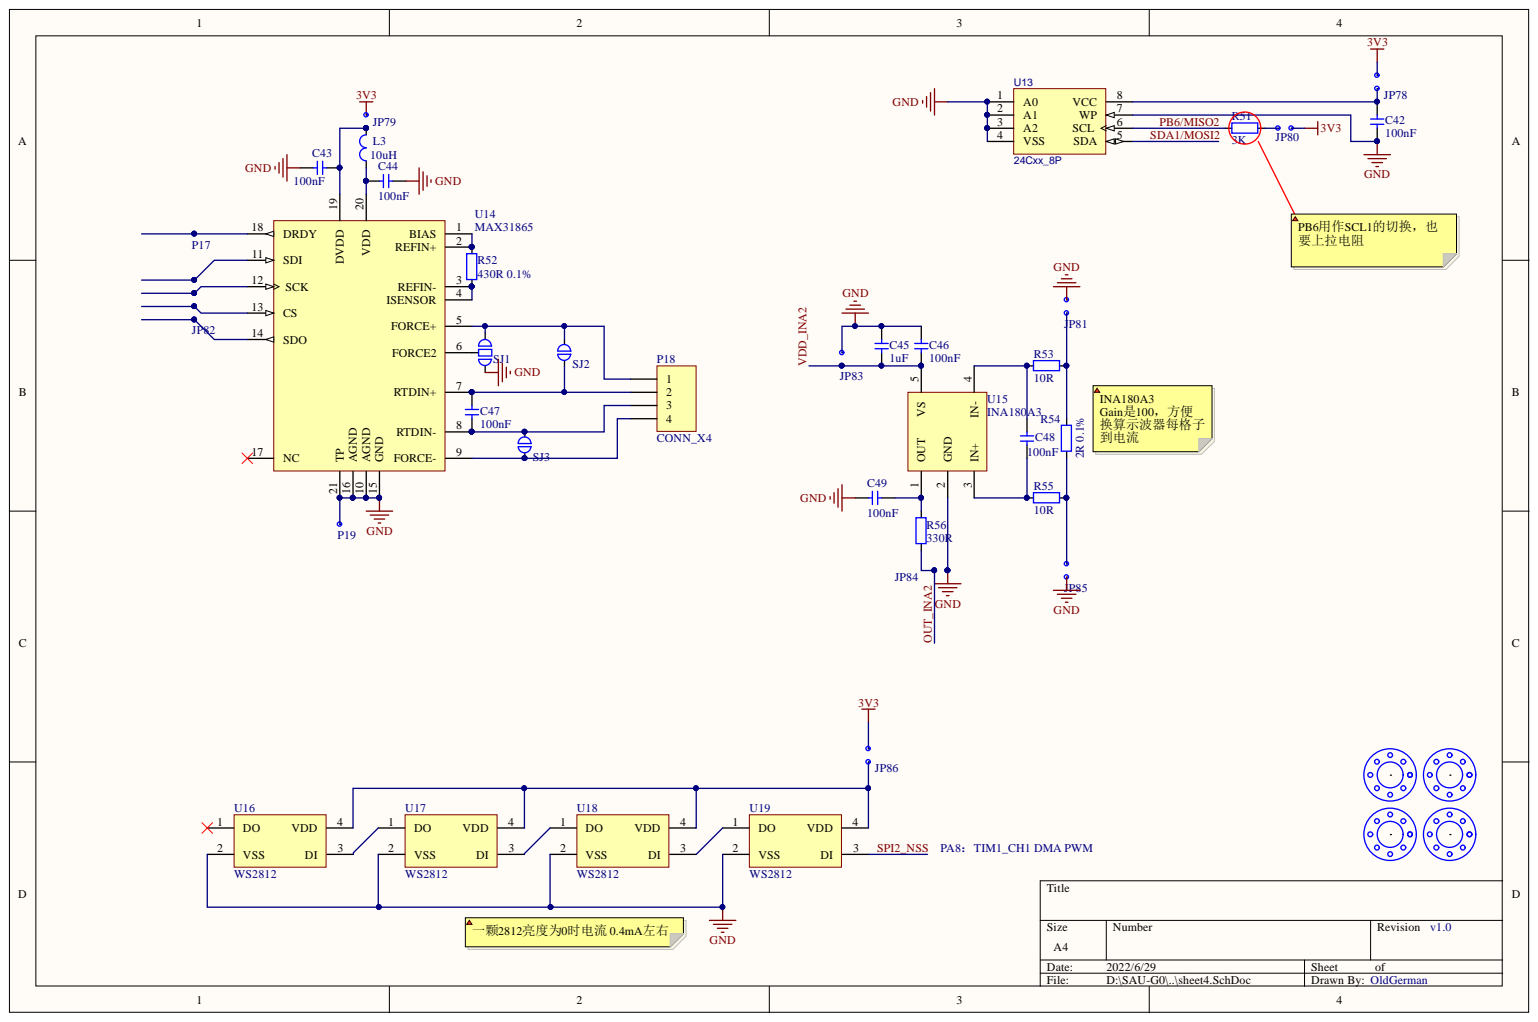
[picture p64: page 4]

C47
100nF

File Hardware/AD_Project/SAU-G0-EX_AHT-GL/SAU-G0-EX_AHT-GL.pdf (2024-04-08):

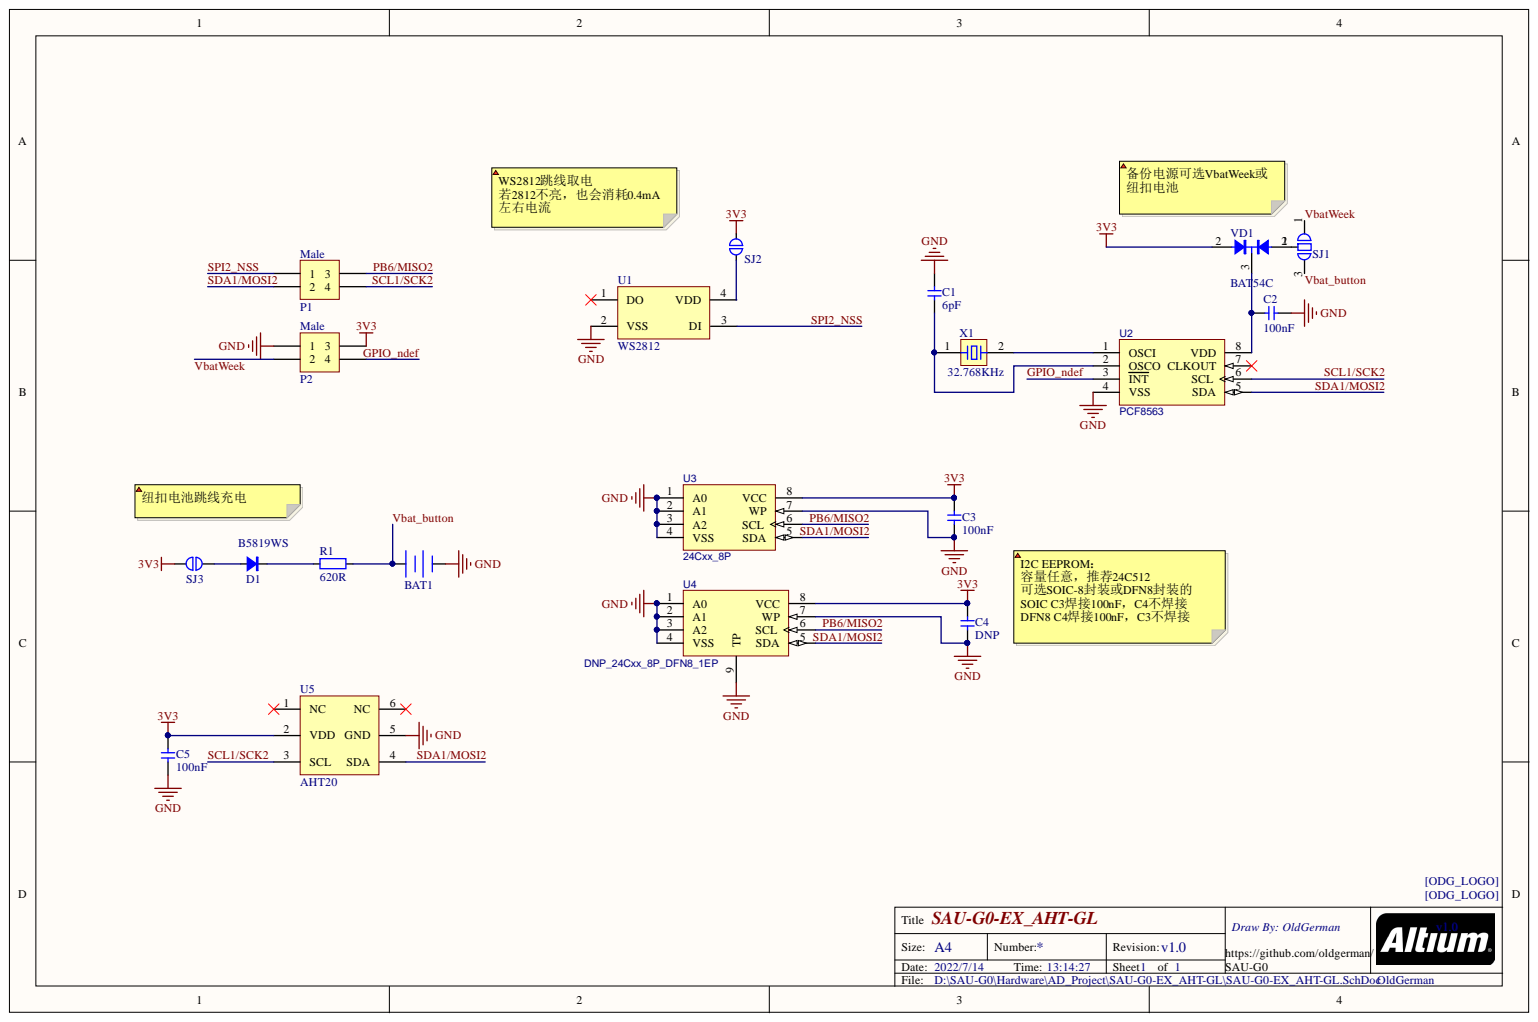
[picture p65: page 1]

SAU-G0-EX_AHT-GL Title | Draw By: OldGerman https://github.com/oldgerman/SAU-G0 | v1.0

A4 Size: | * Number: | v1.0 Revision:
Date: 2022/7/14 Time: 13:14:27 | | Sheet 1 of 1

D:\SAU-G0\Hardware\AD_Project\SAU-G0-EX_AHT-GL\SAU-G0-EX_AHT-GL.SchDoc

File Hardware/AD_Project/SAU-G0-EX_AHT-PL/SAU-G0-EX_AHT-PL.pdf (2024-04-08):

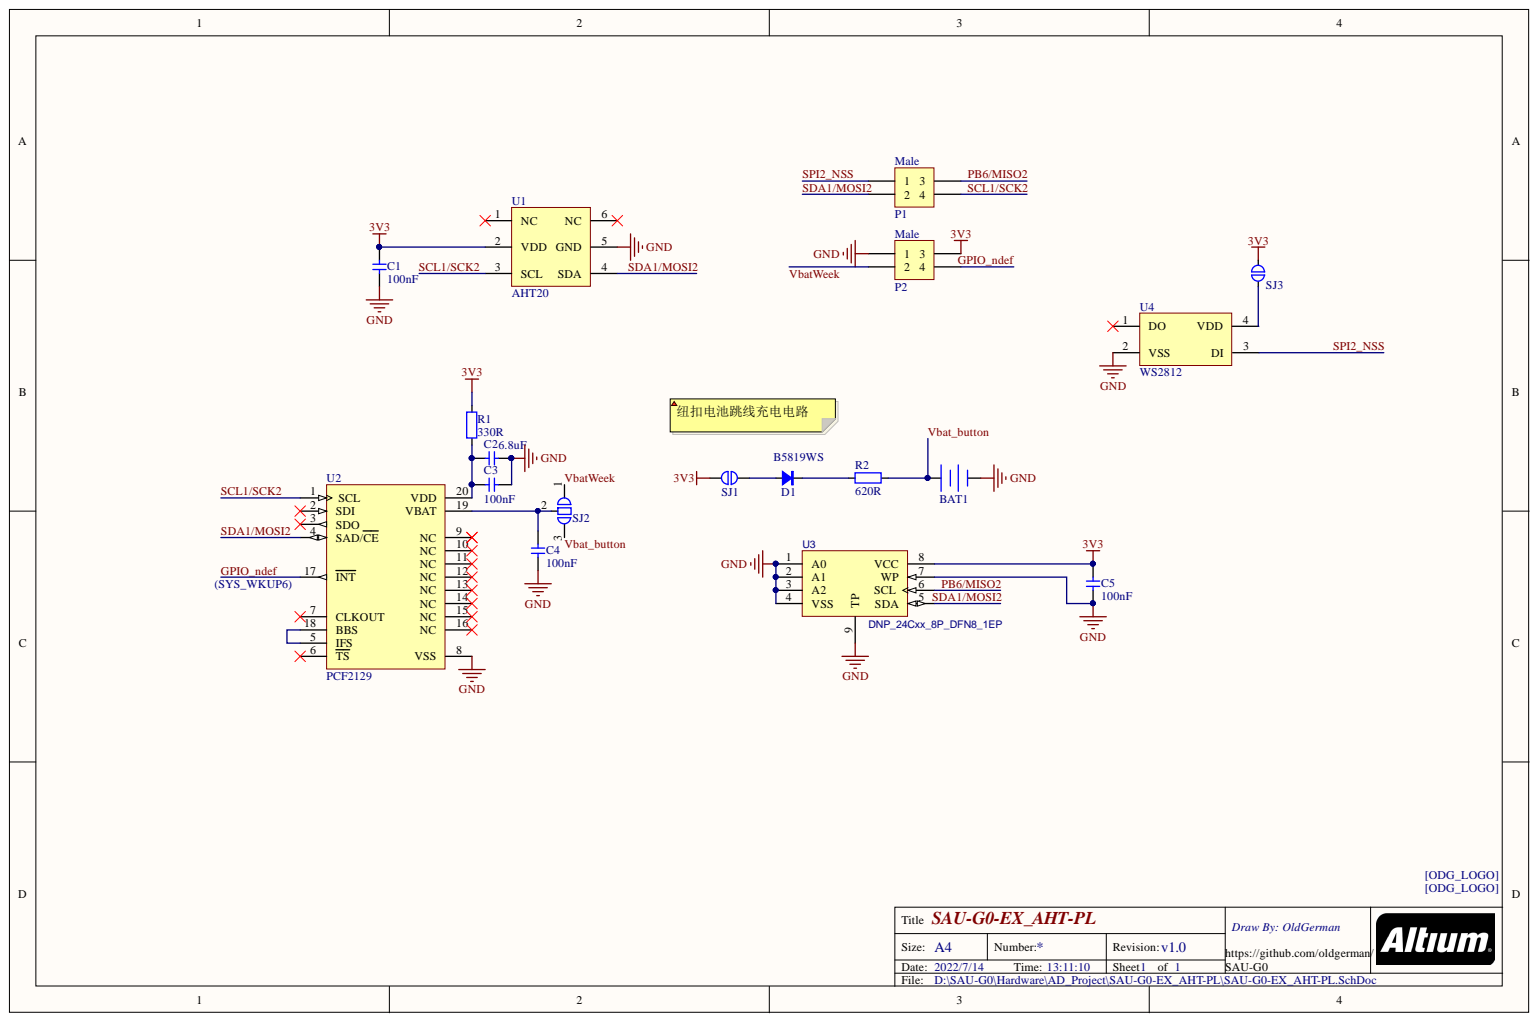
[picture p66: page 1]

SAU-G0-EX_AHT-PL Title | Draw By: OldGerman https://github.com/oldgerman/SAU-G0

A4 Size: | * Number: | v1.0 Revision:
Date: 2022/7/14 Time: 13:11:10 | | Sheet 1 of 1

D:\SAU-G0\Hardware\AD_Project\SAU-G0-EX_AHT-PL\SAU-G0-EX_AHT-PL.SchDoc

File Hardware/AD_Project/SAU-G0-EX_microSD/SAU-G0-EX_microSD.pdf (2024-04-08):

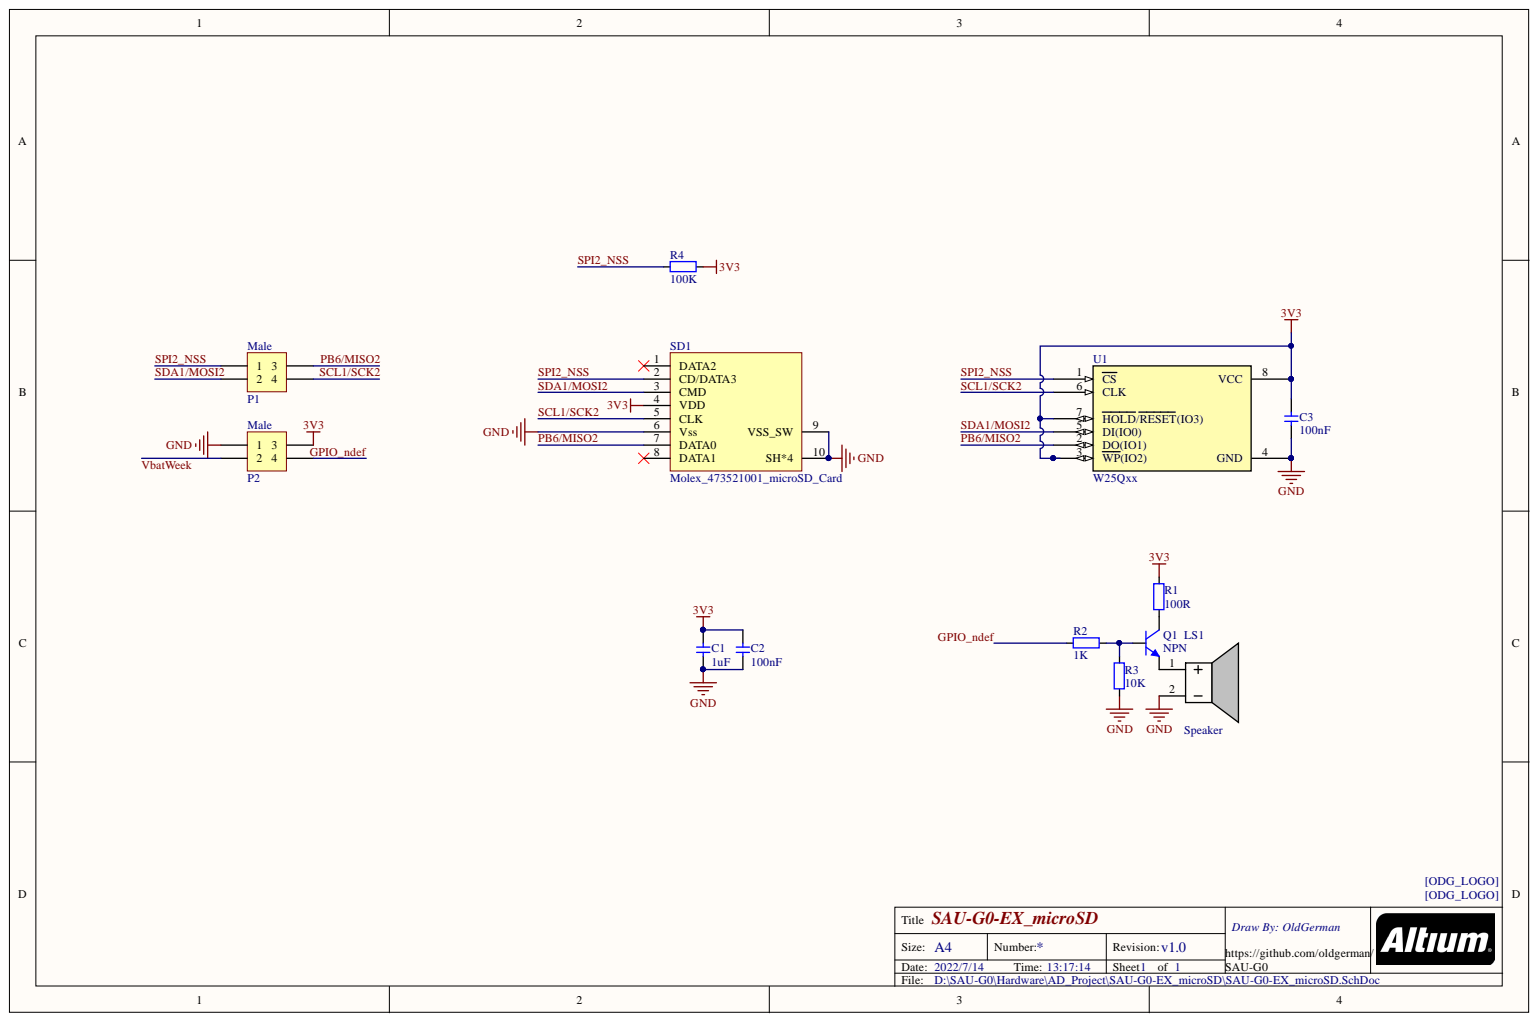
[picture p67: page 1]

SAU-G0-EX_microSD Title | Draw By: OldGerman https://github.com/oldgerman/SAU-G0

A4 Size: | * Number: | v1.0 Revision:
Date: 2022/7/14 Time: 13:17:14 | | Sheet 1 of 1

D:\SAU-G0\Hardware\AD_Project\SAU-G0-EX_microSD\SAU-G0-EX_microSD.SchDoc

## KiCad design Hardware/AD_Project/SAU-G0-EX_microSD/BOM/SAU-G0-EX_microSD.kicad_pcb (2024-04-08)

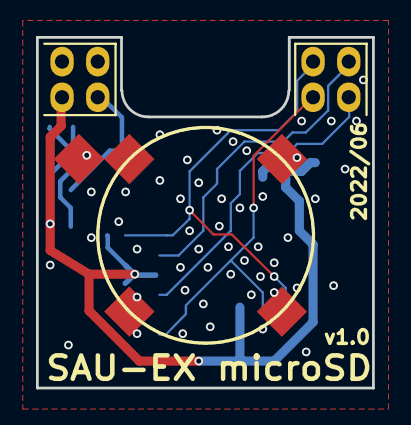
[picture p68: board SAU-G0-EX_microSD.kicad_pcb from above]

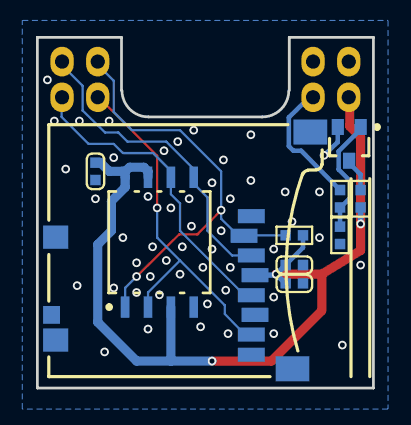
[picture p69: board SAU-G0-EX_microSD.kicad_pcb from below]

Board: 2 copper layers, 18.7 x 19.5 mm, 15 parts (11 on the bottom side), 10 nets.

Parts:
C1: 1uF; C0402_1
C2, C3: 100nF; C0402_1
LS1: 蜂鸣片12mm; С№µзМХґЙ·дГщЖ¬12MM_1
ODG1, ODG2: ODG_LOGO; ODG_LOGO_soldermask_1
P1: Male; 2.0MM_MALE_2X2_2
P2: Male; 2.0mm_Male_2x2_1
Q1: NPN; DIODES_SOT-323-3_1
R1: 100R; R0402_1
R2: 1K; R0402_1
R3: 10K; R0402_1
R4: 100K; R0402_1
SD1: Molex_473521001_microSD_Card; MOLEX_473521001_MICROSD_CARD_1
U1: W25Qxx; WIN_SS-8_WIN-L_1

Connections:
3V3: C1.2, C2.2, C3.1, P2.3, R1.2, R4.2, SD1.4, U1.3, U1.7, U1.8
GND: C1.1, C2.1, C3.2, LS1.2, LS1.2_1, LS1.2_2, LS1.2_3, P2.1, R3.1, SD1.6, SD1.9, SD1.10, SD1.10_1, SD1.10_2, SD1.10_3, U1.4
GPIO_ndef: P2.4, R2.1
NetLS1_1: LS1.1, Q1.2
NetQ1_1: Q1.1, R2.2, R3.2
NetQ1_3: Q1.3, R1.1
PB6_MISO2: P1.3, SD1.7, U1.2
SCL1_SCK2: P1.4, SD1.5, U1.6
SDA1_MOSI2: P1.2, SD1.3, U1.5
SPI2_NSS: P1.1, R4.1, SD1.2, U1.1

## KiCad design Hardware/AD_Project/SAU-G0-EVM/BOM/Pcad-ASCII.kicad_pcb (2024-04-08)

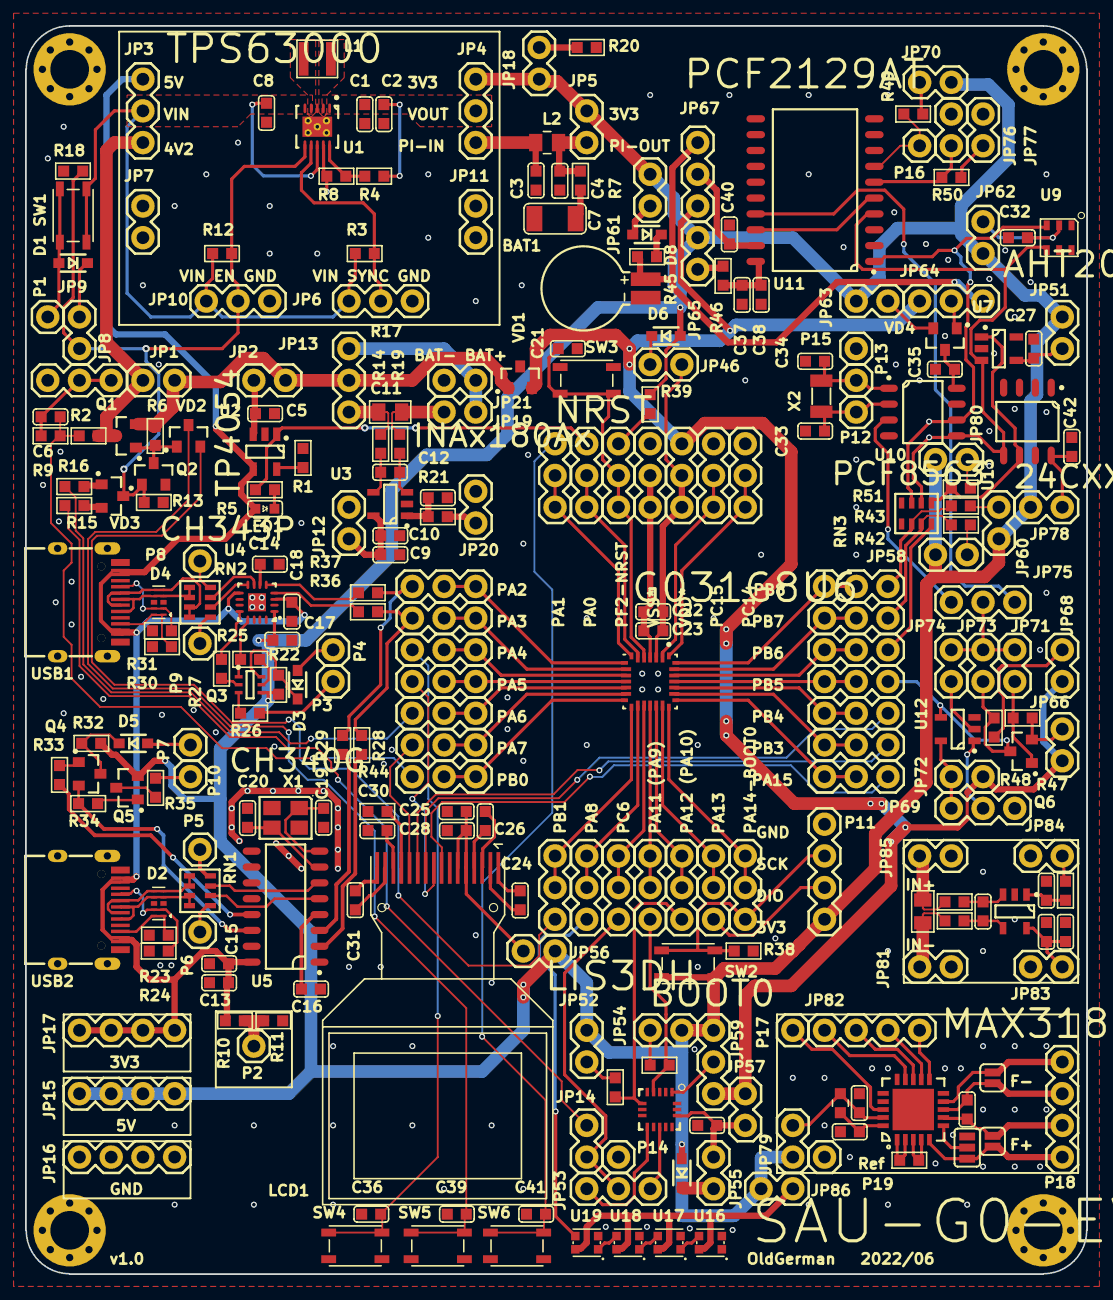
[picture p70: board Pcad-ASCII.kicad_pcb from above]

Board: 2 copper layers, 85.0 x 100.0 mm, 275 parts (1 on the bottom side), 203 nets.

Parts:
BAT1: BAT; MS621FE-FL11E_1
C1, C2, C4, C8, C29: 10uF; C0603_1
C3: 10nF; C0603_1
C5, C9, C13, C24, C26, C45: 1uF; C0603_1
C6: 0.1uF; C0603_1
C7: 47uF; C1206_1
C10, C11, C12, C14, C15, C16, C17, C18, C21, C23, C27, C28, C32, C35, C36, C38, C39, C40, C41, C42, C43, C44, C46, C47, C48, C49: 100nF; C0603_1
C19, C20: 22pF; C0603_1
C22, C25, C30: 4.7uF; C0603_1
C31: 2.2uF; C0603_1
C33: 6pF; C0603_1
C34: NP; C0603_1
C37: 6.8uF; C0603_1
D1, D8: B5819WS; SOD-323_1
D2, D4: PESD1LVDS; DFN2510-10_SOT1165-1_1
D3: 1N4148WS; SOD-323_4
D5: DIODE; SOD-323_3
D6: B5819WS; SOD-323_5
D7: B5819WS; SOD-323_2
JP1, JP46, JP56, JP58, JP61, JP70, JP80, JP81, JP84: CONN_X2_DOT; 2.54mm_Male_x2_5
JP2, JP19, JP54, JP72, JP78, JP83, JP85, JP86: CONN_X2_DOT; 2.54mm_Male_x2_4
JP3, JP27, JP28, JP29, JP30, JP32, JP49, JP69, JP75: CONN_X3_DOT; 2.54mm_Male_x3_2
JP4: CONN_X3_DOT; 2.54mm_Male_x3_9
JP5: CONN_X2_DOT; 2.54mm_Male_x2_8
JP6, JP10, JP53, JP64: CONN_X3_DOT; 2.54mm_Male_x3_6
JP7: CONN_X2_DOT; 2.54mm_Male_x2_9
JP8: CONN_X3_DOT; 2.54mm_Male_x3_1
JP9, JP12, JP51, JP57, JP60, JP65, JP68, JP73, JP74: CONN_X2_DOT; 2.54mm_Male_x2_1
JP11: CONN_X2_DOT; 2.54mm_Male_x2_10
JP13, JP24, JP25: CONN_X3_DOT; 2.54mm_Male_x3_3
JP14: CONN_X2_DOT; 2.54mm_Male_x2_2
JP15, JP16, JP17: CONN_X4_DOT; 2.54mm_Male_x4_1
JP18, JP20, JP52, JP55, JP62, JP63, JP66, JP71, JP76, JP77: CONN_X2_DOT; 2.54mm_Male_x2_3
JP21: CONN_X2_DOT; 2.54mm_Male_x2_7
JP22, JP23: CONN_X3_DOT; 2.54mm_Male_x3_8
JP26, JP34, JP35, JP36, JP37, JP38, JP39, JP40, JP44, JP59: CONN_X3_DOT; 2.54mm_Male_x3_4
JP31, JP33, JP41, JP42, JP43, JP45, JP47, JP48, JP50: CONN_X3_DOT; 2.54mm_Male_x3_7
JP67: CONN_X3_DOT; 2.54mm_Male_x3_5
JP79: CONN_X2_DOT; 2.54mm_Male_x2_6
JP82: CONN_X4_DOT; 2.54mm_Male_x4_2
L1: Inductor_power; IND-30301X_1
L2: 10uH; FER0805_1
L3: 10uH; FER0603_1
LCD1: OLED_SPI_16PIN; oled_64x48_0.66_SSD1306_TOP_6E
LED1: LED; LED0603_WHITE_1
ODG1, ODG2: ODG_LOGO; ODG_LOGO_soldermask_1
P1, P2, P5, P6, P8, P9, P12, P13, P14, P15, P16, P17, P19: CONN_X1_DOT; 2.54mm_Male_x1_1
P3, P4, P7: CONN_X1_DOT; 2.54mm_Male_x1_3
P10: CONN_X1_DOT; 2.54mm_Male_x1_2
P11: CONN_X4; 2.54mm_Male_x4_4
P18: CONN_X4; 2.54mm_Male_x4_3
Q1, Q6: P-MOS; INFINEON_SOT-23-3_1
Q2: N-MOS; INFINEON_SOT-23-3_1
Q3: LMBT3946DW1T1G; ON_SEMI_SOT-363_1
Q4: S8050; INFINEON_SOT-23-3_1
Q5: S8550; INFINEON_SOT-23-3_1
R1: 20K; R0603_1
R2, R6, R9, R13, R47: 100K; R0603_1
R3, R4, R12: 1M; R0603_1
R5, R21, R25, R26, R27, R33, R34, R35: 1K; R0603_1
R7: 0.33R; R0603_1
R8: 178K; R0603_1
R10, R11, R15, R16, R22, R32, R38, R39, R48, R49: 10K; R0603_1
R14, R19, R53, R55: 10R; R0603_1
R17, R54: 2R 0.1%; R0805_1
R18: DNP; R0603_1
R20: 47K; R0603_1
R23, R24, R30, R31, R40, R41: 5.1K; R0603_1
R28, R29, R36, R37: 0R; R0603_1
R42, R43, R51: 3K; R0603_1
R44: 390K; R0603_1
R45: 620R; R0603_1
R46, R56: 330R; R0603_1
R50: 220K; R0603_1
R52: 430R 0.1%; R0603_1
RN1, RN2: 22R; RESNET_1206-8_CONCAVE_1
RN3: 100R; RESNET_1206-8_CONCAVE_1
SJ1: SJ_3P; SJ_3P_1
SJ2, SJ3: SJ_2P; SJ_2P_1
SUN_HOLE1, SUN_HOLE2, SUN_HOLE3, SUN_HOLE4: SUN_HOLE; SUN_HOLE_M3_1
SW1, SW2, SW3, SW4, SW5, SW6: Button-4P; SWITCH_3X4X2.5_4PIN_SMD_1
U1: TPS63000; TI_PVSON-10_3x3MM_DRC_1
U2: MCP73831T; MICROCHIP_SOT-23-5_OT_1
U3, U15: INA180A3; TI_SOT-23-5_DBV_1
U4: CH343P; Analog_QFN-16_3x3MM_1
U5: CH340G; TI_SOP-16_D_1
U6: STM32G031G8U6; UFQFPN28-4x4mm_ODG_1
U7: 24Cxx_SOT23-5; MICROCHIP_SOT-23-5_OT_1
U8: LIS3DH; LGA-16-3X3_1
U9: AHT20; AHT20_1
U10: PCF8563; ANALOG_DEV_SOIC-8_R8_1
U11: PCF2129; NXP_SO20_1
U12: SN74LVC1G04DBVR; TI_SOT-23-5_DBV_1
U13: 24Cxx_8P; ANALOG_DEV_SOIC-8_R8_1
U14: MAX31865; VQFN-20_5x5MM_0.65_1
U16: WS2812; WS2812_2020_1
U17, U18, U19: WS2812; WS2812_2020_2
USB1, USB2: Type-C; Type-C-TOP_1
VD1: BAV99; INFINEON_SOT-23-3_1
VD2, VD3, VD4: BAT54C; INFINEON_SOT-23-3_1
X1: XTAL-4P; EPSON_TSX-3225_1
X2: XTAL-2P; XTAL_2P_3215_1

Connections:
3V3: C17.2, D6.1, D7.1, JP4.1, JP5.2, JP15.1, JP15.2, JP15.3, JP15.4, JP18.1, JP51.1, JP52.2, JP54.2, JP56.1, JP58.2, JP59.1, JP60.2, JP61.1, JP62.1, JP63.1, JP65.1, JP70.1, JP78.1, JP79.1, JP80.2, JP86.1, P11.4, Q3.4, Q5.2, R22.1, R32.1, R39.2, SW2.3, SW2.4, U4.1
4V2: JP1.2, JP3.1, Q1.3, R2.2
5V_Info: P2.1, R10.1, R11.2
+5: C13.2, C15.2, C18.2, JP3.3, JP17.1, JP17.2, JP17.3, JP17.4, LED1.1, R10.2, U2.4, U4.3, U4.9, U5.16, USB1.A4, USB1.A9, USB1.B4, USB1.B9, USB2.A4, USB2.A9, USB2.B4, USB2.B9
BAT+: JP13.3, JP19.2, JP21.1
BAT_INFO: C6.1, JP32.3, R2.1, R9.2
BOOT01: P3.1, R26.1
BOOT02: P10.1, R35.2
CC1-1: D4.2, D4.9, R31.2, USB1.A5
CC1-2: D2.2, D2.9, R24.2, USB2.A5
CC2-1: D4.1, D4.10, R30.1, USB1.B5
CC2-2: D2.1, D2.10, R23.1, USB2.B5
CH340_D+: RN1.2, U5.5
CH340_D-: RN1.3, U5.6
CH340_RX: R29.1, U5.3
CH340_TX: R28.1, U5.2
CH343_D+: RN2.3, U4.7
CH343_D-: RN2.2, U4.8
CH343_RX: R37.1, U4.5
CH343_TX: R36.1, U4.4
Charge_Detect: JP23.3, R5.1, U2.1
D1+: D4.4, D4.7, RN2.5, RN2.6, USB1.A6, USB1.B6
D1-: D4.5, D4.6, RN2.7, RN2.8, USB1.A7, USB1.B7
D2+: D2.4, D2.7, RN1.7, RN1.8, USB2.A6, USB2.B6
D2-: D2.5, D2.6, RN1.5, RN1.6, USB2.A7, USB2.B7
DISP_CS: JP41.3, LCD1.8
DISP_DC: JP43.3, LCD1.10
DISP_RES: JP28.3, LCD1.9
FB: R4.1, R8.1, U1.10
G0_VDD: C22.1, C23.1, JP44.2, JP44.3, JP46.1, U6.3
GND: BAT1.2, C1.2, C2.2, C3.1, C4.2, C5.2, C7.2, C8.2, C9.2, C10.2, C12.2, C13.1, C14.2, C15.1, C16.2, C17.1, C18.1, C19.1, C20.1, C21.2, C22.2, C23.2, C25.2, C27.2, C28.1, C29.2, C30.2, C31.2, C32.2, C33.1, C34.1, C35.2, C36.1, C37.2, C38.2, C39.1, C40.2, C41.1, C42.2, C43.2, C44.2, C45.2, C46.2, C49.2, D2.3, D2.8, D4.3, D4.8, JP6.3, JP7.1, JP7.2, JP8.3, JP10.3, JP11.1, JP11.2, JP12.1, JP16.1, JP16.2, JP16.3, JP16.4, JP20.2, JP21.2, JP49.1, JP49.2, JP49.3, JP69.1, JP76.2, JP77.2, JP81.1, JP83.1, JP84.2, JP85.2, LCD1.7, LCD1.16, P11.1, P14.1, P15.1, P19.1, Q2.2, R1.1, R8.2, R11.1, R13.1, R18.1, R20.1, R23.2, R24.1, R30.2, R31.1, R38.2, R44.1, SJ1.3, SW3.1, SW3.2, SW4.1, SW4.2, SW5.1, SW5.2, SW6.1, SW6.2, U1.3, U1.9, U1.11, U1.V:Ex24y24d121, U2.2, U3.2, U4.2, U4.17, U5.1, U6.4, U7.2, U7.5, U8.5, U8.10, U8.12, U9.5, U10.4, U11.8, U12.3, U13.1, U13.2, U13.3, U13.4, U13.7, U14.10, U14.15, U14.16, U14.21, U15.2, U16.2, U17.2, U18.2, U19.2, USB1.1, USB1.2, USB1.3, USB1.4, USB1.A1, USB1.A12, USB1.B1, USB1.B12, USB2.1, USB2.2, USB2.3, USB2.4, USB2.A1, USB2.A12, USB2.B1, USB2.B12, X1.2, X1.4
GPIO_ndef: JP45.3, JP73.2, Q6.3, R48.2, U12.4
I2C1_SCL_SPI2_SCK: JP50.3, R43.2, RN3.2
I2C1_SDA_SPI2_MOSI: JP48.3, R42.2, RN3.3
I2C2_SCL: JP37.3, R41.2, U8.4
I2C2_SDA: JP39.3, R40.2, U8.6
IN-_INA: JP1.1, JP2.2, JP13.2, Q1.2, R6.2, VD1.1
INT: JP14.1, JP36.3, JP53.2
INT1: JP53.3, U8.11
INT2: JP53.1, U8.9
INT_PCF2129: JP75.1, U11.17
INT_PCF8563: JP75.3, U10.3
KEY1: C41.2, JP25.3, SW6.3, SW6.4
KEY2: C39.2, SW5.3, SW5.4, VD2.3
KEY3: C36.2, JP27.3, SW4.3, SW4.4
KEY_OK: JP34.3, VD2.2
LIPO+: C5.1, JP2.1, U2.3
N_R_S_T_1: D3.1, P4.1
N_R_S_T_2: D5.1, P7.1
NetC3_2: C3.2, JP4.3, L2.1
NetC4_1: C4.1, JP5.1, L2.2, R7.2
NetC6_2: C6.2, JP8.1, JP8.2, R9.1
NetC7_1: C7.1, R7.1
NetC8_1: C8.1, JP3.2, JP6.1, JP10.1, R3.1, R12.1, SW1.3, SW1.4, U1.5, U1.8
NetC11_1: C11.1, R19.1, U3.3
NetC11_2: C11.2, R14.1, U3.4
NetC12_1: C12.1, R21.2, U3.1
NetC14_1: C14.1, U4.6
NetC16_1: C16.1, U5.4
NetC19_2: C19.2, U5.8, X1.1
NetC20_2: C20.2, U5.7, X1.3
NetC24_1: C24.1, LCD1.1
NetC24_2: C24.2, LCD1.2
NetC25_1: C25.1, C28.2, JP56.2, LCD1.5, LCD1.6
NetC26_1: C26.1, LCD1.3
NetC26_2: C26.2, LCD1.4
NetC27_1: C27.1, JP51.2, U7.4
NetC29_1: C29.1, JP55.2, JP57.2, U8.14
NetC30_1: C30.1, LCD1.14
NetC31_1: C31.1, LCD1.15
NetC32_1: C32.1, JP62.2, U9.2
NetC33_2: C33.2, P12.1, U10.2, X2.1
NetC34_2: C34.2, P13.1, U10.1, X2.2
NetC35_1: C35.1, U10.8, VD4.3
NetC37_1: C37.1, C38.1, R46.1, U11.20
NetC40_1: C40.1, JP67.2, U11.19
NetC42_1: C42.1, JP78.2, U13.8
NetC43_1: C43.1, JP79.2, L3.2, U14.19
NetC44_1: C44.1, L3.1, U14.20
NetC47_1: C47.1, P18.2, SJ2.2, U14.7
NetC47_2: C47.2, P18.3, SJ3.1, U14.8
NetC48_1: C48.1, R55.1, U15.3
NetC48_2: C48.2, R53.1, U15.4
NetC49_1: C49.1, R56.2, U15.1
NetD1_1: D1.1, P1.1, SW1.1, SW1.2
NetD1_2: D1.2, JP9.1
NetD3_2: D3.2, Q3.6, R22.2
NetD5_2: D5.2, Q4.3, R32.2
NetD6_2: D6.2, JP46.2
NetD7_2: D7.2, JP55.1
NetD8_1: D8.1, JP61.2
NetD8_2: D8.2, R45.1
NetJP6_2: JP6.2, R3.2, U1.7
NetJP9_2: JP9.2, JP10.2, Q2.1, R12.2, R13.2, R18.2, U1.6, VD3.3
NetJP13_1: JP13.1, R14.2, R17.1
NetJP14_2: JP14.2, R15.1
NetJP18_2: JP18.2, R20.2
NetJP19_1: JP19.1, R17.2, R19.2
NetJP26_1: JP26.1, R39.1
NetJP52_1: JP52.1, R40.1
NetJP54_1: JP54.1, R41.1
NetJP58_1: JP58.1, R42.1
NetJP59_2: JP59.2, U8.1
NetJP60_1: JP60.1, R43.1
NetJP63_2: JP63.2, VD4.2
NetJP64_2: JP64.2, VD4.1
NetJP65_2: JP65.2, R46.2
NetJP66_2: JP66.2, Q6.2, R47.2
NetJP68_1: JP68.1, R48.1
NetJP69_2: JP69.2, U12.1
NetJP69_3: JP69.3, JP72.1, U12.5
NetJP70_2: JP70.2, R49.2
NetJP71_1: JP71.1, JP73.1, JP74.1, JP75.2
NetJP71_2: JP71.2, Q6.1, R47.1
NetJP74_2: JP74.2, U12.2
NetJP76_1: JP76.1, R50.2, U11.6
NetJP77_1: JP77.1, R50.1
NetJP80_1: JP80.1, R51.2
NetJP81_2: JP81.2, R53.2, R54.1
NetJP82_1: JP82.1, U14.11
NetJP82_2: JP82.2, U14.12
NetJP82_3: JP82.3, U14.13
NetJP82_4: JP82.4, U14.14
NetJP85_1: JP85.1, R54.2, R55.2
NetJP86_2: JP86.2, U16.4, U17.4, U18.4, U19.4
NetL1_1: L1.1, U1.4
NetL1_2: L1.2, U1.2
NetLCD1_13: LCD1.13, R44.2
NetLED1_2: LED1.2, R5.2
NetP16_1: P16.1, R49.1, U11.7
NetP17_1: P17.1, U14.18
NetP18_1: P18.1, SJ1.1, SJ2.1, U14.5
NetP18_4: P18.4, SJ3.2, U14.9
NetQ1_1: Q1.1, Q2.3, R6.1, VD2.1
NetQ3_1: Q3.1, R25.2, U4.13
NetQ3_2: Q3.2, R27.2
NetQ3_3: Q3.3, R26.2
NetQ3_5: Q3.5, R25.1
NetQ4_1: Q4.1, R33.1
NetQ4_2: Q4.2, R34.2, U5.14
NetQ5_1: Q5.1, R34.1
NetQ5_3: Q5.3, R35.1
NetR1_2: R1.2, U2.5
NetR15_2: R15.2, VD3.2
NetR16_2: R16.2, VD3.1
NetR27_1: R27.1, U4.12
NetR33_2: R33.2, U5.13
NetR52_1: R52.1, U14.3, U14.4
NetR52_2: R52.2, U14.1, U14.2
NetSJ1_2: SJ1.2, U14.6
NetU11_5: U11.5, U11.18
NetU16_3: U16.3, U17.1
NetU17_3: U17.3, U18.1
NetU18_3: U18.3, U19.1
OUT_INA1: JP20.1, R21.1
OUT_INA2: JP84.1, R56.1
PA0: JP23.1, JP23.2, U6.6
PA1: JP25.1, JP25.2, U6.7
PA2: JP33.2, JP33.3, U6.8
PA2_TX: JP33.1, R29.2, R37.2
PA3: JP31.2, JP31.3, U6.9
PA3_RX: JP31.1, R28.2, R36.2
PA4: JP27.1, JP27.2, U6.10
PA5: JP28.1, JP28.2, U6.11
PA6: JP29.1, JP29.2, U6.12
PA7: JP30.1, JP30.2, U6.13
PA8: JP35.1, JP35.2, U6.16
PA11: JP37.1, JP37.2, U6.18
PA12: JP39.1, JP39.2, U6.19
PA13: JP22.2, JP22.3, U6.20
PA14: JP24.2, JP24.3, U6.21
PA15: JP41.1, JP41.2, U6.22
PB0: JP32.1, JP32.2, U6.14
PB1: JP34.1, JP34.2, U6.15
PB3: JP42.1, JP42.2, U6.23
PB4: JP43.1, JP43.2, U6.24
PB5: JP45.1, JP45.2, U6.25
PB6: JP47.1, JP47.2, U6.26
PB6_MISO2: R51.1, RN3.5, U7.1, U13.6
PB7: JP48.1, JP48.2, U6.27
PB8: JP50.1, JP50.2, U6.28
PC6: JP36.1, JP36.2, U6.17
PC14: JP38.2, JP38.3, U6.1
PC15: JP40.2, JP40.3, U6.2
PF2_N_R_S_T_: C21.1, JP26.2, JP26.3, SW3.3, SW3.4, U6.5
PW_HOLD: JP29.3, R16.1
SCL1_SCK2: RN3.7, U9.3, U10.6, U11.1
SDA1_MOSI2: RN3.6, U7.3, U9.4, U10.5, U11.4, U13.5
SPI1_MOSI: JP30.3, LCD1.12
SPI1_SCK: JP42.3, LCD1.11
SPI2_MISO: JP47.3, RN3.4
SPI2_NSS: JP35.3, U19.3
SWCLK1: P8.1, RN2.4
SWCLK2: P6.1, RN1.1
SWCLK_BOOT0: JP24.1, P11.2, R38.1, SW2.1, SW2.2
SWDIO: JP22.1, P11.3
SWDIO_BOOT01: P9.1, RN2.1
SWDIO_BOOT02: P5.1, RN1.4
TPS_VOUT: C1.1, C2.1, JP4.2, R4.2, U1.1
VDD_INA1: C9.1, C10.1, JP12.2, U3.5
VDD_INA2: C45.1, C46.1, JP83.2, U15.5
VbatWeek: JP44.1, JP57.1, JP59.3, JP64.1, JP66.1, JP67.1, JP68.2, JP72.2, VD1.2
Vbat_button: BAT1.1, JP64.3, JP67.3, R45.2

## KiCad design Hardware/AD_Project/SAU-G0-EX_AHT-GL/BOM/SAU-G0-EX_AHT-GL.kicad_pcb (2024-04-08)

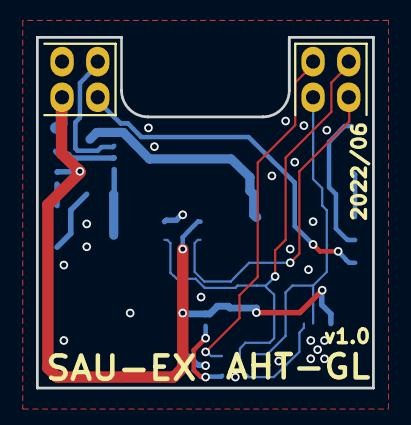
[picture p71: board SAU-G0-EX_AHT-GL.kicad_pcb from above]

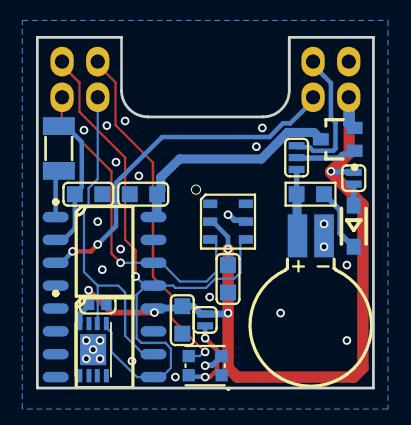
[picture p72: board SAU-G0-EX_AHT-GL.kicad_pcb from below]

Board: 2 copper layers, 18.7 x 19.5 mm, 22 parts (19 on the bottom side), 16 nets.

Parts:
BAT1: BAT; MS621FE-FL11E_1
C1: 6pF; C0603_1
C2, C3, C5: 100nF; C0603_1
C4: DNP; C0402_1
D1: B5819WS; SOD-323_1
ODG1, ODG2: ODG_LOGO; ODG_LOGO_soldermask_1
P1: Male; 2.0MM_MALE_2X2_2
P2: Male; 2.0mm_Male_2x2_1
R1: 620R; R0603_1
SJ1: SJ_3P; SJ_3P_MINI_1
SJ2, SJ3: SJ_2P; SJ_2P_MINI_1
U1: WS2812; WS2812_2020_1
U2: PCF8563; ANALOG_DEV_SOIC-8_R8_1
U3: 24Cxx_8P; ANALOG_DEV_SOIC-8_R8_1
U4: DNP_24Cxx_8P_DFN8_1EP; DFN-8-1EP_3x2mm_P0.5mm_EP1.70C
U5: AHT20; AHT20_1
VD1: BAT54C; DIODES_SOT-323-3_1
X1: 32.768KHz; XTAL_2P_3215_1

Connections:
3V3: C3.1, C4.1, C5.1, P2.3, SJ2.1, SJ3.2, U3.8, U4.8, U5.2, VD1.2
GND: BAT1.2, C1.1, C2.2, C3.2, C4.2, C5.2, P2.1, U1.2, U2.4, U3.1, U3.2, U3.3, U3.4, U3.7, U4.1, U4.2, U4.3, U4.4, U4.7, U4.9, U5.5
GPIO_ndef: P2.4, U2.3
NetC1_2: C1.2, U2.2, X1.1
NetC2_1: C2.1, U2.8, VD1.3
NetD1_1: D1.1, SJ3.1
NetD1_2: D1.2, R1.1
NetSJ1_2: SJ1.2, VD1.1
NetSJ2_2: SJ2.2, U1.4
NetU2_1: U2.1, X1.2
PB6_MISO2: P1.3, U3.6, U4.6
SCL1_SCK2: P1.4, U2.6, U5.3
SDA1_MOSI2: P1.2, U2.5, U3.5, U4.5, U5.4
SPI2_NSS: P1.1, U1.3
VbatWeek: P2.2, SJ1.1
Vbat_button: BAT1.1, R1.2, SJ1.3

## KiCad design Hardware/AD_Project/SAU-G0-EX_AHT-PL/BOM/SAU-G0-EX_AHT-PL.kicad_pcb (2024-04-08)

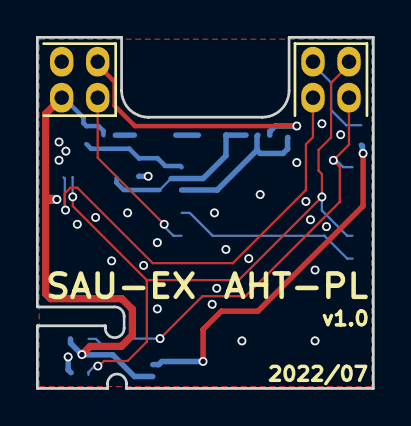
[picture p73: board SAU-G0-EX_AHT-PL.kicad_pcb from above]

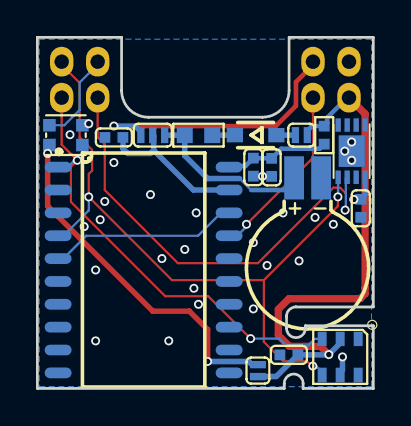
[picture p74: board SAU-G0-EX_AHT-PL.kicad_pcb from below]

Board: 2 copper layers, 18.7 x 19.5 mm, 20 parts (17 on the bottom side), 15 nets.

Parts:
BAT1: BAT; MS621FE-FL11E_1
C1, C3, C4, C5: 100nF; C0402_1
C2: 6.8uF; C0402_1
D1: B5819WS; SOD-323_1
ODG1, ODG2: ODG_LOGO; ODG_LOGO_soldermask_1
P1: Male; 2.0MM_MALE_2X2_2
P2: Male; 2.0mm_Male_2x2_1
R1: 330R; R0402_1
R2: 620R; R0603_1
SJ1, SJ3: SJ_2P; SJ_2P_MINI_1
SJ2: SJ_3P; SJ_3P_MINI_1
U1: AHT20; AHT20_1
U2: PCF2129; NXP_SO20_1
U3: DNP_24Cxx_8P_DFN8_1EP; DFN-8-1EP_3x2mm_P0.5mm_EP1.70C
U4: WS2812; WS2812_2020_1

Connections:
3V3: C1.1, C5.1, P2.3, R1.2, SJ1.2, SJ3.1, U1.2, U3.8
GND: BAT1.2, C1.2, C2.2, C3.2, C4.2, C5.2, P2.1, U1.5, U2.8, U3.1, U3.2, U3.3, U3.4, U3.7, U3.9, U4.2
GPIO_ndef: P2.4, U2.17
NetC2_1: C2.1, C3.1, R1.1, U2.20
NetC4_1: C4.1, SJ2.2, U2.19
NetD1_1: D1.1, SJ1.1
NetD1_2: D1.2, R2.1
NetSJ3_2: SJ3.2, U4.4
NetU2_5: U2.5, U2.18
PB6_MISO2: P1.3, U3.6
SCL1_SCK2: P1.4, U1.3, U2.1
SDA1_MOSI2: P1.2, U1.4, U2.4, U3.5
SPI2_NSS: P1.1, U4.3
VbatWeek: P2.2, SJ2.1
Vbat_button: BAT1.1, R2.2, SJ2.3

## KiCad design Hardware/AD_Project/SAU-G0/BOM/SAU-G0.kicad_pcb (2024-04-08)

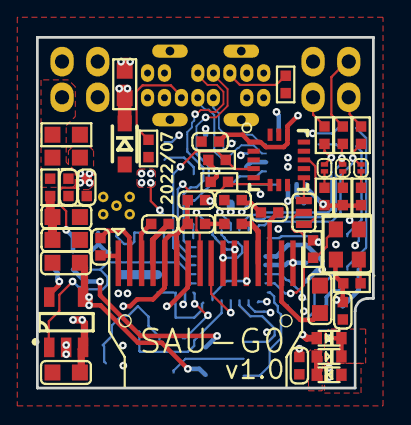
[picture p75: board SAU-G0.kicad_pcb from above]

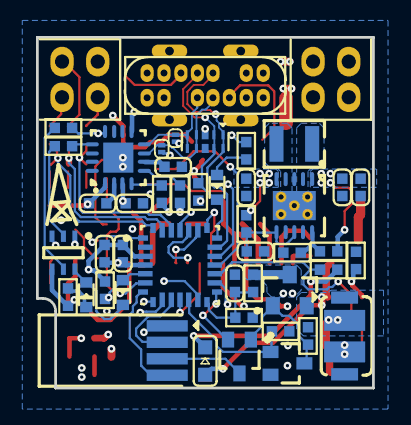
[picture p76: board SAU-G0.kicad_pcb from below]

Board: 4 copper layers, 18.7 x 19.5 mm, 93 parts (47 on the bottom side), 76 nets.

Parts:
C1, C2, C6, C7, C8: 10uF; C0402_1
C3, C20: 4.7uF; C0603_1
C4, C5, C14, C23: 0.1uF; C0402_1
C9, C17: 22uF; C0603_1
C10, C12: 1uF/16V; C0402_1
C11, C19, C21: 1uF; C0402_1
C13, C16, C18: 100nF; C0402_1
C15: 2.2uF/16V; C0603_1
C22: 4.7uF; C0402_1
C24: 10nF; C0402_1
C25, C26: 10uF/10V; C0402_1
D1: PESD1LVDS; DFN2510-10_SOT1165-1_1
D2: 1N4148WT; SOD-523_5
D3: RB521S-30; SOD-523_1
D4: 1N4148WT; SOD-523_4
D5: 1N4148WT; SOD-523_3
D7: 1N4148WT; SOD-523_2
D8: 1N4148WT; SOD-523_1
D9: SD05; SOD-323_1
F1: 6V/500mA; FUSE0603_0.5MM_1
FPC1: CONN_X4_FPC_Button_X3; FPC_Buttons_X3_Flip_to_PCB_B61
L1: 2.2uH; TAIYO_YUDEN_MAMK2520T1R0M_1
L2: 10uH; FER0603_1
LCD1: OLED_SPI_16PIN; OLED_64X48_0.66_SSD1306_TOP_43
LED1: LED; LED0603_WHITE_1
ODG4: ODG_LOGO; ODG_LOGO_1
P1: Female; 2.0MM_FMALE_2X2_2
P3: Female; 2.0mm_Fmale_2x2_1
P5: CONN_X2_TE; TE-198181x_Female+Male_1
Q1: SI2301; INFINEON_SOT-23-3_1
Q2: 2N7002KW; DIODES_SOT-323-3_1
Q3: LMBT3946DW1T1G; ON_SEMI_SOT-363_1
R1: 20K; R0402_1
R2, R7, R8, R9: 100K; R0402_1
R3, R13, R27, R29, R30: 100R; R0402_1
R4, R15, R16, R20: 1K; R0402_1
R5: 0~1R; R0402_1
R6: 47K; R0603_1
R10, R14, R28, R32: 10K; R0402_1
R11, R12, R22, R23, R31: 4.7K; R0402_1
R17: 1M/1.1M/1.2M（与R18一一对应）; R0402_1
R18: 178K/196K/215K（与R17一一对应）; R0402_1
R19: 390K; R0402_1
R21, R24: 5.1K; R0402_1
R25, R26: 0R; R0402_1
SJ1: SJ_3P; SJ_3P_MINI_1
SJ2, SJ3, SJ4, SJ5, SJ6: SJ_2P; SJ_2P_TINY_1
U1: MCP73831T; MICROCHIP_SOT-23-5_OT_1
U2: LIS3DH; LGA-16-3X3_1
U3: TPS63000/TPS63001（TPS63001 R17: 0R, R18: DNP）; TI_PVSON-10_3x3MM_DRC_1
U4: CH343P; CH343P_QFN-16_3x3MM_1
U5: STM32G031G8U6; UFQFPN28-4x4mm_ODG_1
USB1: Type-C; TYPE-C_14P_Vertical_H_10mm_1
VD2: BAT54C; DIODES_SOT-323-3_1
X1: XTAL-4P; NDK_NX2520SA_1

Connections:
3V3: C8.1, C11.1, C13.2, C16.1, C19.2, D3.1, L2.2, LCD1.5, LCD1.6, P3.1, Q3.4, R5.2, R6.2, R11.1, R12.1, R14.1, R22.1, R23.1, R28.2, R31.1, U4.1, X1.4
4V2: C1.1, Q1.3, R2.2, R3.2, U3.5
+5: C20.1, C21.2, D9.2, F1.2, LED1.1, U1.4, U4.3, U4.9
BAT_INFO: C5.1, R2.1, R8.2, U5.14
CC1: R21.1, USB1.A5
CC2: R24.2, USB1.B5
CH343_RX: R26.1, U4.5
CH343_TX: R25.1, U4.4
Charge_Detect: R4.1, U1.1, U5.17
D+_A6: D1.4, D1.7, SJ5.1, U4.7, USB1.A6
D-_A7: D1.5, D1.6, SJ6.1, U4.8, USB1.A7
DISP_CS: LCD1.8, U5.22
DISP_DC: LCD1.10, U5.24
DISP_RES: LCD1.9, U5.11
DTR: Q3.1, R15.2, U4.12
FB: R17.1, R18.1, U3.10
GND: C1.2, C2.2, C3.2, C4.2, C5.2, C6.2, C7.2, C8.2, C9.2, C11.2, C13.1, C14.2, C15.2, C16.2, C17.2, C18.2, C19.1, C20.2, C21.1, C22.2, C23.2, C24.2, C26.2, D1.3, D1.8, D9.1, FPC1.1, LCD1.7, LCD1.16, P3.3, P5.2, Q2.2, R1.1, R6.1, R8.1, R9.1, R18.2, R19.1, R21.2, R24.1, R32.1, U1.2, U2.5, U2.10, U2.12, U3.3, U3.7, U3.9, U3.11, U3.V:Ex24y24d121, U4.2, U4.17, U5.4, USB1.1, USB1.2, USB1.3, USB1.4, USB1.A1, USB1.A12, USB1.B1, USB1.B12, X1.2
GPIO_ndef: P3.2, U5.25
I2C1_SCL_SPI2_SCK: R30.2, SJ3.1, U5.28
I2C1_SDA_SPI2_MOSI: R29.2, SJ2.1, U5.27
I2C2_SCL: R12.2, U2.4, U5.18
I2C2_SDA: R11.2, U2.6, U5.19
INT: SJ1.2, U5.6
INT1: SJ1.3, U2.11
INT2: SJ1.1, U2.9
KEY1: FPC1.2, U5.10
KEY2: FPC1.3, VD2.3
KEY3: FPC1.4, U5.7
MISO2: P1.4, R13.1
NetC4_1: C4.1, R3.1, U3.6, U3.8
NetC9_1: C9.1, C17.1, R5.1
NetC10_1: C10.1, LCD1.1
NetC10_2: C10.2, LCD1.2
NetC12_1: C12.1, LCD1.3
NetC12_2: C12.2, LCD1.4
NetC15_1: C15.1, LCD1.15
NetC18_1: C18.1, U4.6
NetC25_1: C25.1, LCD1.14
NetC25_2: C25.2, C26.1
NetD2_1: D2.1, R16.1
NetD4_2: D4.2, D5.2, Q3.6
NetD5_1: D5.1, R14.2
NetD7_2: D7.2, D8.1
NetL1_1: L1.1, U3.4
NetL1_2: L1.2, U3.2
NetLCD1_13: LCD1.13, R19.2
NetLED1_2: LED1.2, R4.2
NetQ1_1: Q1.1, Q2.3, R7.1, VD2.1
NetQ3_2: Q3.2, R20.2
NetQ3_3: Q3.3, R16.2
NetQ3_5: Q3.5, R15.1
NetR1_2: R1.2, U1.5
NetR22_2: R22.2, SJ2.2
NetR23_2: R23.2, SJ3.2
NetR27_2: R27.2, X1.3
NetR28_1: R28.1, X1.1
NetR31_2: R31.2, SJ4.2
PA2_TX: R26.2, SJ6.2, U5.8
PA3_RX: R25.2, SJ5.2, U5.9
PC14: R27.1, U5.1
PF2_N_R_S_T_: C14.1, D4.1, R10.1, U5.5
PKEY_OK: U5.15, VD2.2
PW_HOLD: Q2.1, R9.2, U5.12
RTS: R20.1, U4.13
SCL1_SCK2: P1.3, R30.1
SDA1_MOSI2: P1.1, R29.1
SPI1_MOSI: LCD1.12, U5.13
SPI1_SCK: LCD1.11, U5.23
SPI2_MISO: R13.2, SJ4.1, U5.26
SPI2_NSS: P1.2, U5.16
SWCLK_BOOT0: D1.2, D1.9, D2.2, R32.2, U5.21, USB1.B6
SWDIO: D1.1, D1.10, U5.20, USB1.B7
TPS_VOUT: C6.1, C7.1, C24.1, L2.1, R17.2, U3.1
VBAT_IN: C3.1, D7.1, P5.1, Q1.2, R7.2, U1.3
VUSB: F1.1, USB1.A4, USB1.A9, USB1.B4, USB1.B9
VbatWeek: C2.1, C22.1, C23.1, D3.2, D8.2, P3.4, R10.2, U2.1, U2.14, U5.3

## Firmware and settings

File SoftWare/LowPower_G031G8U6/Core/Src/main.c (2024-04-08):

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
/* Includes ------------------------------------------------------------------*/
#include "main.h"

/* USER CODE BEGIN Includes */

#include "WS2812.h"
/* USER CODE END Includes */

RTC_HandleTypeDef hrtc;

TIM_HandleTypeDef htim1;
DMA_HandleTypeDef hdma_tim1_ch1;

void SystemClock_Config(void);
static void MX_GPIO_Init(void);
static void MX_RTC_Init(void);
static void MX_DMA_Init(void);
static void MX_TIM1_Init(void);
/**
  * @brief  The application entry point.
  * @retval int
  */
int main(void)
{
  /* MCU Configuration--------------------------------------------------------*/

  /* Reset of all peripherals, Initializes the Flash interface and the Systick. */
  HAL_Init();

  /* Configure the system clock */
  SystemClock_Config();

  /* Initialize all configured peripherals */
  MX_GPIO_Init();
  MX_RTC_Init();
  MX_DMA_Init();
  MX_TIM1_Init();
  /* USER CODE BEGIN 2 */

	//  HAL_TIM_PWM_Start(&htim2, TIM_CHANNEL_2);
	//  TIM2->CCR2=5;
  /* USER CODE END 2 */

  /* Infinite loop */
  /* USER CODE BEGIN WHILE */
	while (1)
	{
		//	  HAL_GPIO_WritePin(LED_GPIO_Port, LED_Pin, GPIO_PIN_SET);

		//		if(!Power_IsShutdown && powerDebug.chargingInfo) {

		RGB_Updaate();
		HAL_Delay(20);


		//	  HAL_PWR_EnterSTOPMode(PWR_LOWPOWERREGULATOR_ON, PWR_STOPENTRY_WFI);
		//从STOP模式恢复时，程序继续运行剩余代码，�?�不是重新从头开始运�????????????????????

		// reconfigure system clock
		//	  SystemClock_Config();//只需要恢复系统时钟SYSCLK？GPIO时钟在STOP模式下还是开启的
    /* USER CODE END WHILE */

    /* USER CODE BEGIN 3 */
	}
  /* USER CODE END 3 */
}

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
/* USER CODE BEGIN 4 */
void HAL_GPIO_EXTI_Falling_Callback(uint16_t GPIO_Pin)
{
	//	if(GPIO_Pin == BUTTON_Pin)
	//		SystemClock_Config();
}








/* USER CODE END 4 */
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


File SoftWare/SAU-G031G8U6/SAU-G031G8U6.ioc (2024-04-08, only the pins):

Mcu.UserName=STM32G031G8Ux
PA0.GPIO_Label=INT_IMU
PA0.Signal=GPXTI0
PA1.GPIO_Label=KEY_A
PA1.Signal=GPIO_Input
PA13.Signal=SYS_SWDIO
PA14-BOOT0.Signal=SYS_SWCLK
PA15.GPIO_Label=DISP_CS
PA15.Signal=GPIO_Output
PA2.Signal=USART2_TX
PA3.Signal=USART2_RX
PA4.GPIO_Label=KEY_B
PA4.Signal=GPIO_Input
PA5.GPIO_Label=DISP_RES
PA5.Signal=GPIO_Output
PA6.GPIO_Label=PW_HOLD
PA6.Signal=GPIO_Output
PA7.Signal=SPI1_MOSI
PA8.GPIO_Label=RGB_LED
PA8.Signal=S_TIM1_CH1
PB0.GPIO_Label=BAT_INFO
PB0.Signal=ADC1_IN8
PB1.GPIO_Label=KEY_OK
PB1.Signal=GPXTI1
PB3.Signal=SPI1_SCK
PB4.GPIO_Label=DISP_DC
PB4.Signal=GPIO_Output
PB5.GPIO_Label=INT_RTC
PB5.Signal=GPXTI5
PB7.GPIO_Label=SDA1
PB7.Signal=I2C1_SDA
PB8.GPIO_Label=SCL1
PB8.Signal=I2C1_SCL
PC6.GPIO_Label=CHARGE_DETECT
PC6.Signal=GPIO_Input

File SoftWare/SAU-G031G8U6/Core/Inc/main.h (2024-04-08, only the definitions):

#define INT_IMU_Pin GPIO_PIN_0
#define INT_IMU_GPIO_Port GPIOA
#define INT_IMU_EXTI_IRQn EXTI0_1_IRQn
#define KEY_A_Pin GPIO_PIN_1
#define KEY_A_GPIO_Port GPIOA
#define KEY_B_Pin GPIO_PIN_4
#define KEY_B_GPIO_Port GPIOA
#define DISP_RES_Pin GPIO_PIN_5
#define DISP_RES_GPIO_Port GPIOA
#define PW_HOLD_Pin GPIO_PIN_6
#define PW_HOLD_GPIO_Port GPIOA
#define BAT_INFO_Pin GPIO_PIN_0
#define BAT_INFO_GPIO_Port GPIOB
#define KEY_OK_Pin GPIO_PIN_1
#define KEY_OK_GPIO_Port GPIOB
#define KEY_OK_EXTI_IRQn EXTI0_1_IRQn
#define RGB_LED_Pin GPIO_PIN_8
#define RGB_LED_GPIO_Port GPIOA
#define CHARGE_DETECT_Pin GPIO_PIN_6
#define CHARGE_DETECT_GPIO_Port GPIOC
#define SCL2_Pin GPIO_PIN_11
#define SCL2_GPIO_Port GPIOA
#define SDA2_Pin GPIO_PIN_12
#define SDA2_GPIO_Port GPIOA
#define DISP_CS_Pin GPIO_PIN_15
#define DISP_CS_GPIO_Port GPIOA
#define DISP_DC_Pin GPIO_PIN_4
#define DISP_DC_GPIO_Port GPIOB
#define INT_RTC_Pin GPIO_PIN_5
#define INT_RTC_GPIO_Port GPIOB
#define INT_RTC_EXTI_IRQn EXTI4_15_IRQn
#define SDA1_Pin GPIO_PIN_7
#define SDA1_GPIO_Port GPIOB
#define SCL1_Pin GPIO_PIN_8
#define SCL1_GPIO_Port GPIOB
#define HAL_UART_TIMEOUT_VALUE 2	//单位毫秒，必须要再次定义，否则不发�?�接收到的数据了

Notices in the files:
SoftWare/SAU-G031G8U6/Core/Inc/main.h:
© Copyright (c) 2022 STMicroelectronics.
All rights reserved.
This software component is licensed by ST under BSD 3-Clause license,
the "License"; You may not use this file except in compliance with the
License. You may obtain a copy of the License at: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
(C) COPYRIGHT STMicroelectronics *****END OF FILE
